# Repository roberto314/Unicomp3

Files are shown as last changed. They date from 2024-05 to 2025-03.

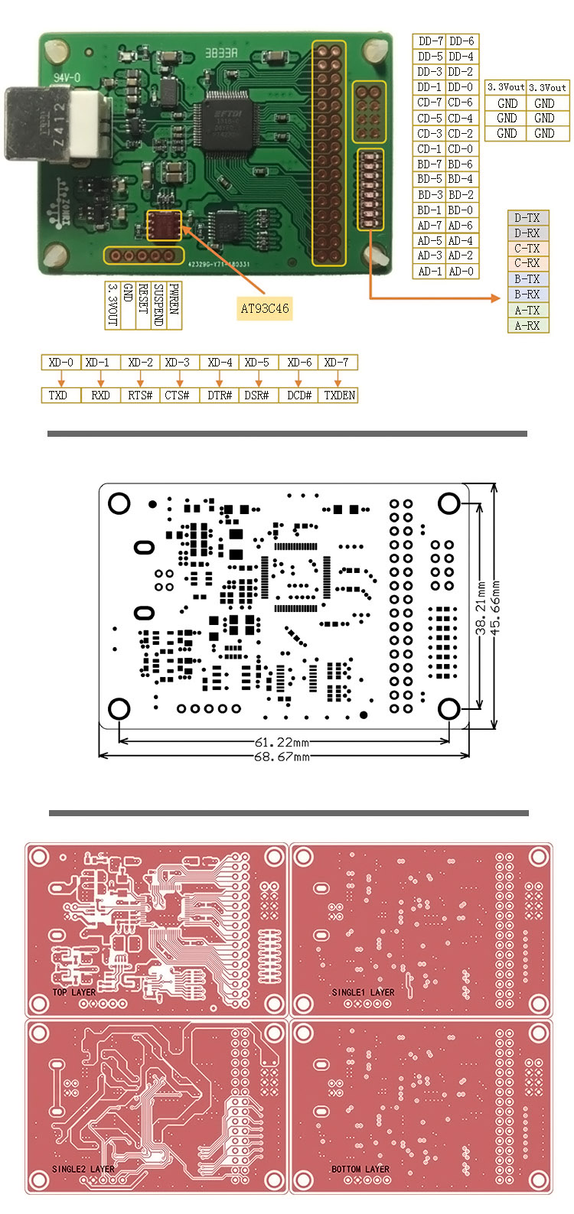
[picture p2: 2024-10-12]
various/Datasheets/FT4232 USB Serial/62949-01.jpg

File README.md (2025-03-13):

# UNICOMP #

Version 3.00

A modular 8-bit Computer able to recreate (nearly) every microcomputer of the mid 70s to early 80s 
in Hardware without FPGAs (although an FPGA can be added). Can also be used as a teaching tool for:

* VHDL or Verilog
* C
* RTOS (STM32F401 runs ChibiOS. Link: https://www.chibios.org)
* Python
* bash and linux in general (Olimex board runs linux with fbterm and tmux)
* Harwaredesign
* Timing of CPUs
* maybe Assembler
* SPI and I2C Interfaces
* CPLDs and FPGAs

It is different from other designs because of these points:

* it uses a 3.3V only Bus,
* it uses fast RAM for 16 chipselect outputs with single address resolution over the whole 1MB range,
* it uses one SRAM for RAM and ROM replacement (can be write writeprotected) with 1MB,
* it uses a clock generator chip (DS1085) - no more crystals to change,
* it is configureable via STM32 (RAM and ROM content, Clock frequency, chip select lines),
* it can program the CPLDs (only XC9572 and XC9536 tested) from the STM32, no external programmer needed.
* Board size is 100mm x 100mm - no backplane (like the PC/104 standard. Link: https://en.wikipedia.org/wiki/PC/104).
* and maybe most convenient: it can change RAM and ROM content on the fly without crashing the CPU. 
  For example starting the Apple I, going into Basic and uploading the program in about half a second is really nice.

Unicomp plus Logic Analyzer:
Unicomp plus Logic analyzer

### Unicomp modules ###

* USB-Serial board:
	- a simple board with an universal 4x USB to UART module from ebay (FT4232).

* CPU board:
	- can be any 8-bit CPU (6502, 6802, 6809, 68008, 6803, 8051,...)
	- a CPLD (XC9572) for clock generation and glue logic

* Multi Serial boaŕd:
	- suggested chip select #0
	- can be used with the following serial interface chips: MC6850, MOS6551, MOS6552 or pin compatible

* Multi Parallel boaŕd:
	- suggested chip select #1
	- can be used with the following parallel interface chips: MC6820, MC6821, MOS6520, MOS6521, MOS6522, MOS6526, MOS8520, MOS6532 in the first slot
    - the first slot can additionally mimic a MOS6530
	- the second slot can accommodate a MOS6522 or pin compatible

* RAMROM board:
	- chip select fixed at #15 (for chipselect RAM or ROM) and #14 for Write Disable (High for ROM),
	- 1M of SRAM plus an extra 16-bit RAM for address decoding,
	- a STM32F401 'blackpill' board to fill the SRAMs with data over USB,
	- USB shell on the STM32 to change ROM content on the fly,
	- also configures the Address Range of all peripheral modules,
	- acts as a XSVF Player to program the CPLDs

* Prototype board:
	- empty board for prototyping
	- no CPLD

* MAX-II (EPM240) board:
	- CPLD plus Buffers

* self made module:
	- chip select can be any non-used line in the Range from 0 to 13.
	- size is 100mm x 100mm
	- there is the prototype board in the repository for the position of the connectors and also the labels (pinout)

### Configuration RAM ###

The configuration is done with 1Mx16 fast ram on the RAMROM board. It is configured from the STM32F401.
The cs = 15 is for writing the main RAM, cs = 14 is the Write Disable.
The rest is free.

### Working Recreations of old computers (tested again with Unicomp3) ###

| Name | prim. IO | chips used | os | weblink |
|---|---|---|---|---|
| Motorola MEK D2 | serial | MC6802, MĆ6850 | newbug, xswtbug, mondeb |Link: https://www.retrotechnology.com/restore/smithbug.html |
| Motorola MEK D1 | serial | MC6802, MĆ6821 (plus Arduino) | Mikbug |Link: https://www.retrotechnology.com/restore/smithbug.html |
| SWTPC 6800 | serial | MC6802, MĆ6821 (plus Arduino) | Mikbug |Link: https://deramp.com/swtpc.com/ |
| SWTPC 6800 | serial | MC6802, MĆ6850 | SWTBUG, SWTBUGA, Mondeb, xSWTBUG |Link: https://deramp.com/swtpc.com/ |
| Heathkit ET3400 | serial | MC6802, MĆ6850 | MITS BASIC, TSC MicroBASIC,... |Link: https://github.com/jefftranter |
| HD6303 Board (Eric Klaus)| serial | HD6303 or MC6803 | Monitor +BASIC |Link: https://sites.google.com/site/ericmklaus/projects-1/hd6303cpuboard |
| MC3 Computer | serial | HD6303 or MC6803 | Monitor |Link: https://www.waveguide.se/?article=mc3-a-diy-8-bit-computer |
| Grant Searle 6809 board  | serial | MC6809E, MC6850 | MS Basic |Link: http://searle.x10host.com/6809/Simple6809.html |
| Grant Searle 6502 board  | serial | MOS6502, MC6850 | OSI Basic |Link: http://searle.x10host.com/6502/Simple6502.html |
| Daryl Rictor 6502 board  | serial | MOS6502, R6551 | SBC-2 (monitor only) |Link: https://sbc.rictor.org/info2.html |
| Daryl Rictor 6502 board  | serial | MOS6502, MC6850 | SBC-2 (monitor only) |Link: https://sbc.rictor.org/info2.html |
| SYM1 | serial | MOS6502, UM6532 | SYM1 ( +BASIC +RAE) |Link: http://retro.hansotten.nl/6502-sbc/synertek-sym-ktm/sym-1/ |
| KIM1 | serial | MOS6502, UM6532 | KIM1 |Link: http://retro.hansotten.nl/6502-sbc/kim-1-manuals-and-software/ |
| Apple I | serial | MOS6502, MĆ6821 (plus Arduino)| Wozmon + BASIC |Link: http://retro.hansotten.nl/6502-sbc/apple-1/ |
| DREAM 6800 | BAS (Video) | MC6802, MAX-II | DREAM operating System (Chip8) |Link: http://www.mjbauer.biz/DREAM6800.htm |
| Psion Organizer I | LCD | HD6303 | Psion OS |Link: https://www.jaapsch.net/psion/index.htm |

### python helper scripts ###

* UC3_upload.py: multi-function script. up- or download RAM Content, write or read the clock chip, set the reset pin, upload configuration data from file, upload RAM data from file, gets version number, 

* UC3_make_uploadfile.py: creates an .ucb file for upload. It can have multiple RAM locations and lengths.

### CPLD programming ###

* compiling the vhdl (or verilog) code must be done on a computer with the Xilinx ISE 14.7 toolchain installed.
 Link: https://www.xilinx.com/support/download/index.html/content/xilinx/en/downloadNav/vivado-design-tools/archive-ise.html

* compiling itself can be done inside ISE or with the supplied makefile (look inside the bord directory in cpld firmware)

* a simple **make** will compile the firmware and a **make prog** will transfer the file to the stm32 for programming.

### Used Software and OS ###

* Linux Mint (21.3 cinnamon) (Link: https://linuxmint.com/)
* Sublime Text 3 (Link: https://www.sublimetext.com/)
* 010 Editor (Hex Editor) (Link: https://www.sweetscape.com/010editor/)
* Chibi Studio 20 (IDE for ChibiOS) (Link: https://www.chibios.org/dokuwiki/doku.php?id=chibios:products:chibistudio:start)
* Wavedrom (2.9.1) (Link: https://wavedrom.com/)
* Pulseview (0.5.0-nightly Appimaage) (Part of sigrok) (Link: https://sigrok.org/wiki/PulseView)
* Logisim-Evolution (3.8.0) (Link: https://github.com/logisim-evolution/logisim-evolution)
* Quartus (13.0.1 Build232 Web Edition - 64 Bit) for MAX-II
* Xilinx ISE (14.7 - 64 Bit) for XC9572

### Used Hardware ###

* Oscilloscope: Rigol DS1054Z (4 channel)
* Logic Analyzer: Hantek 4032L (32 channel)

### History Lesson ###

The unicomp Project started a couple of years ago and is developed in my spare time. It is intended to be a module system to test out different hardware configurations or CPLD- or FPGA- extensions and to recreate old systems and test software and operating systems.

Differences Unicomp2 from Unicomp1:

* chipselect not with CPLD but with RAM on every peripheral board - more flexible,
* chipselect resolution improved to two,

Differences Unicomp3 from Unicomp2:

* chipselect RAM is on RAMROM Board (16-bit wide) - that leads to:
* simpler (and cheaper) peripheral modules,
* no linux SBC needed,
* CPLD programming from STM32 or with external programmer (JTAG Header on every CPU Module)
* 3.3V Supply on RAMROM board,
* RAM has now a backup battery (CR2032) battery,
* improved documentation.

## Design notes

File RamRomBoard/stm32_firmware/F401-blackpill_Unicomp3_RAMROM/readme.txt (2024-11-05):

*****************************************************************************
** ChibiOS/RT port for ARM-Cortex-M4 STM32F407.                            **
*****************************************************************************

** TARGET **

The demo runs on an STM32F411 or STM32F401 blackpill board.
(25MHz Crystal)
Serial Port over USB (also Debug Interface).
Serial 115200 Bd

Build:
Build with eclipse or simply type "make" in the code folder.

Functions:

Pinout:
PA0  - JTAG - TDO
PA1  - /PLD (Parallel Load into Shift Register)
PA2  - TX2 (Console + Debug)
PA3  - RX2 (Console + Debug)
PA4  - /BW (Battery Warning out or Chip Enable in)
PA5  - SCK1
PA6  - MISO1
PA7  - MOSI1
PA8  - DET_SD (SD Card Detect)
PA9  - /STM32BUS
PA10 - /EXTRESET (Reset Target)
PA11 - USD DM (Ostrich)
PA12 - USB DP (Ostrich)
PA13 - SWDIO
PA14 - SWCLK
PA15 - CNT

PB0  - /CEDAT_EN (Enable Data for CE RAM)
PB1  - /MRAM_WR (Write Pulse for Main RAM)
PB2  - /DATOE (Data Output Enable from Main RAM)
PB3  - /MRC (Clear Address Counter)
PB4  - CLK1 - PWM Output (TIM3/1) (Clock 1Hz)
PB5  - /CNTOE (Output Enable for Address Counter)
PB6  - SCL (used for Clock Chip DS1085)
PB7  - SDA (used for Clock Chip DS1085)
PB8  - CTRL1 (CTRL1 for clock chip)
PB9  - /BUSFREE (signal if bus is free)
PB10 - TRST (Target Reset)

PB12 - /CS_SD (SD Card Chipselect)
PB13 - SCK_SD
PB14 - MISO_SD
PB15 - MOSI_SD

PC13 - JTAG - TDI
PC14 - JTAG - TMS
PC15 - JTAG - TCK

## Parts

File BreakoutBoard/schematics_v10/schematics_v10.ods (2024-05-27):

Id | Designator | Footprint | Quantity | Designation | Supplier and ref
21 | U1 | TQFP-44_10x10mm_P0.8mm | 1 | XC9572VQ44
23 | U2 | DIP-14_W7.62mm_Socket | 1 | 74HC14
 |  | Sockets and Headers
1 | J14,J13,J16,J28,J30,J29,J15 | PinHeader_1x01_P2.00mm_Vertical | 7 | .
2 | U4 | DIP-40_W15.24mm_Socket_LongPads | 1 | W65C22NxP
3 | J8,J5 | PinHeader_1x09_P2.54mm_Vertical | 2 | Conn_01x09
4 | J18,J19 | PinHeader_1x32_P2.54mm_Vertical | 2 | Conn_01x32
5 | J1,J4,J2,J3 | PinSocket_2x20_P2.54mm_Vertical | 4 | BUS
6 | J27 | PinHeader_2x05_P2.54mm_Vertical | 1 | .
8 | J12,J9 | PinHeader_1x01_P2.00mm_Vertical | 2 | Conn_01x01
9 | J26 | PinHeader_1x01_P2.00mm_Vertical | 1 | .Conn_01x01
10 | JP3,JP4,JP5,JP6,JP2,JP1 | PinHeader_1x03_P2.54mm_Vertical | 6 | .
13 | J17 | PinHeader_2x11_P2.54mm_Vertical | 1 | Conn_02x11_Odd_Even
14 | J10,J11 | PinHeader_1x06_P2.54mm_Vertical | 2 | .
15 | J20,J21 | PinHeader_1x12_P2.54mm_Vertical | 2 | Conn_01x12
16 | J6,J7 | PinHeader_1x08_P2.54mm_Vertical | 2 | Conn_01x08
20 | U3 | DIP-40_W15.24mm_Socket_LongPads | 1 | 6532
22 | A1 | Arduino_Nano | 1 | Arduino_Nano_v3.x
 |  | R and C
17 | C3,C1,C2,C7,C8,C6 | C_1206_3216Metric | 6 | 100n
19 | C4 | C_1206_3216Metric | 1 | 10n
7 | R1 | R_1206_3216Metric_Pad1.30x1.75mm_HandSolder | 1 | 1k

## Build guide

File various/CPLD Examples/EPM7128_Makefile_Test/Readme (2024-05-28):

Just type make to build and make clean to clean up.
For your own implementation modify the following files:
Makefile Line 8,9 and maybe Line 14 or 15
$(PROJECT)_pins.qsf for the Pin assignments
$(PROJECT).vhd obviously

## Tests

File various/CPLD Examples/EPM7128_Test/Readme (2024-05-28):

Just type make to build and make clean to clean up.
For your own implementation modify the following files:
Makefile Line 8,9,65 and maybe Line 14,15,56
$(PROJECT)_pins.qsf for the Pin assignments
$(PROJECT).vhd obviously

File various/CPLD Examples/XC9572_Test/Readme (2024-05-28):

Just type make to build and make clean to clean up.
For your own implementation modify the following files:
Makefile Line 10 and maybe Line 11,12,31,46,58
$(PROJECT).ucf for the Pin assignments
$(PROJECT).vhd obviously

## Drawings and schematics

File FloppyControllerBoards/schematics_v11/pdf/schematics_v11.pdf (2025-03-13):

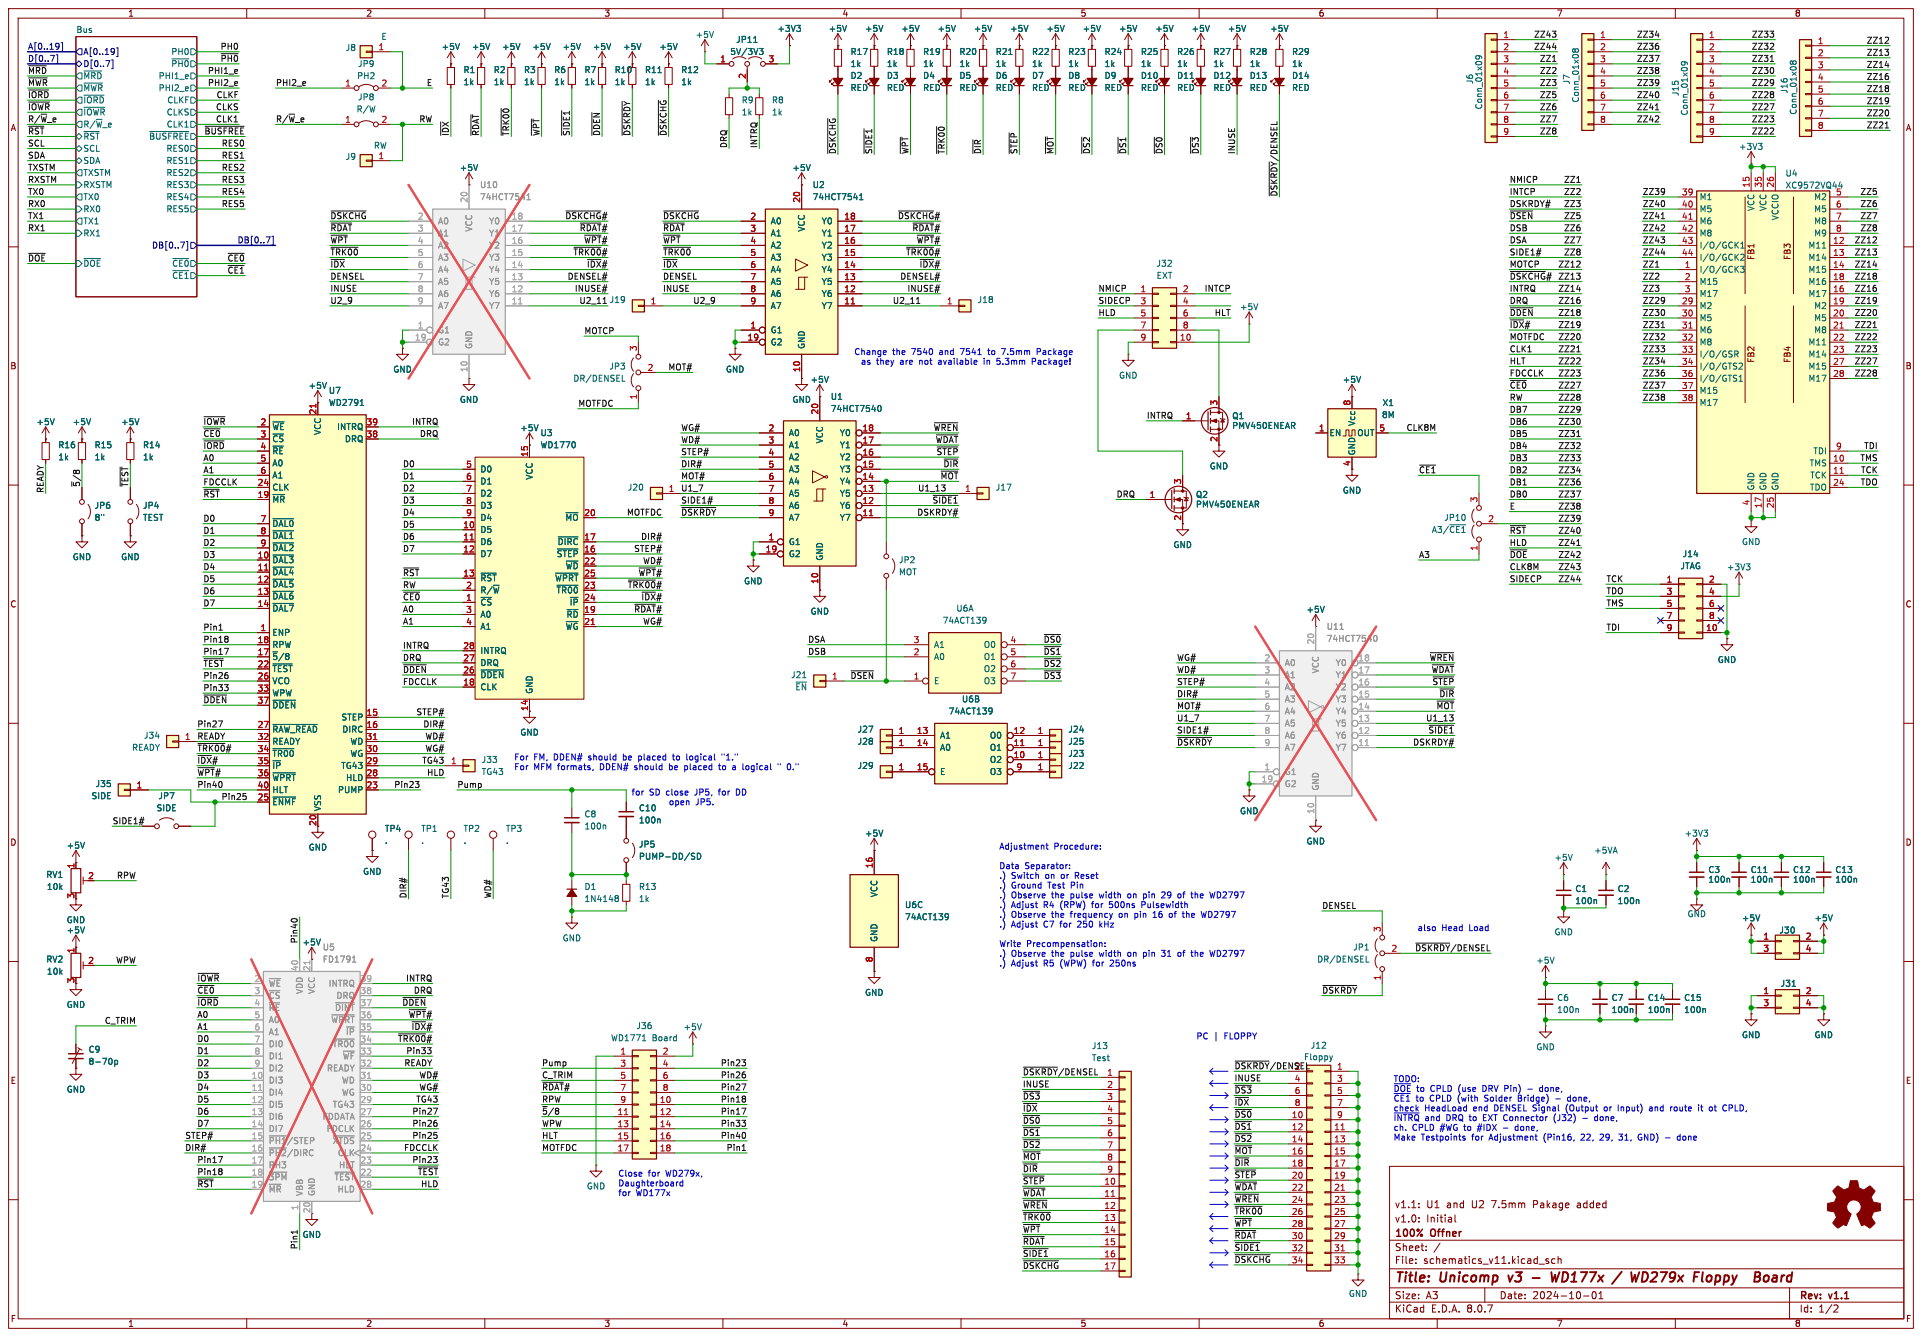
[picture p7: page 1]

4 OUT 5 Vcc 8 GND GND

3 +5V U3 WD1770 ~{CS} 1 D5 10 D6 11 D7 12 ~{RST} 13 GND 14 VCC 15

.) Switch on or Reset
.) Ground Test Pin
.) Observe the pulse width on pin 29 of the WD2797
.) Adjust R4 (RPW) for 500ns Pulsewidth
.) Adjust C7 for 250 kHz Write Precompensation:

1 DI3 10 DI4 11 DI5 12 DI6 13 DI7 14 ~{PH1}/STEP 15 ~{PH2}/DIRC 16 PH3 17 ~{3PM} 18 ~{MR} 19 ~{WE} 2 GND 20 VCC 21 ~{TEST}22 HLT 23 CLK 24 ~{XTDS}25 FDCLK 26 FDDATA 27 HLD 28 TG43 29 ~{CS} 3 WG 30 WD 31 READY 32 ~{WF}33 ~{TR00}34 ~{IP}35 ~{WPRT}36 ~{DINT}37 DRQ 38

.) Observe the pulse width on pin 31 of the WD2797

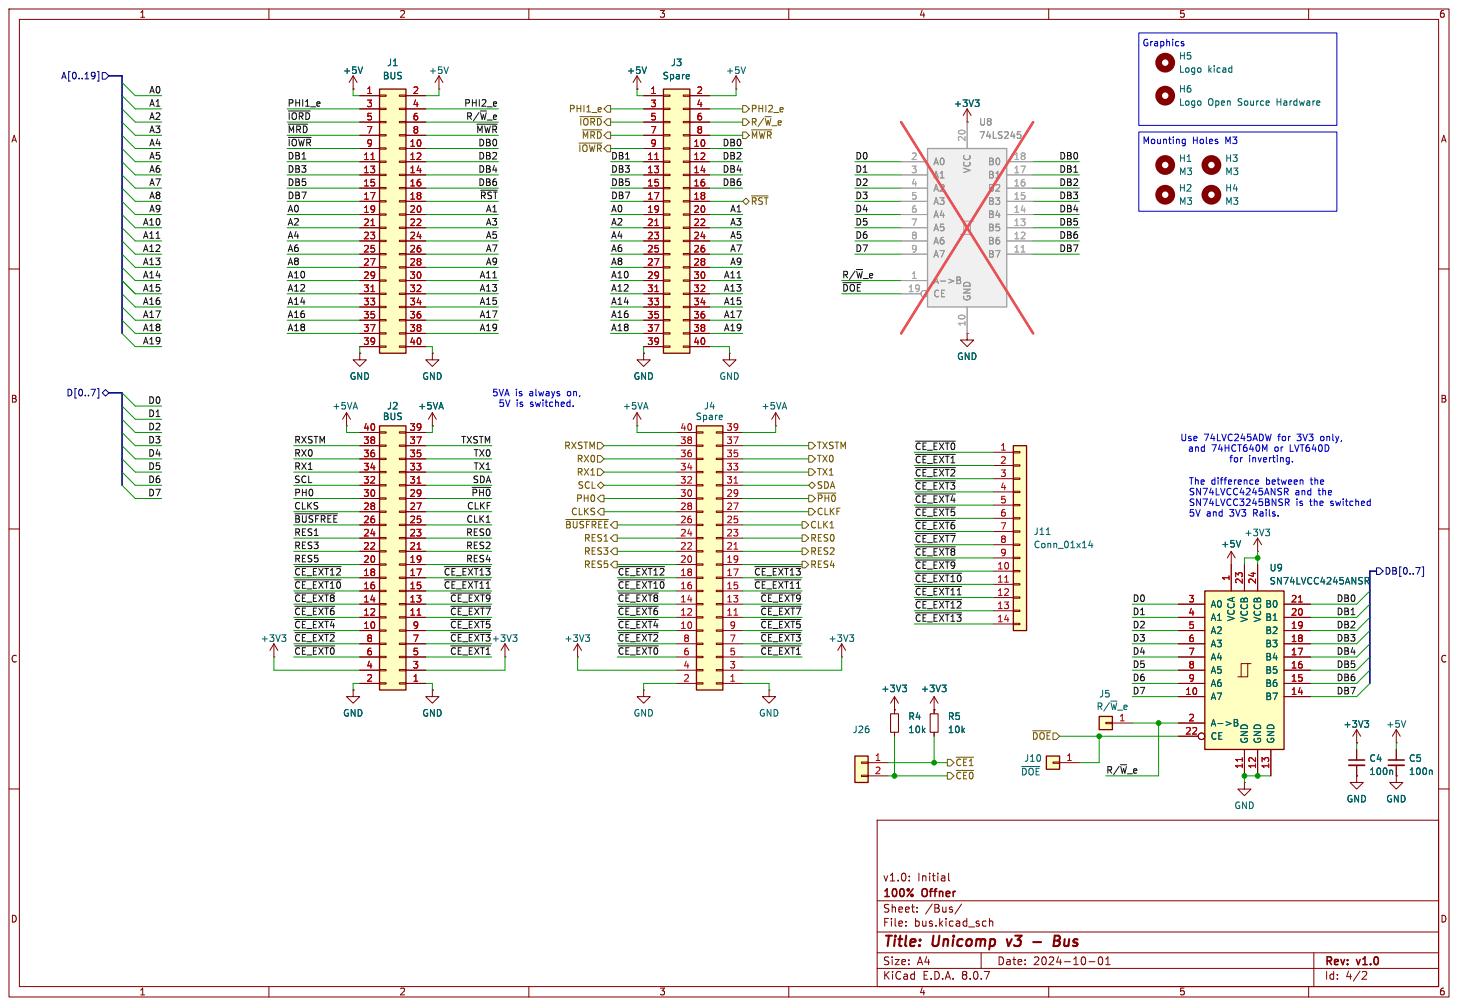
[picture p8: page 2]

Logo Open Source Hardware H5

1 A7 10 GND 11 GND 12 GND 13 B7 14 B6 15 B5 16 B4 17 B3 18 B2 19 A->B 2 B1 20 B0 21 CE 22 VCCB 23 VCCB 24 A0 3 A1 4 A2 5 A3 6 A4 7 A5 8 A6 9 U9SN74LVCC4245ANSR

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

Id: 4/2 Title: Unicomp v3 - Bus

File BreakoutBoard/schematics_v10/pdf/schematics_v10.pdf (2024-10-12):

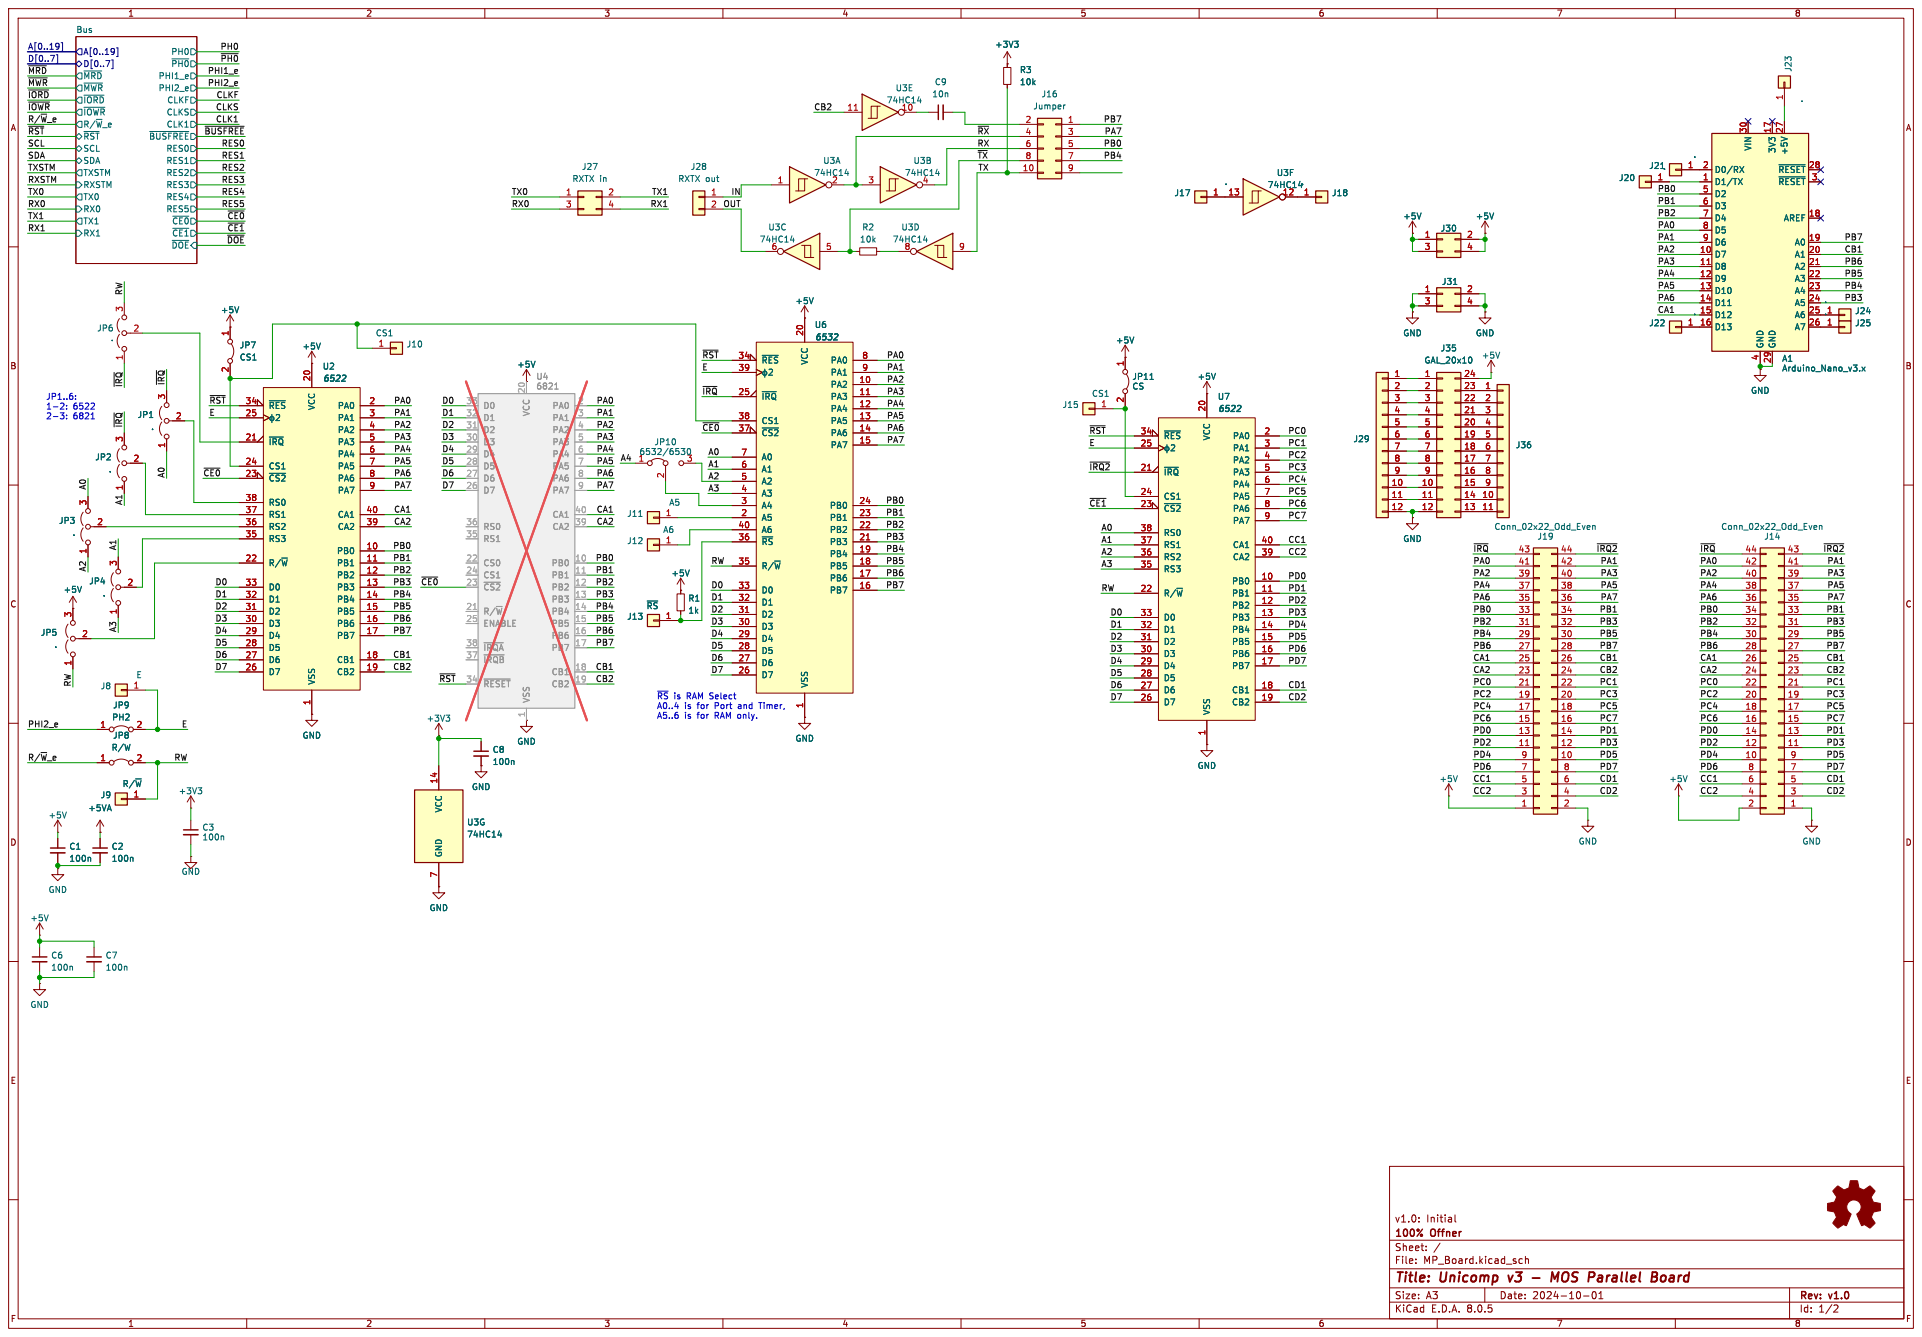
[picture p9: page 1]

1 PA2 10 PA3 11 PA4 12 PA5 13 PA6 14 PA7 15 PB7 16 PB6 17 PB5 18 PB4 19 A5 2 VCC 20 PB3 21 PB2 22 PB1 23 PB0 24 ~{IRQ} 25 D7 26 D6 27 D5 28 D4 29 A4 3 D3 30 D2 31 D1 32 D0 33 ~{RES} 34 R/~{W} 35 ~{RS} 36 ~{CS2} 37 CS1 38

Id: 1/2 Title: Unicomp v3 - MOS Parallel Board

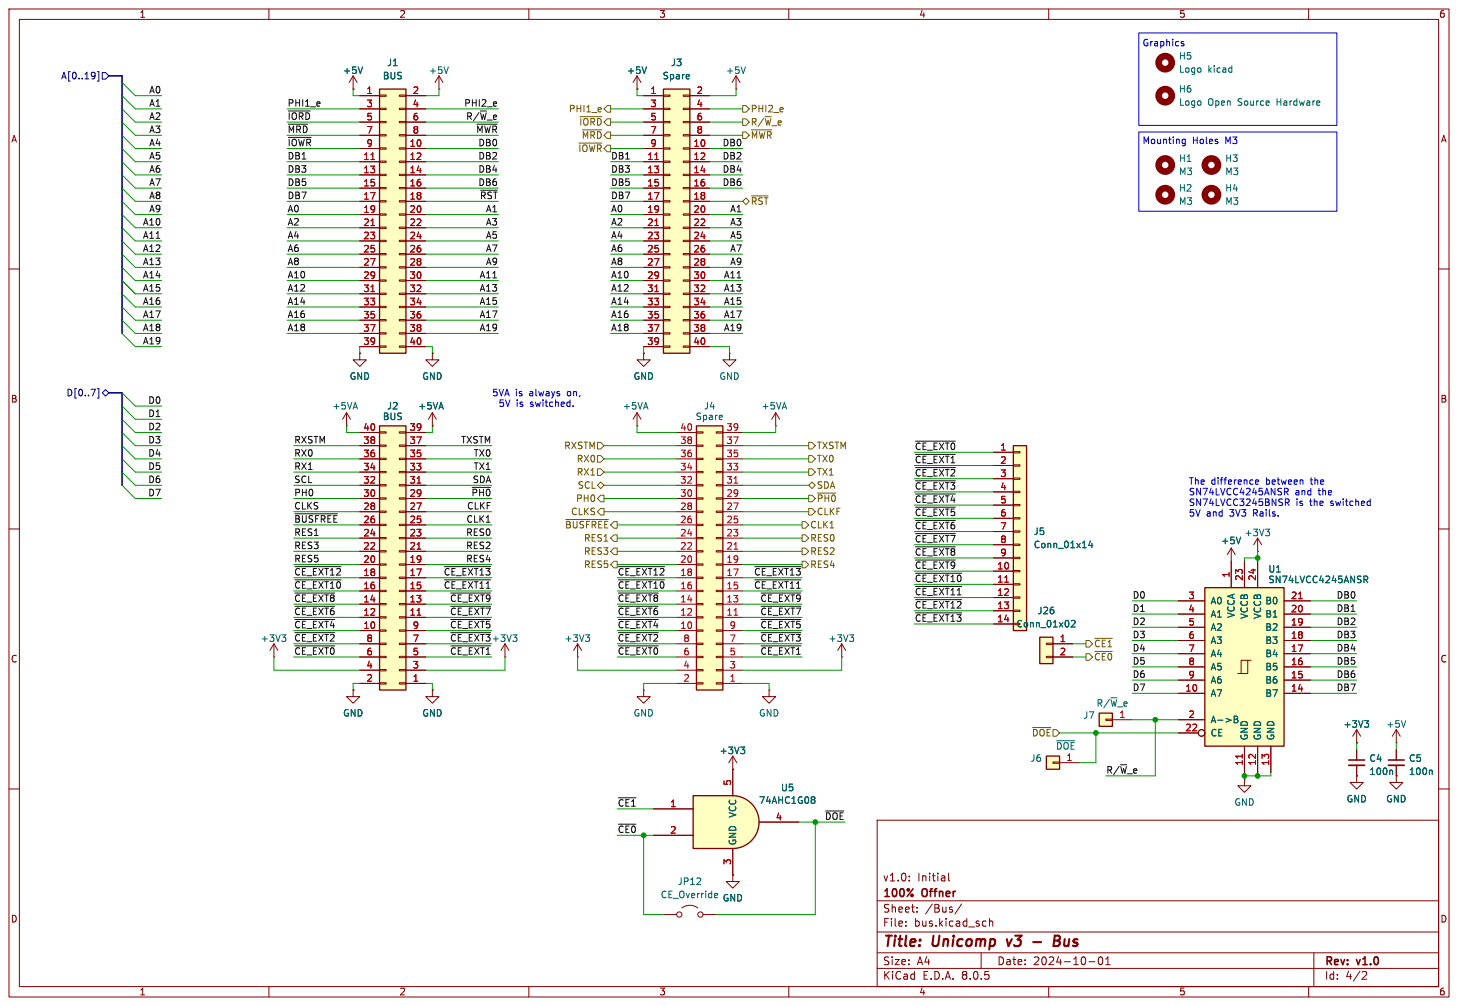
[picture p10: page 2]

Logo Open Source Hardware H5
Logo kicad

1 A7 10 GND 11 GND 12 GND 13 B7 14 B6 15 B5 16 B4 17 B3 18 B2 19 A->B 2 B1 20 B0 21 CE 22 VCCB 23 VCCB 24 A0 3 A1 4 A2 5 A3 6 A4 7 A5 8 A6 9 U1SN74LVCC4245ANSR GND

1 A7 10 GND 11 GND 12 GND 13 B7 14 B6 15 B5 16 B4 17 B3 18 B2 19 A->B 2 B1 20 B0 21 CE 22 VCCB 23 VCCB 24 A0 3 A1 4 A2 5 A3 6 A4 7 A5 8 A6 9 U5

Id: 4/2 Title: Unicomp v3 - Bus

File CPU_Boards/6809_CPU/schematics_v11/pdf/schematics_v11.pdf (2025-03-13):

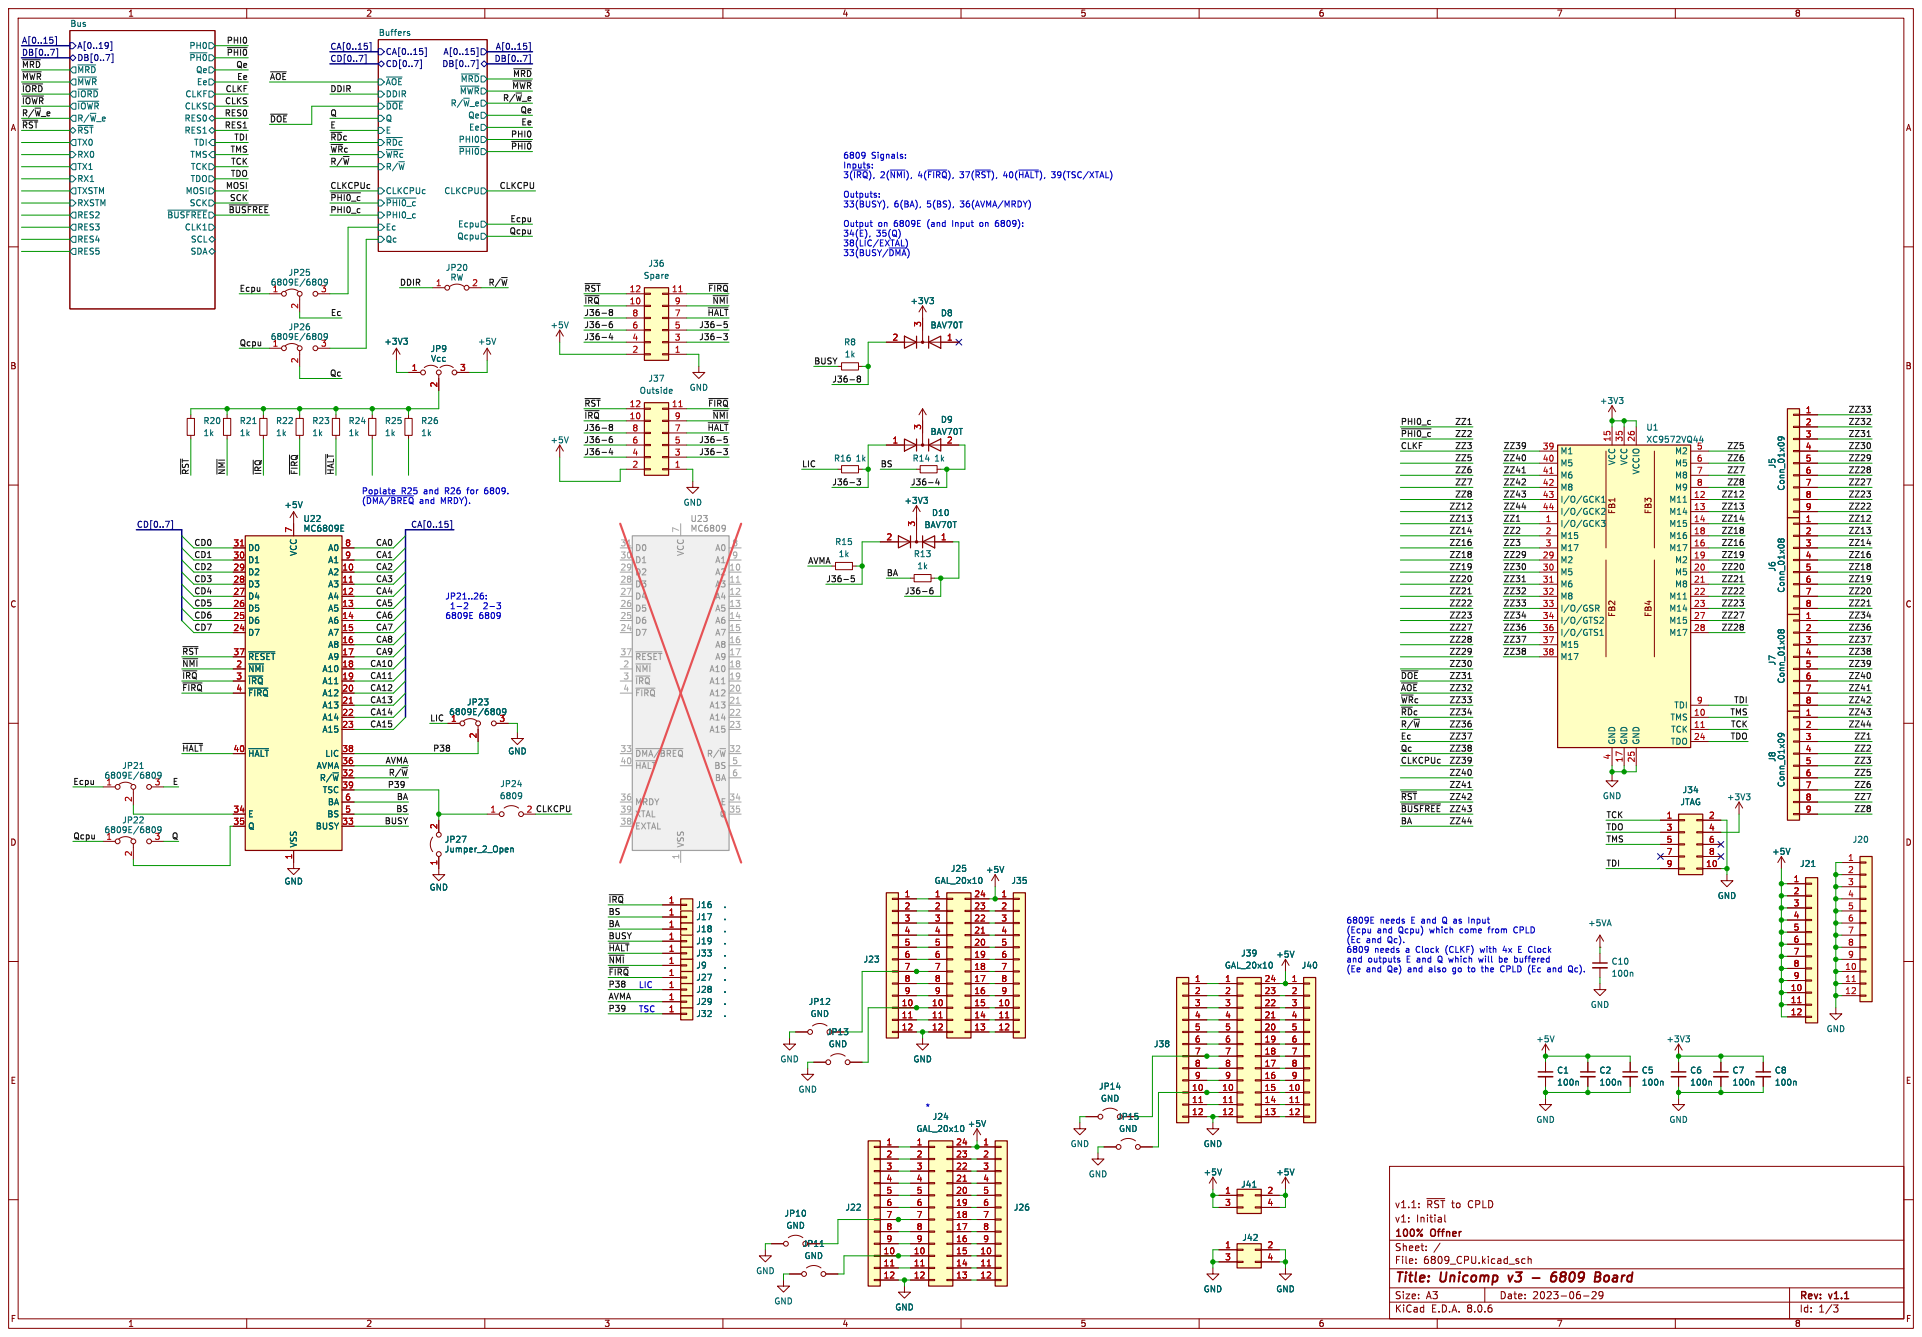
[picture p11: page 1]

6809 Signals:
Inputs:
3(~{IRQ}),2(~{NMI}),4(~{FIRQ}),37(~{RST}),40(~{HALT}),39(TSC/XTAL)

Outputs:
33(BUSY), 6(BA), 5(BS), 36(AVMA/MRDY)

Output on 6809E (and Input on 6809):
38(LIC/EXTAL)
33(BUSY/~{DMA})

1 A2 10 A3 11 A4 12 A5 13 A6 14 A7 15 A8 16 A9 17 A10 18 A11 19 ~{NMI} 2 A12 20 A13 21 A14 22 A15 23 D7 24 D6 25 D5 26 D4 27 D3 28 D2 29 ~{IRQ} 3 D1 30 D0 31 R/~{W}32 ~{DMA/BREQ} 33 E

6809E needs E and Q as Input
(Ecpu and Qcpu) which come from CPLD
(Ec and Qc). 6809 needs a Clock (CLKF) with 4x E Clock and outputs E and Q which will be buffered

(Ee and Qe) and also go to the CPLD (Ec and Qc).

Id: 1/3 Title: Unicomp v3 - 6809 Board

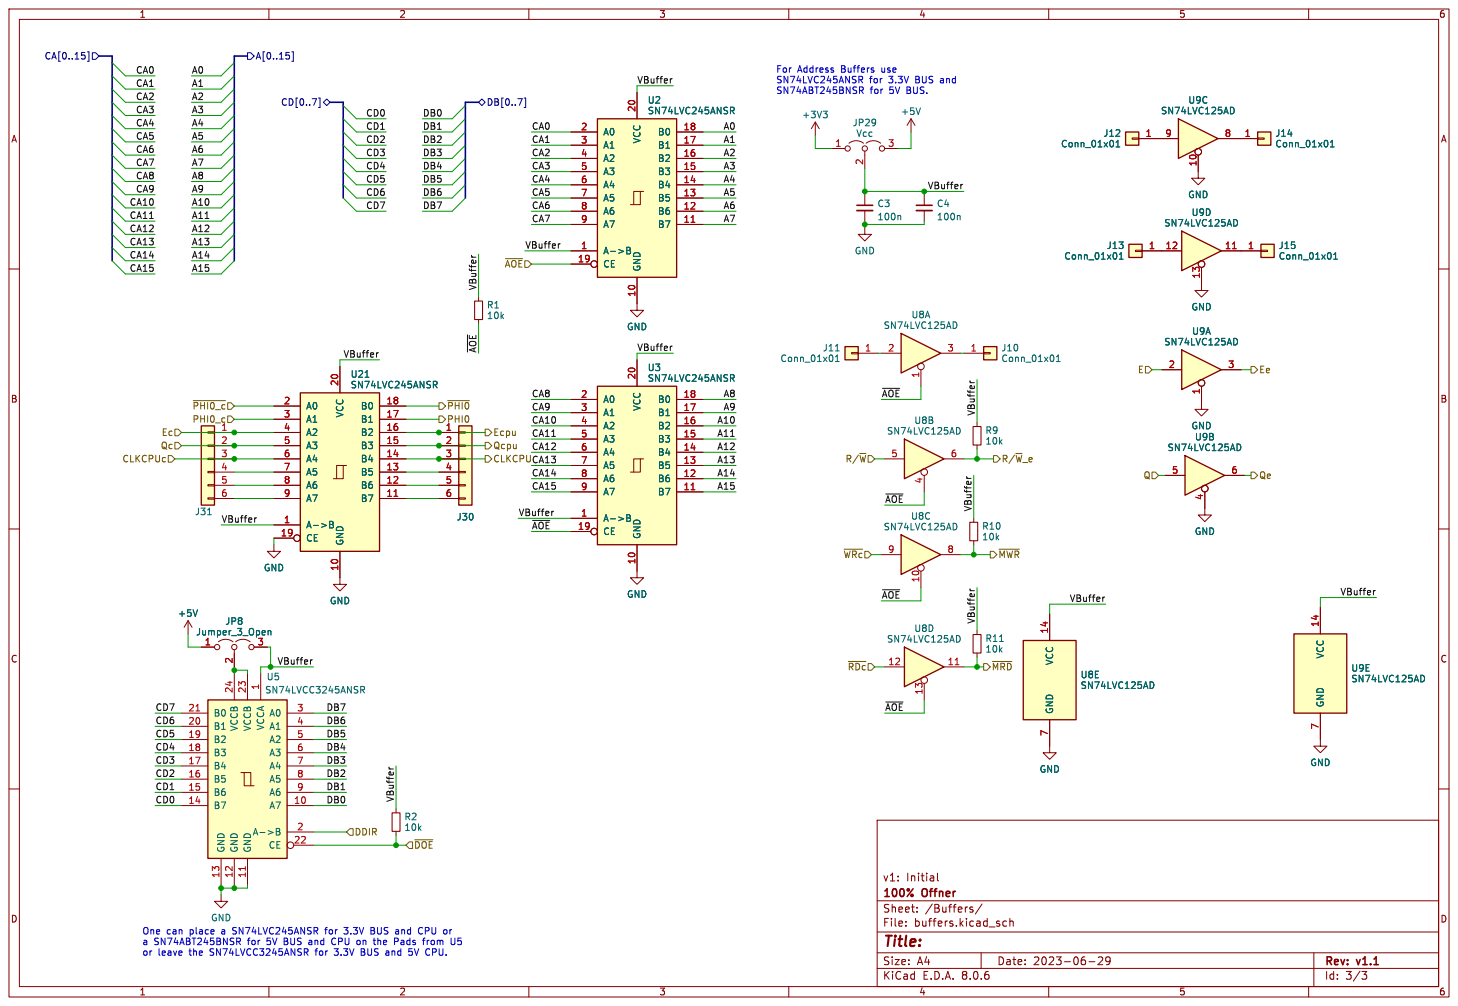
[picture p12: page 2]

1 A7 10 GND 11 GND 12 GND 13 B7 14 B6 15 B5 16 B4 17 B3 18 B2 19 A->B 2 B1 20 B0 21 CE 22 VCCB 23 VCCB 24 A0 3 A1 4 A2 5 A3 6 A4 7 A5 8 A6 9 U5 SN74LVCC3245ANSR

One can place a SN74LVC245ANSR for 3.3V BUS and CPU or a SN74ABT245BNSR for 5V BUS and CPU on the Pads from U5

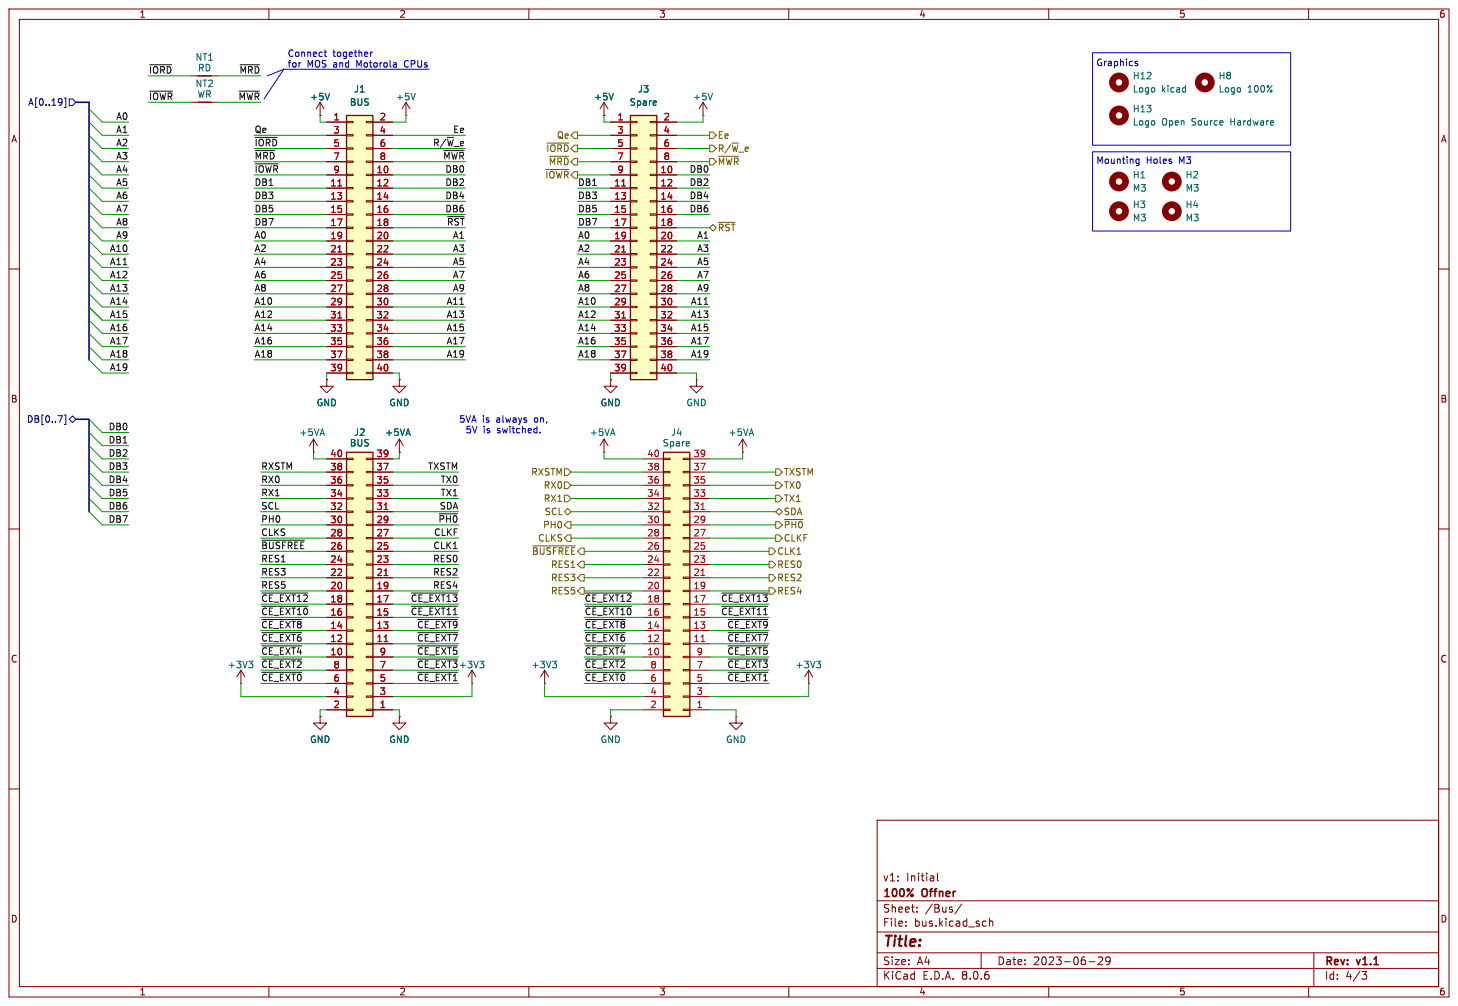
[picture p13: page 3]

Logo Open Source Hardware NT2 WR

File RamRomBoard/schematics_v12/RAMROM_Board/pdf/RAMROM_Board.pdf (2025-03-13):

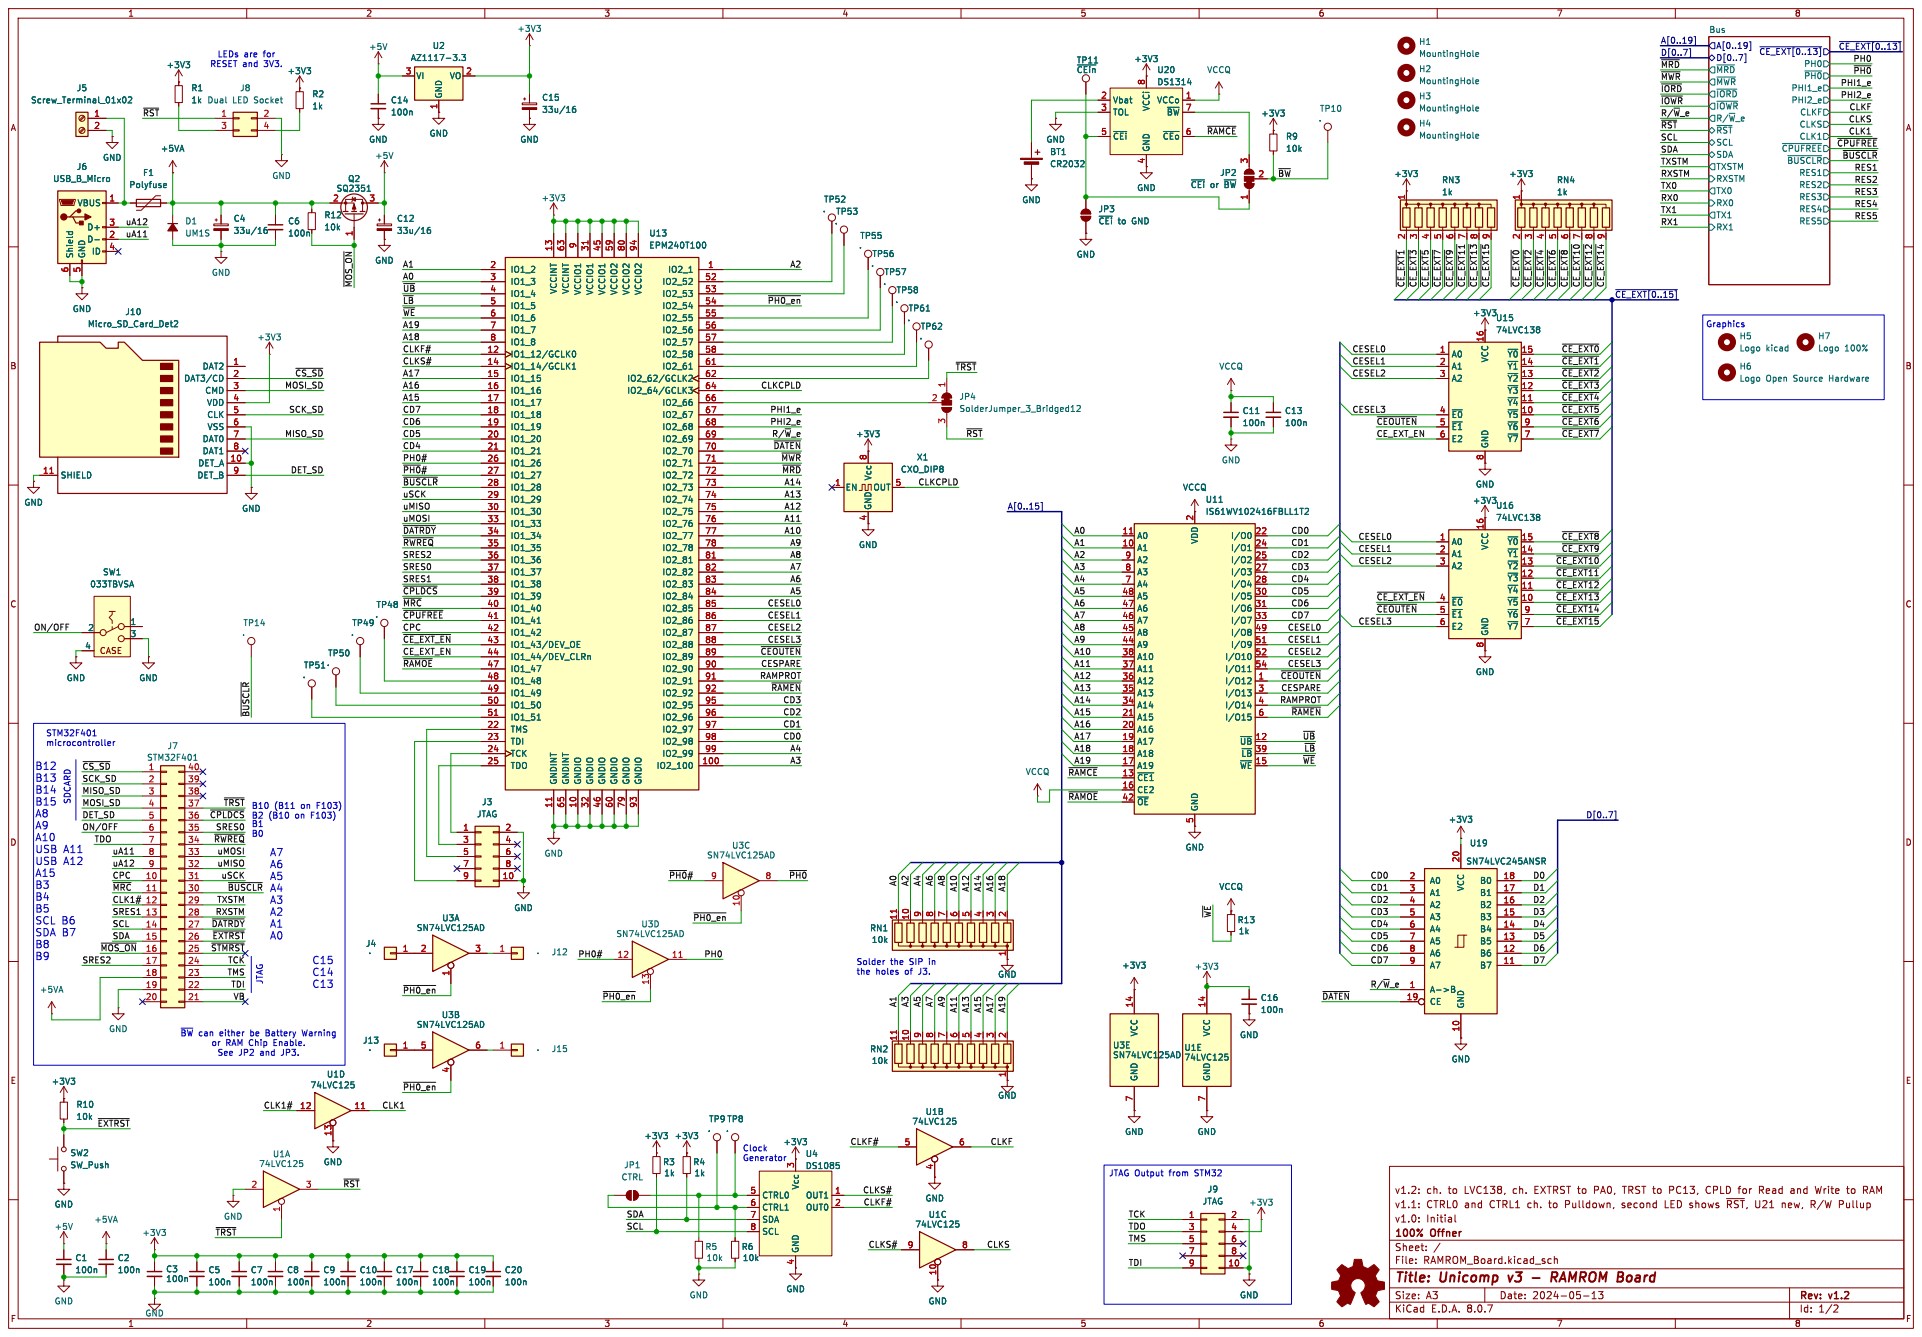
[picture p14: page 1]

J8 Dual LED Socket +3V3 F1 Polyfuse
+3V3 GND

LEDs are for RESET and 3V3.

4 ~{CEi} 5 ~{CEo}6 ~{BW} VCCi 7

JP2 ~{CEi}or ~{BW} JP3 ~{CEi}to GND

2 GND GND GND GND

Solder the SIP in

~{BW}can either be Battery Warning

Id: 1/2 Title: Unicomp v3 - RAMROM Board

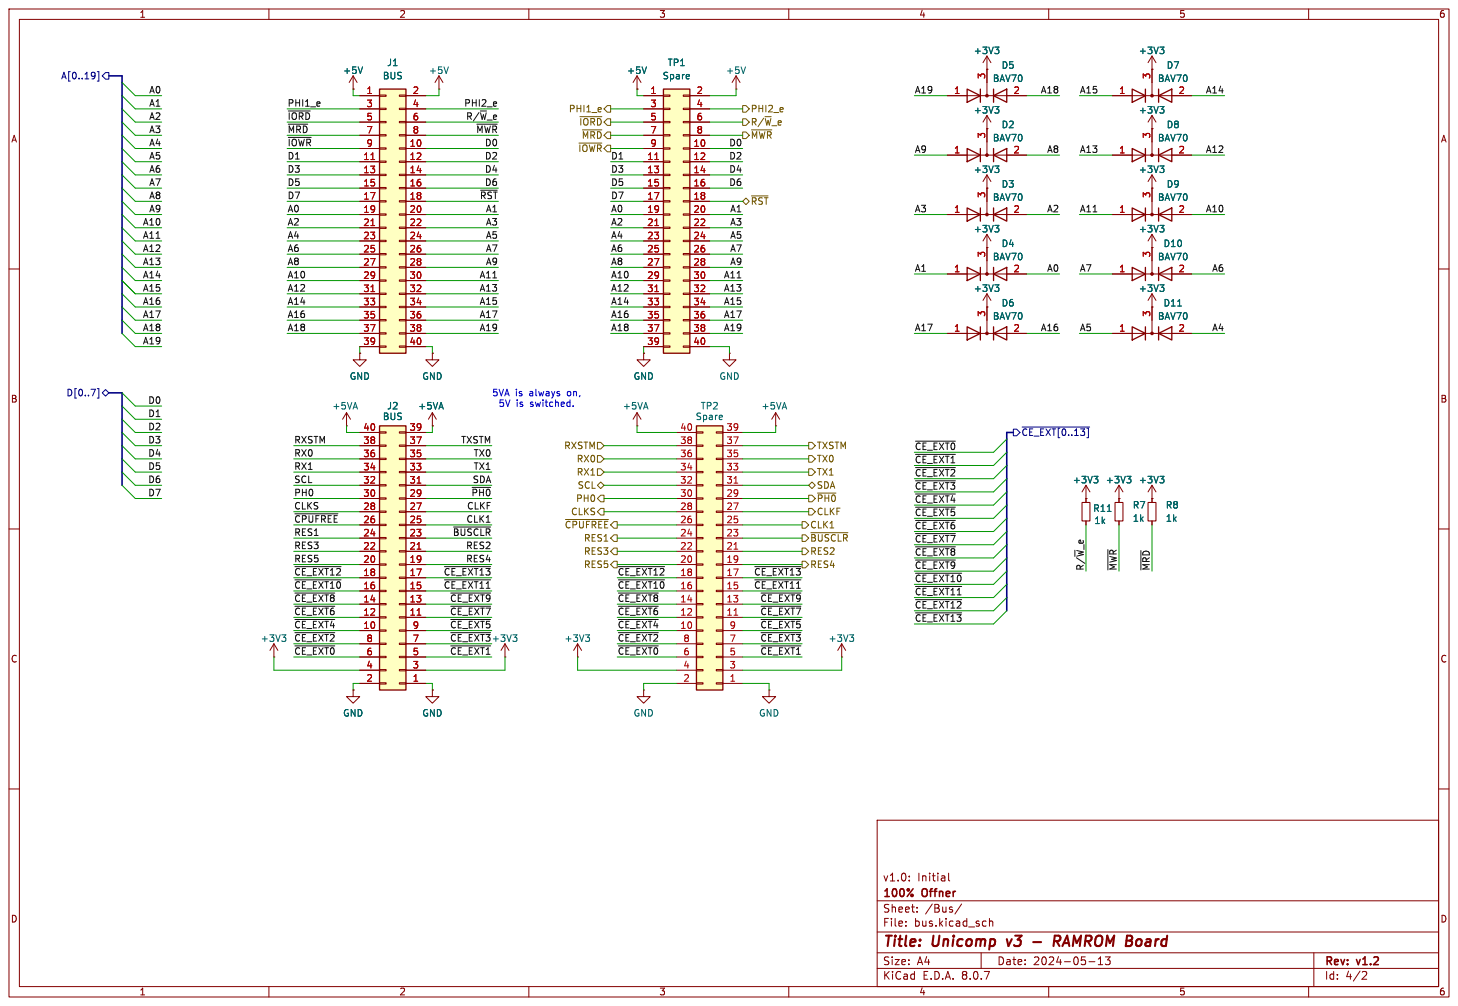
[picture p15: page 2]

Id: 4/2 Title: Unicomp v3 - RAMROM Board

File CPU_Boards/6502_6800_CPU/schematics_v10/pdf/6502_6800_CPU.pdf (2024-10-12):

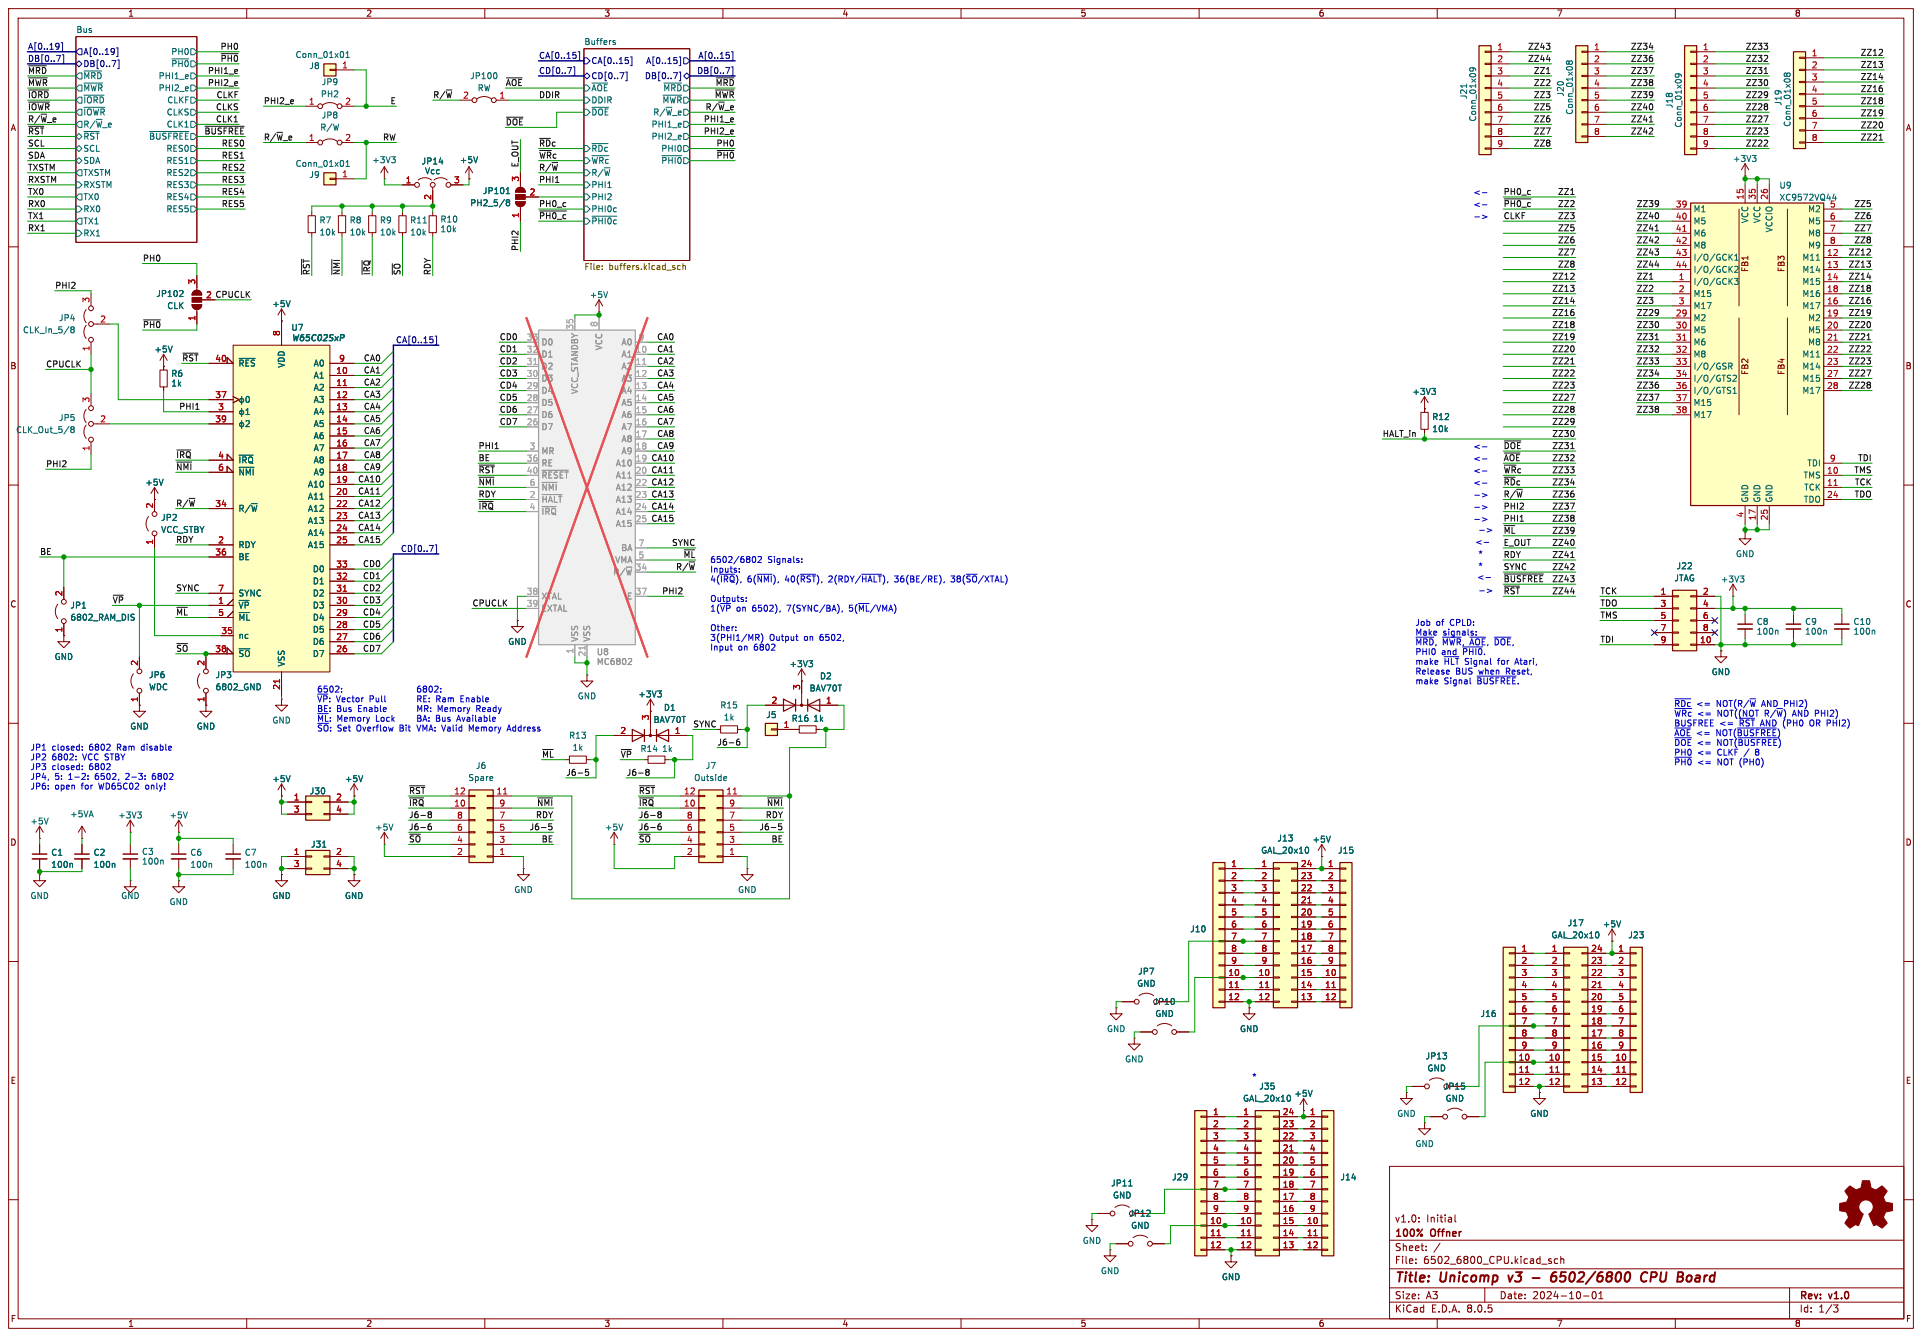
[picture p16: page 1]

1 A1 10 A2 11 A3 12 A4 13 A5 14 A6 15 A7 16 A8 17 A9 18 A10 19 ~{HALT} 2 A11 20 VSS 21 A12 22 A13 23 A14 24 A15 25 D7 26 D6 27 D5 28 D4 29 MR 3 D3 30 D2 31 D1 32 D0 33 R/~{W}34 VCC_STANDBY 35 RE 36 E

Job of CPLD: Make signals:

~{MRD},~{MWR},~{AOE},~{DOE}, PHI0 and ~{PHI0}. make ~{HLT}Signal for Atari, Release BUS when Reset, make Signal ~{BUSFREE}. JP1 closed: 6802 Ram disable

6802: RE: Ram Enable MR: Memory Ready BA: Bus Available VMA: Valid Memory Address

~{WRc}<= NOT((NOT R/~{W})AND PHI2) BUSFREE <= ~{RST}AND (PH0 OR PHI2)

~{AOE}<= NOT(~{BUSFREE})
~{DOE}<= NOT(~{BUSFREE}) PH0 <= CLKF / 8 ~{PH0}<= NOT (PH0)

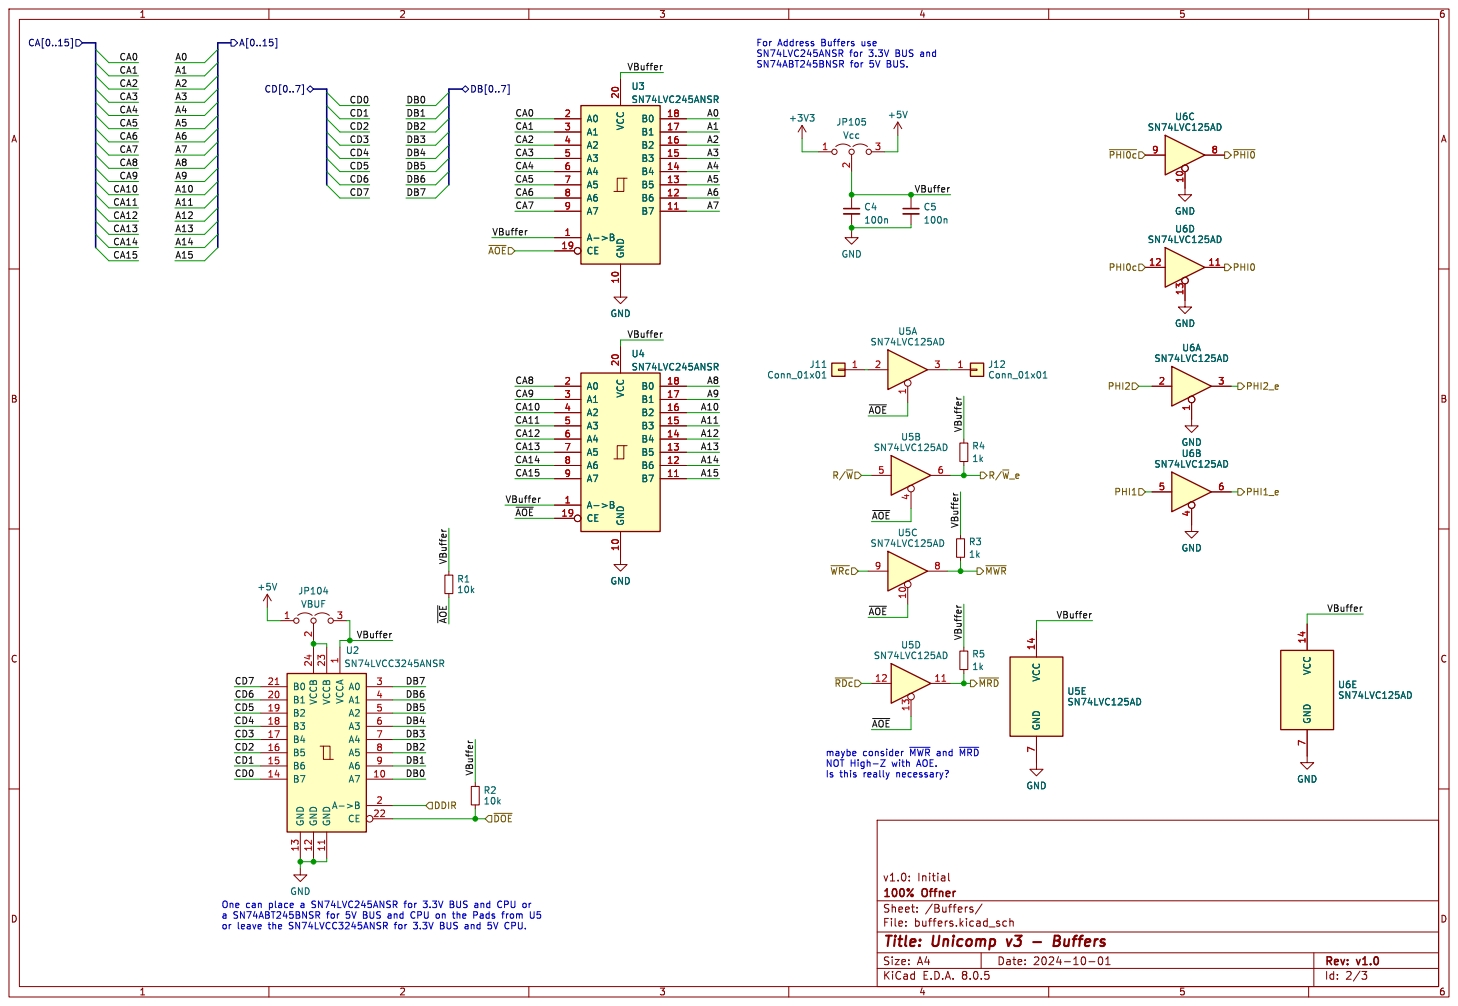
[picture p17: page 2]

For Address Buffers use SN74LVC245ANSR for 3.3V BUS and SN74ABT245BNSR for 5V BUS. U3SN74LVC245ANSR

1 A7 10 GND 11 GND 12 GND 13 B7 14 B6 15 B5 16 B4 17 B3 18 B2 19 A->B 2 B1 20 B0 21 CE 22 VCCB 23 VCCB 24 A0 3 A1 4 A2 5 A3 6 A4 7 A5 8 A6 9 U2 SN74LVCC3245ANSR

Is this really necessary? One can place a SN74LVC245ANSR for 3.3V BUS and CPU or a SN74ABT245BNSR for 5V BUS and CPU on the Pads from U5

Id: 2/3 Title: Unicomp v3 - Buffers

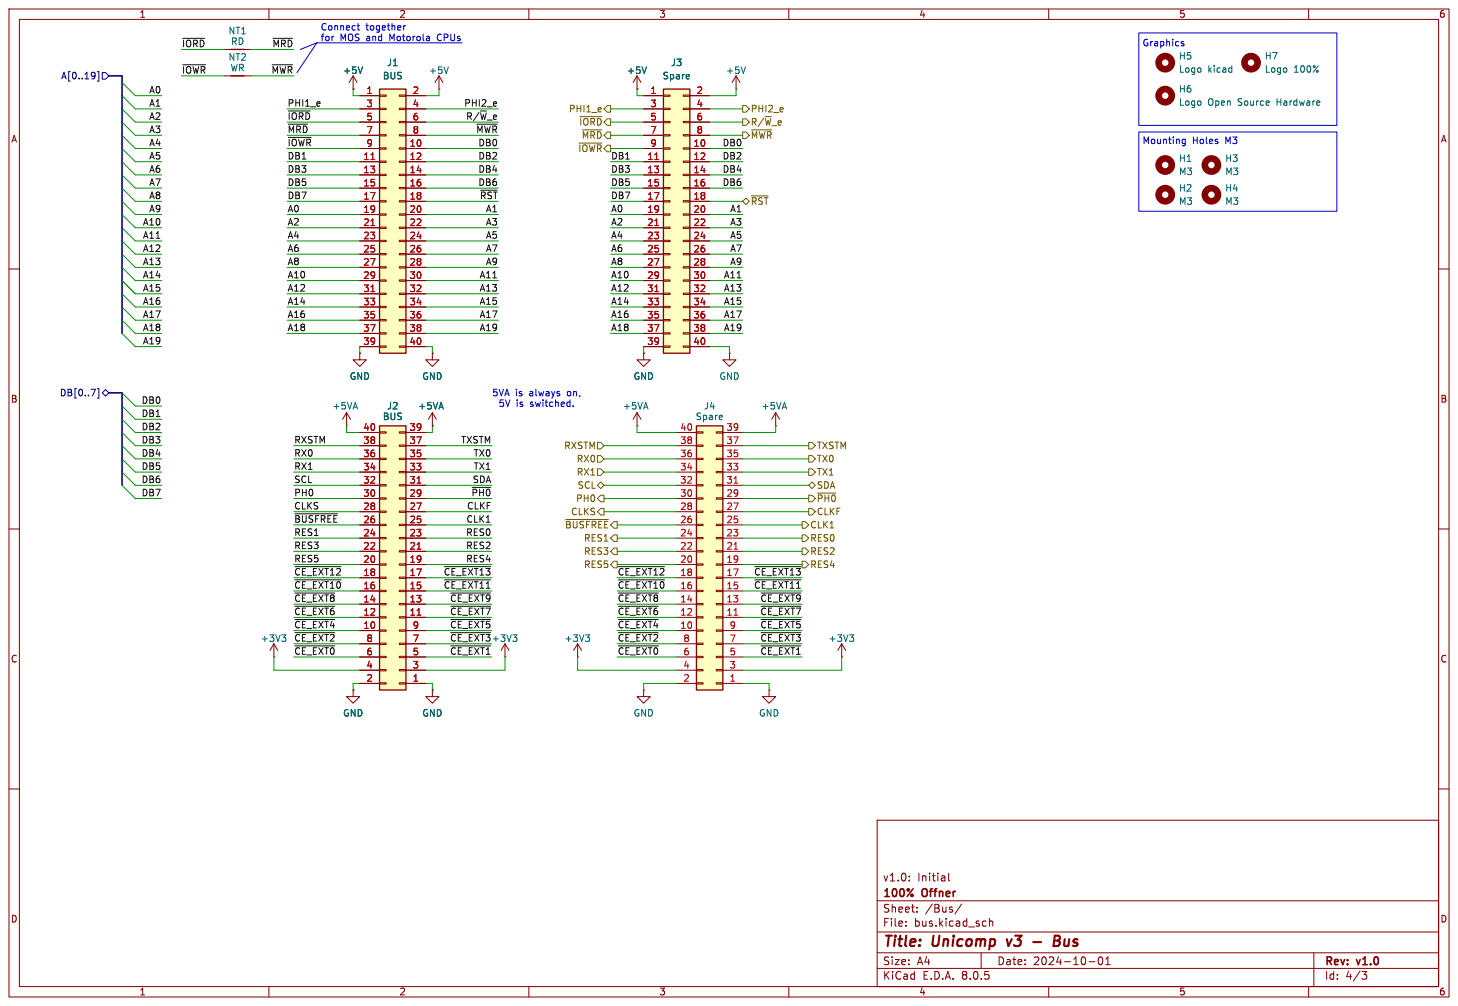
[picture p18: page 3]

Id: 4/3 Title: Unicomp v3 - Bus

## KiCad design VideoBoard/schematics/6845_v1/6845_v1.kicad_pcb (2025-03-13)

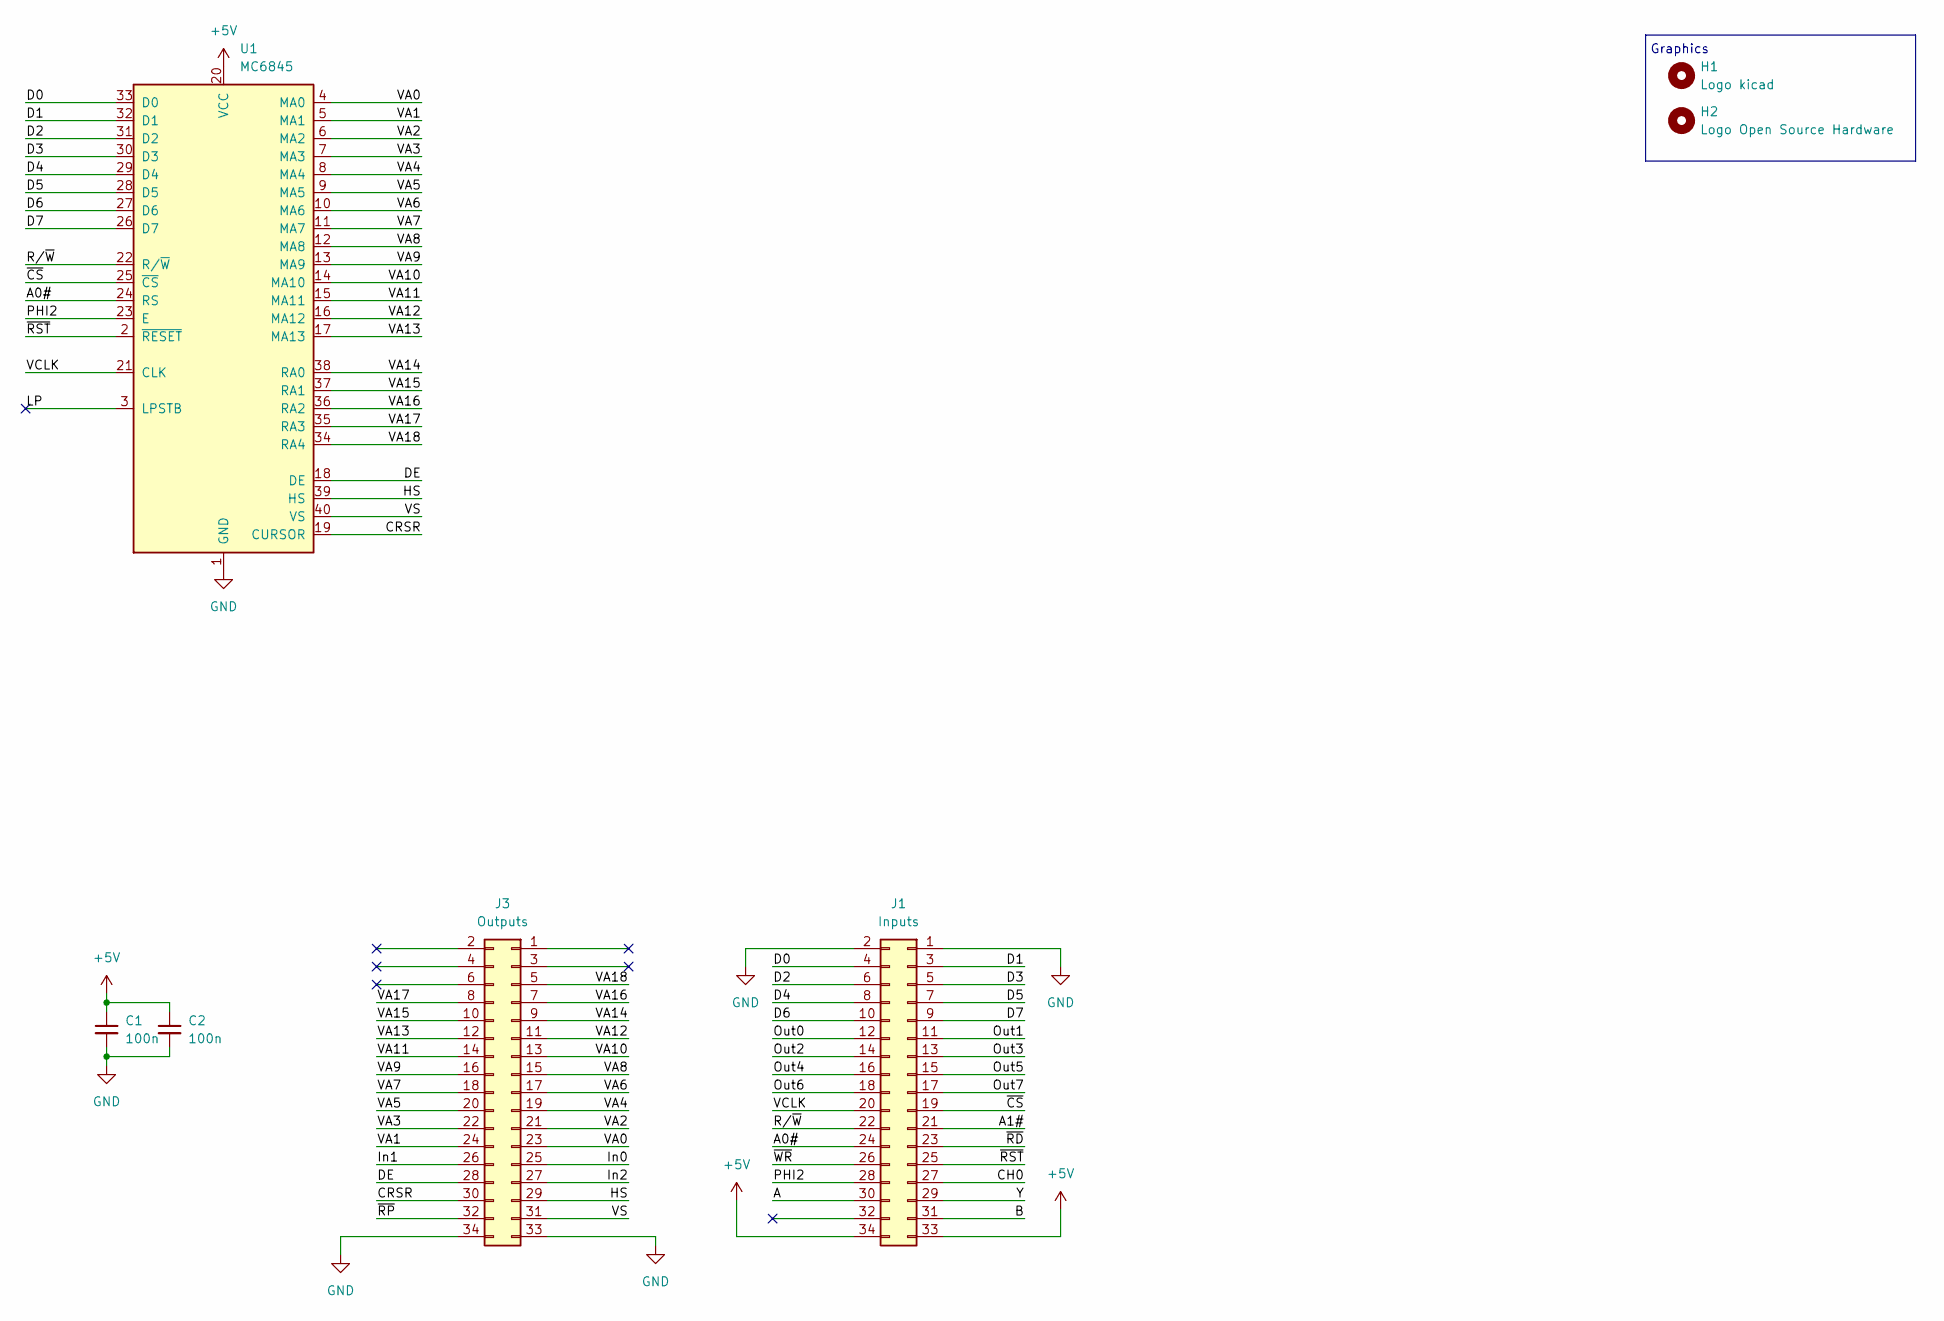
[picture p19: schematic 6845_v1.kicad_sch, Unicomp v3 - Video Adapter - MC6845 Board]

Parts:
C1, C2: 100n; C_1206_3216Metric_Pad1.33x1.80mm_HandSolder
H1: Logo kicad; KiCad-Logo2_6mm_SilkScreen
H2: Logo Open Source Hardware; OSHW-Logo2_7.3x6mm_SilkScreen
J1: Inputs; PinHeader_2x17_P2.54mm_Vertical
J3: Outputs; PinHeader_2x17_P2.54mm_Vertical
U1: MC6845; DIP-40_W15.24mm

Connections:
+5V: C1.1, C2.1, J1.33, J1.34, U1.20 (VCC)
/A: J1.30
/A0#: J1.24, U1.24 (RS)
/A1#: J1.21
/B: J1.31
/CH0: J1.27
/CRSR: J3.30, U1.19 (CURSOR)
/D0: J1.4, U1.33 (D0)
/D1: J1.3, U1.32 (D1)
/D2: J1.6, U1.31 (D2)
/D3: J1.5, U1.30 (D3)
/D4: J1.8, U1.29 (D4)
/D5: J1.7, U1.28 (D5)
/D6: J1.10, U1.27 (D6)
/D7: J1.9, U1.26 (D7)
/DE: J3.28, U1.18 (DE)
/HS: J3.29, U1.39 (HS)
/In0: J3.25
/In1: J3.26
/In2: J3.27
/LP: U1.3 (LPSTB)
/Out0: J1.12
/Out1: J1.11
/Out2: J1.14
/Out3: J1.13
/Out4: J1.16
/Out5: J1.15
/Out6: J1.18
/Out7: J1.17
/PHI2: J1.28, U1.23 (E)
/R/~W: J1.22, U1.22 (R/~W)
/VA0: J3.23, U1.4 (MA0)
/VA1: J3.24, U1.5 (MA1)
/VA2: J3.21, U1.6 (MA2)
/VA3: J3.22, U1.7 (MA3)
/VA4: J3.19, U1.8 (MA4)
/VA5: J3.20, U1.9 (MA5)
/VA6: J3.17, U1.10 (MA6)
/VA7: J3.18, U1.11 (MA7)
/VA8: J3.15, U1.12 (MA8)
/VA9: J3.16, U1.13 (MA9)
/VA10: J3.13, U1.14 (MA10)
/VA11: J3.14, U1.15 (MA11)
/VA12: J3.11, U1.16 (MA12)
/VA13: J3.12, U1.17 (MA13)
/VA14: J3.9, U1.38 (RA0)
/VA15: J3.10, U1.37 (RA1)
/VA16: J3.7, U1.36 (RA2)
/VA17: J3.8, U1.35 (RA3)
/VA18: J3.5, U1.34 (RA4)
/VCLK: J1.20, U1.21 (CLK)
/VS: J3.31, U1.40 (VS)
/Y: J1.29
/~CS: J1.19, U1.25 (~CS)
/~RD: J1.23
/~RP: J3.32
/~RST: J1.25, U1.2 (~RESET)
/~WR: J1.26
GND: C1.2, C2.2, J1.1, J1.2, J3.33, J3.34, U1.1 (GND)

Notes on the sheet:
Graphics

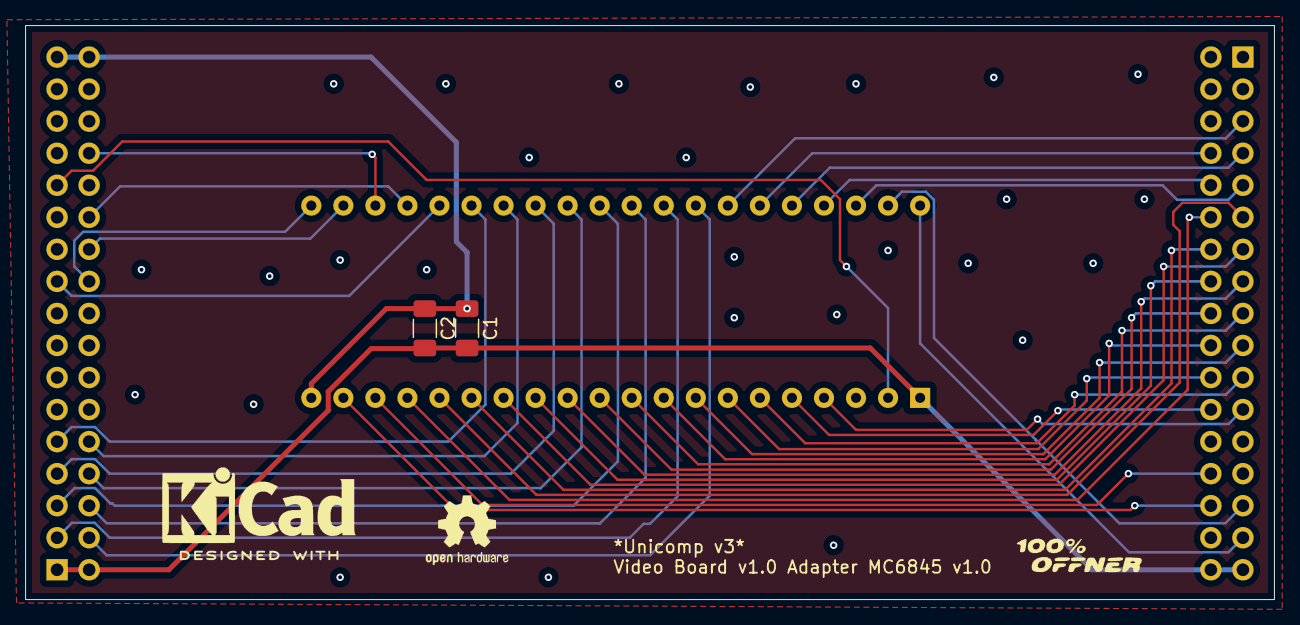
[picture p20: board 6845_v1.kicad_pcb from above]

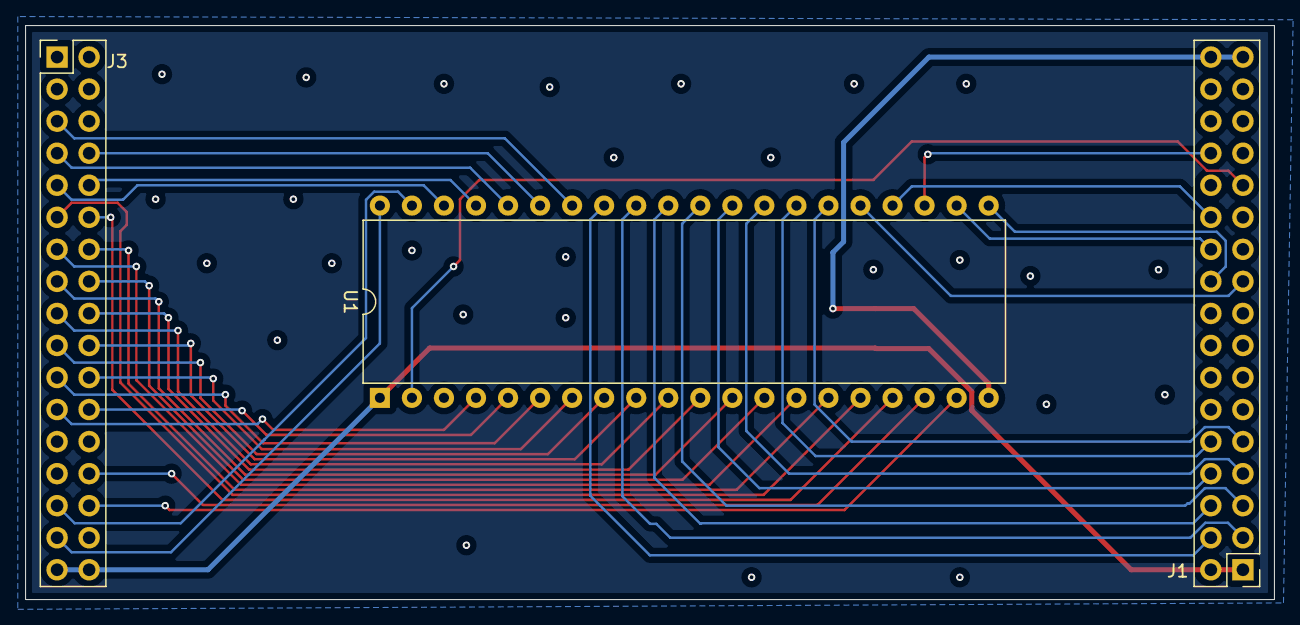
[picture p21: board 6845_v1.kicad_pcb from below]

Board: 2 copper layers, 99.0 x 45.5 mm, 7 parts (3 on the bottom side), 39 nets.

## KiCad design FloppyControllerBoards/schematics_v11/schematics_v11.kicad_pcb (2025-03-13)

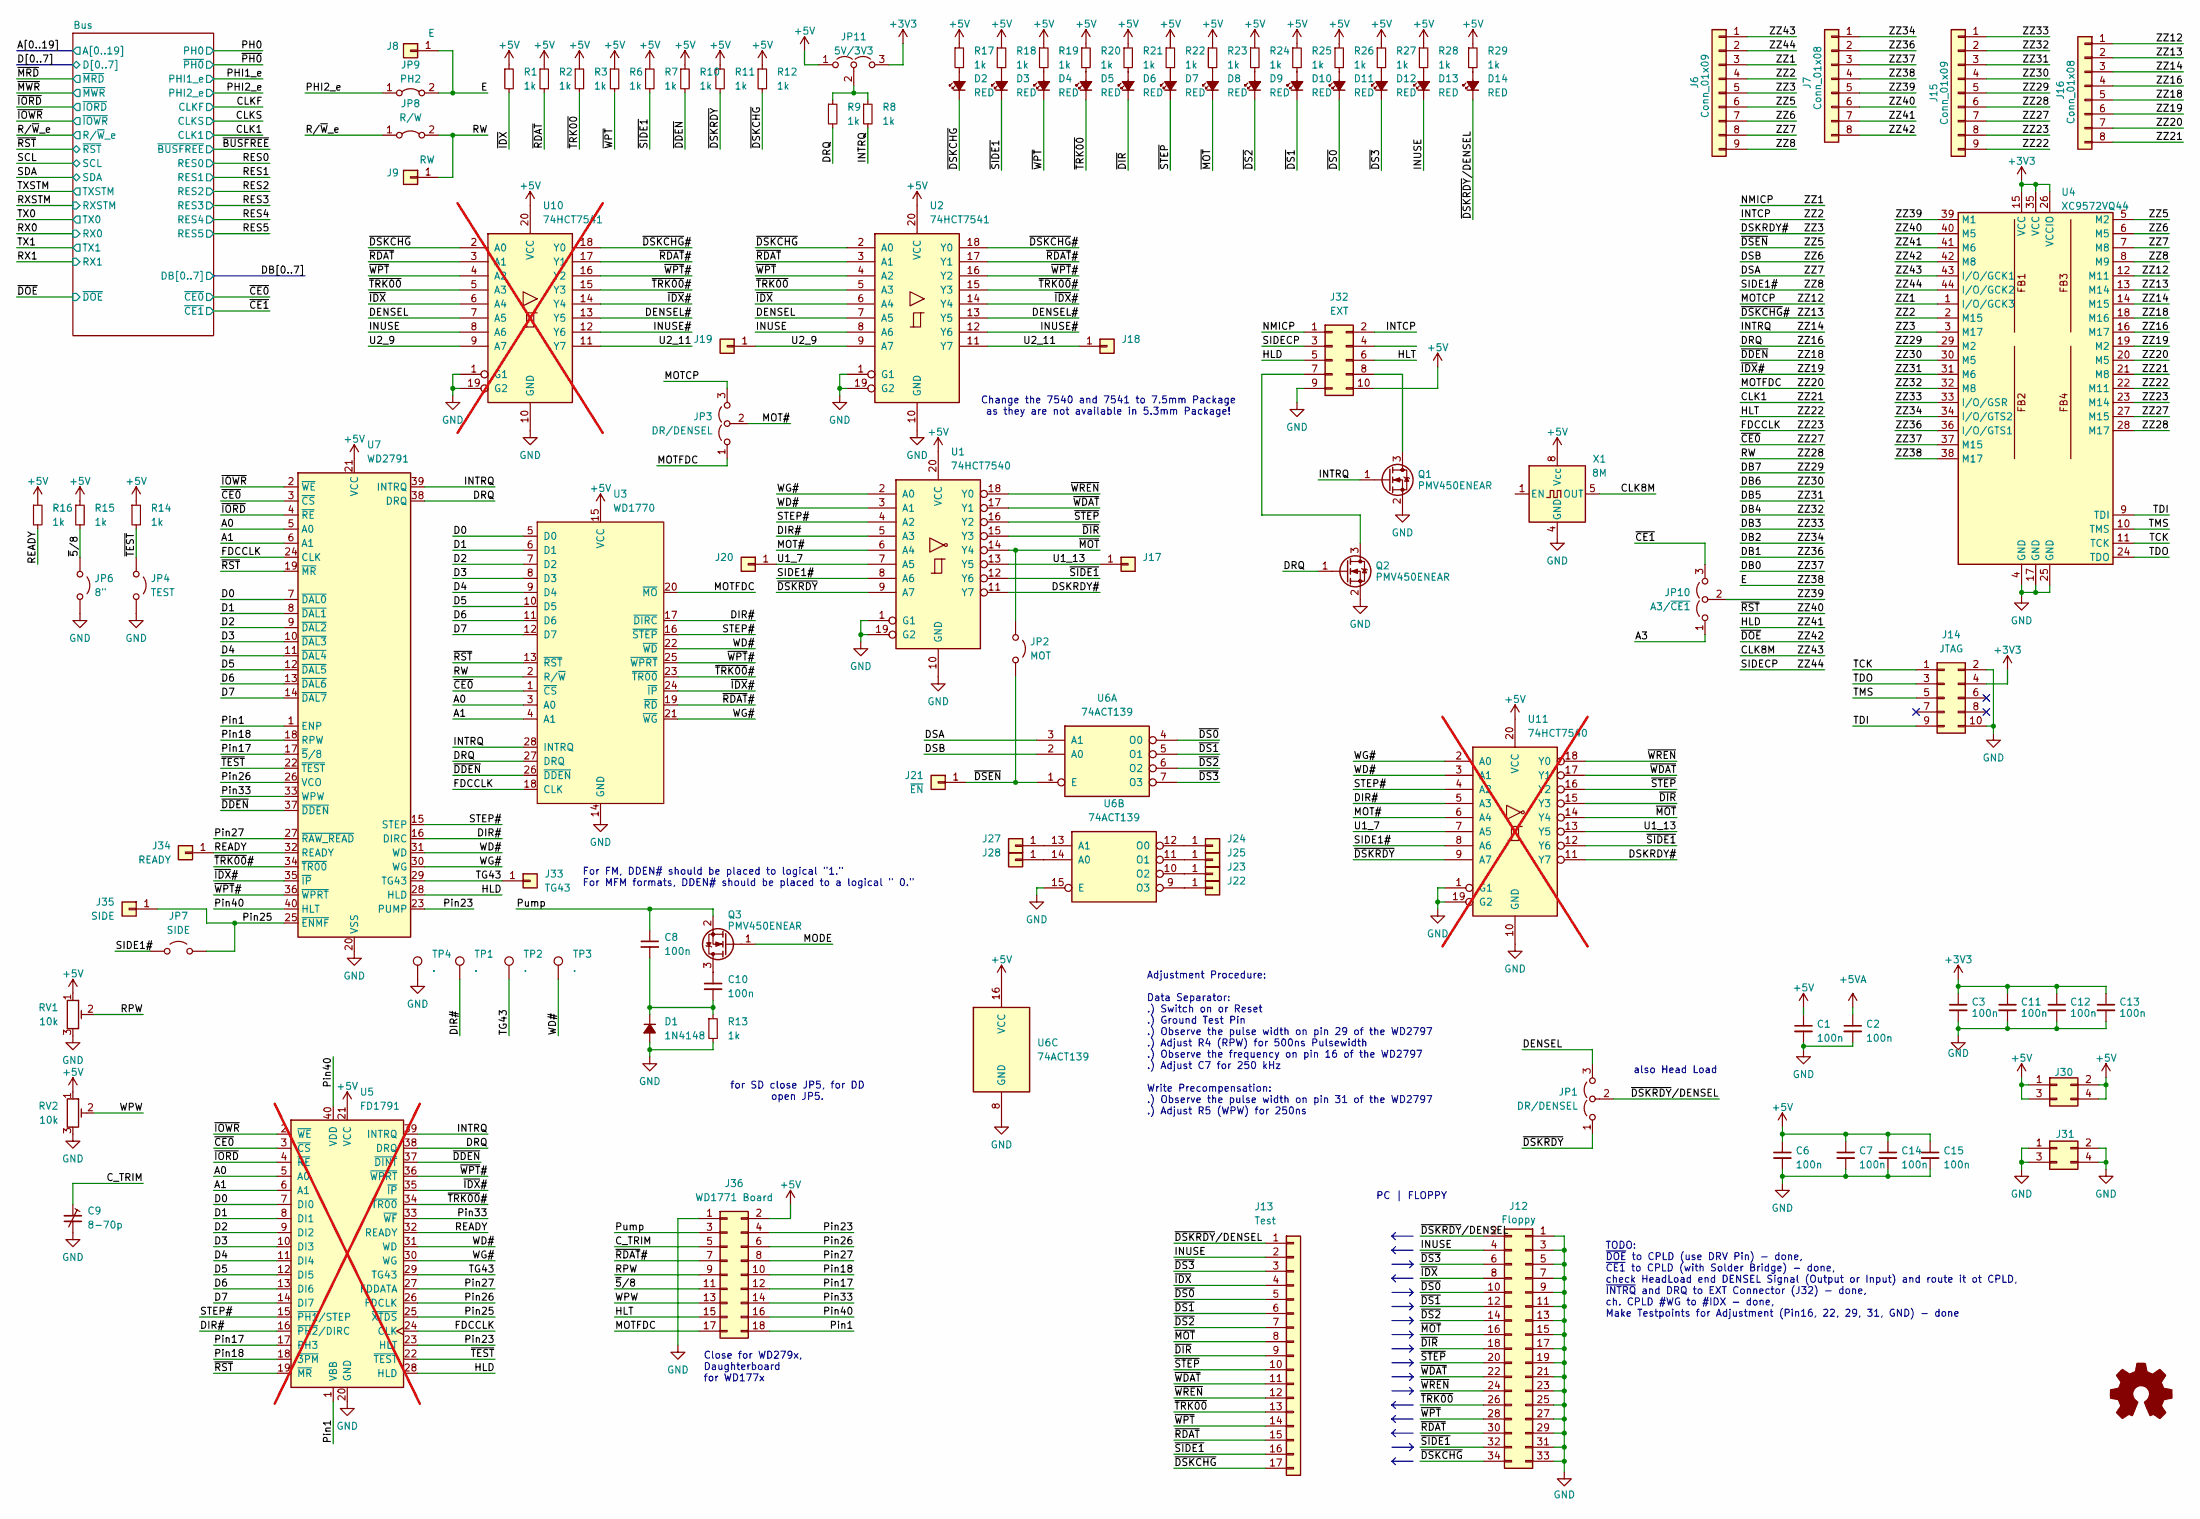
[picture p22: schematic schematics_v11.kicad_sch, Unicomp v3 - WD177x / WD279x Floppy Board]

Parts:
C1, C2, C3, C6, C7, C8, C10, C11, C12, C13, C14, C15: 100n; C_1206_3216Metric
C9: 8-70p; Capacitor_Trim
D1: 1N4148; D_1206_3216Metric_Pad1.42x1.75mm_HandSolder
D2, D3, D4, D5, D6, D7, D8, D9, D10, D11, D12, D13, D14: RED; LED_1206_3216Metric_Pad1.42x1.75mm_HandSolder
J6, J15: Conn_01x09; PinHeader_1x09_P2.54mm_Vertical
J7, J16: Conn_01x08; PinHeader_1x08_P2.54mm_Vertical
J8: E; PinHeader_1x01_P2.00mm_Vertical
J9: RW; PinHeader_1x01_P2.00mm_Vertical
J12: Floppy; PinHeader_2x17_P2.54mm_Horizontal
J13: Test; PinSocket_1x17_P2.54mm_Vertical
J14: JTAG; PinHeader_2x05_P2.54mm_Horizontal
J17, J18, J19, J20, J22, J23, J24, J25, J27, J28: Conn_01x01; PinHeader_1x01_P1.27mm_Vertical
J21: ~{EN}; PinHeader_1x01_P1.27mm_Vertical
J30, J31: Conn_02x02_Odd_Even; PinSocket_2x02_P2.54mm_Vertical
J32: EXT; PinHeader_2x05_P2.54mm_Horizontal
J33: TG43; PinHeader_1x01_P1.27mm_Vertical
J34: READY; PinHeader_1x01_P1.27mm_Vertical
J35: SIDE; PinHeader_1x01_P1.27mm_Vertical
J36: WD1771 Board; PinHeader_2x09_P2.54mm_Vertical
JP1, JP3: DR/DENSEL; PinHeader_1x03_P2.54mm_Vertical
JP2: MOT; SolderJumper-2_P1.3mm_Open_RoundedPad1.0x1.5mm
JP4: TEST; PinHeader_1x02_P2.54mm_Vertical
JP6: 8"; PinHeader_1x02_P2.54mm_Vertical
JP7: SIDE; SolderJumper-2_P1.3mm_Open_RoundedPad1.0x1.5mm
JP8: R/W; SolderJumper-2_P1.3mm_Bridged_RoundedPad1.0x1.5mm
JP9: PH2; SolderJumper-2_P1.3mm_Bridged_RoundedPad1.0x1.5mm
JP10: A3/~{CE1}; SolderJumper-3_P1.3mm_Open_RoundedPad1.0x1.5mm
JP11: 5V/3V3; SolderJumper-3_P1.3mm_Open_RoundedPad1.0x1.5mm
Q1, Q2, Q3: PMV450ENEAR; SOT-23
R1, R2, R3, R6, R7, R8, R9, R10, R11, R12, R13, R14, R15, R16, R17, R18, R19, R20, R21, R22, R23, R24, R25, R26, R27, R28, R29: 1k; R_1206_3216Metric_Pad1.30x1.75mm_HandSolder
RV1, RV2: 10k; Potentiometer_Vishay_T73XW_Horizontal
TP1, TP2, TP3, TP4: .; PinHeader_1x01_P2.54mm_Vertical
U1: 74HCT7540; SO-20_5.3x12.6mm_P1.27mm
U2: 74HCT7541; SO-20_5.3x12.6mm_P1.27mm
U3: WD1770; DIP-28_W15.24mm_Socket
U4: XC9572VQ44; TQFP-44_10x10mm_P0.8mm
U5: FD1791; DIP-40_W15.24mm; not fitted
U6: 74ACT139; SOIC-16_3.9x9.9mm_P1.27mm
U7: WD2791; DIP-40_W15.24mm
U10: 74HCT7541; SO-20_12.8x7.5mm_P1.27mm; not fitted
U11: 74HCT7540; SO-20_12.8x7.5mm_P1.27mm; not fitted
X1: 8M; Oscillator_DIP-8

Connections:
+3V3: C3.1, C11.1, C12.1, C13.1, J14.4, JP11.3 (B), U4.15 (VCC), U4.26 (VCCIO), U4.35 (VCC); also elsewhere on the board
+5V: C1.1, C6.1, C7.1, C14.1, C15.1, J30.1, J30.2, J30.3, J30.4, J32.10, J36.2, JP11.1 (A), R1.1, R2.1, R3.1, R6.1, R7.1, R10.1, R11.1, R12.1, R14.1, R15.1, R16.1, R17.1, R18.1, R19.1, R20.1, R21.1, R22.1, R23.1, R24.1, R25.1, R26.1, R27.1, R28.1, R29.1, RV1.1, RV2.1, U1.20 (VCC), U2.20 (VCC), U3.15 (VCC), U5.21 (VCC), U6.16 (VCC), U7.21 (VCC), U10.20 (VCC), U11.20 (VCC), X1.8 (Vcc); also elsewhere on the board
+5VA: C2.1; also elsewhere on the board
/A0: U3.3 (A0), U5.5 (A0), U7.5 (A0); also elsewhere on the board
/A1: U3.4 (A1), U5.6 (A1), U7.6 (A1); also elsewhere on the board
/A3: JP10.1 (A); also elsewhere on the board
/CLK1: J16.8, U4.21 (M8); also elsewhere on the board
/CLK8M: J6.1, U4.43 (I/O/GCK1), X1.5 (OUT)
/C_TRIM: C9.1, J36.5
/D0: U3.5 (D0), U5.7 (DI0), U7.7 (~DAL0); also elsewhere on the board
/D1: U3.6 (D1), U5.8 (DI1), U7.8 (~DAL1); also elsewhere on the board
/D2: U3.7 (D2), U5.9 (DI2), U7.9 (~DAL2); also elsewhere on the board
/D3: U3.8 (D3), U5.10 (DI3), U7.10 (~DAL3); also elsewhere on the board
/D4: U3.9 (D4), U5.11 (DI4), U7.11 (~DAL4); also elsewhere on the board
/D5: U3.10 (D5), U5.12 (DI5), U7.12 (~DAL5); also elsewhere on the board
/D6: U3.11 (D6), U5.13 (DI6), U7.13 (~DAL6); also elsewhere on the board
/D7: U3.12 (D7), U5.14 (DI7), U7.14 (~DAL7); also elsewhere on the board
/DB0: J7.3, U4.37 (M15); also elsewhere on the board
/DB1: J7.2, U4.36 (I/O/GTS1); also elsewhere on the board
/DB2: J7.1, U4.34 (I/O/GTS2); also elsewhere on the board
/DB3: J15.1, U4.33 (I/O/GSR); also elsewhere on the board
/DB4: J15.2, U4.32 (M8); also elsewhere on the board
/DB5: J15.3, U4.31 (M6); also elsewhere on the board
/DB6: J15.4, U4.30 (M5); also elsewhere on the board
/DB7: J15.5, U4.29 (M2); also elsewhere on the board
/DENSEL: JP1.3 (B), U2.7 (A5), U10.7 (A5)
/DENSEL#: U2.13 (Y5), U10.13 (Y5)
/DIR#: TP1.1, U1.5 (A3), U3.17 (~DIRC), U5.16 (~PH2/DIRC), U7.16 (DIRC), U11.5 (A3)
/DRQ: J16.4, Q2.1 (G), R9.2, U3.27 (DRQ), U4.16 (M17), U5.38 (DRQ), U7.38 (DRQ)
/DSA: J6.8, U4.7 (M8), U6.3 (A1)
/DSB: J6.7, U4.6 (M5), U6.2 (A0)
/DSKRDY#: J6.5, U1.11 (Y7), U4.3 (M17), U11.11 (Y7)
/E: J7.4, J8.1, JP9.2 (B), U4.38 (M17)
/FDCCLK: J15.8, U3.18 (CLK), U4.23 (M14), U5.24 (CLK), U7.24 (CLK)
/HLD: J7.7, J32.5, U4.41 (M6), U5.28 (HLD), U7.28 (HLD)
/HLT: J15.9, J32.6, J36.15, U4.22 (M11)
/INTCP: J6.4, J32.2, U4.2 (M15)
/INTRQ: J16.3, Q1.1 (G), R8.2, U3.28 (INTRQ), U4.14 (M15), U5.39 (INTRQ), U7.39 (INTRQ)
/INUSE: D13.1 (K), J12.4, J13.2, U2.8 (A6), U10.8 (A6)
/INUSE#: U2.12 (Y6), U10.12 (Y6)
/MODE: Q3.1 (G)
/MOT#: JP3.2 (C), U1.6 (A4), U11.6 (A4)
/MOTCP: J16.1, JP3.3 (B), U4.12 (M11)
/MOTFDC: J16.7, J36.17, JP3.1 (A), U3.20 (~MO), U4.20 (M5)
/NMICP: J6.3, J32.1, U4.1 (I/O/GCK3)
/PHI2_e: JP9.1 (A); also elsewhere on the board
/Pin1: J36.18, U5.1 (VBB), U7.1 (ENP)
/Pin17: J36.12, U5.17 (PH3), U7.17 (~5/8)
/Pin18: J36.10, U5.18 (~3PM), U7.18 (RPW)
/Pin23: J36.4, U5.23 (HLT), U7.23 (PUMP)
/Pin25: J35.1, JP7.2 (B), U5.25 (~XTDS), U7.25 (~ENMF)
/Pin26: J36.6, U5.26 (FDCLK), U7.26 (VCO)
/Pin27: J36.8, U5.27 (FDDATA), U7.27 (~RAW_READ)
/Pin33: J36.14, U5.33 (~WF), U7.33 (WPW)
/Pin40: J36.16, U5.40 (VDD), U7.40 (HLT)
/Pump: C8.1, J36.3, Q3.2 (S)
/READY: J34.1, R16.2, U5.32 (READY), U7.32 (READY)
/RPW: J36.9, RV1.2
/RW: J9.1, J15.6, JP8.2 (B), U3.2 (R/~W), U4.28 (M17)
/R/~W_e: JP8.1 (A); also elsewhere on the board
/SIDE1#: J6.9, JP7.1 (A), U1.8 (A6), U4.8 (M9), U11.8 (A6)
/SIDECP: J6.2, J32.3, U4.44 (I/O/GCK2)
/STEP#: U1.4 (A2), U3.16 (~STEP), U5.15 (~PH1/STEP), U7.15 (STEP), U11.4 (A2)
/TCK: J14.1, U4.11 (TCK)
/TDI: J14.9, U4.9 (TDI)
/TDO: J14.3, U4.24 (TDO)
/TG43: J33.1, TP2.1, U5.29 (TG43), U7.29 (TG43)
/TMS: J14.5, U4.10 (TMS)
/U1_7: J20.1, U1.7 (A5), U11.7 (A5)
/U1_13: J17.1, U1.13 (Y5), U11.13 (Y5)
/U2_9: J19.1, U2.9 (A7), U10.9 (A7)
/U2_11: J18.1, U2.11 (Y7), U10.11 (Y7)
/WD#: TP3.1, U1.3 (A1), U3.22 (~WD), U5.31 (WD), U7.31 (WD), U11.3 (A1)
/WG#: U1.2 (A0), U3.21 (~WG), U5.30 (WG), U7.30 (WG), U11.2 (A0)
/WPW: J36.13, RV2.2
/ZZ5: J6.6, J21.1, JP2.2 (B), U4.5 (M2), U6.1 (E)
/ZZ13: J16.2, U2.18 (Y0), U4.13 (M14), U10.18 (Y0)
/ZZ18: J16.5, R10.2, U3.26 (~DDEN), U4.18 (M16), U5.37 (~DINT), U7.37 (~DDEN)
/ZZ19: J16.6, U2.14 (Y4), U3.24 (~IP), U4.19 (M2), U5.35 (~IP), U7.35 (~IP), U10.14 (Y4)
/ZZ27: J15.7, U3.1 (~CS), U4.27 (M15), U5.3 (~CS), U7.3 (~CS); also elsewhere on the board
/ZZ39: J7.5, JP10.2 (C), U4.39 (M1)
/ZZ40: J7.6, U3.13 (~RST), U4.40 (M5), U5.19 (~MR), U7.19 (~MR); also elsewhere on the board
/ZZ42: J7.8, U4.42 (M8); also elsewhere on the board
/~5/8: J36.11, JP6.1 (A), R15.2
/~CE1: JP10.3 (B); also elsewhere on the board
/~DIR: D6.1 (K), J12.18, J13.9, U1.15 (Y3), U11.15 (Y3)
/~DS0: D11.1 (K), J12.10, J13.5, U6.4 (O0)
/~DS1: D10.1 (K), J12.12, J13.6, U6.5 (O1)
/~DS2: D9.1 (K), J12.14, J13.7, U6.6 (O2)
/~DS3: D12.1 (K), J12.6, J13.3, U6.7 (O3)
/~DSKCHG: D2.1 (K), J12.34, J13.17, R12.2, U2.2 (A0), U10.2 (A0)
/~DSKRDY: JP1.1 (A), R11.2, U1.9 (A7), U11.9 (A7)
/~DSKRDY/DENSEL: D14.1 (K), J12.2, J13.1, JP1.2 (C)
/~IDX: J12.8, J13.4, R1.2, U2.6 (A4), U10.6 (A4)
/~IORD: U5.4 (~RE), U7.4 (~RE); also elsewhere on the board
/~IOWR: U5.2 (~WE), U7.2 (~WE); also elsewhere on the board
/~MOT: D8.1 (K), J12.16, J13.8, JP2.1 (A), U1.14 (Y4), U11.14 (Y4)
/~RDAT: J12.30, J13.15, R2.2, U2.3 (A1), U10.3 (A1)
/~RDAT#: J36.7, U2.17 (Y1), U3.19 (~RD), U10.17 (Y1)
/~SIDE1: D3.1 (K), J12.32, J13.16, R7.2, U1.12 (Y6), U11.12 (Y6)
/~STEP: D7.1 (K), J12.20, J13.10, U1.16 (Y2), U11.16 (Y2)
/~TEST: JP4.1 (A), R14.2, U5.22 (~TEST), U7.22 (~TEST)
/~TRK00: D5.1 (K), J12.26, J13.13, R3.2, U2.5 (A3), U10.5 (A3)
/~TRK00#: U2.15 (Y3), U3.23 (~TR00), U5.34 (~TR00), U7.34 (~TR00), U10.15 (Y3)
/~WDAT: J12.22, J13.11, U1.17 (Y1), U11.17 (Y1)
/~WPT: D4.1 (K), J12.28, J13.14, R6.2, U2.4 (A2), U10.4 (A2)
/~WPT#: U2.16 (Y2), U3.25 (~WPRT), U5.36 (~WPRT), U7.36 (~WPRT), U10.16 (Y2)
/~WREN: J12.24, J13.12, U1.18 (Y0), U11.18 (Y0)
unnamed: C8.2, C10.2, D1.1 (K), R13.1
unnamed: D2.2 (A), R17.2
unnamed: D3.2 (A), R18.2
unnamed: D4.2 (A), R19.2
unnamed: D5.2 (A), R20.2
unnamed: D6.2 (A), R21.2
unnamed: D7.2 (A), R22.2
unnamed: D8.2 (A), R23.2
unnamed: D9.2 (A), R24.2
unnamed: D10.2 (A), R25.2
unnamed: D11.2 (A), R26.2
unnamed: D12.2 (A), R27.2
unnamed: D13.2 (A), R28.2
unnamed: D14.2 (A), R29.2
unnamed: J22.1, U6.9 (O3)
unnamed: J23.1, U6.10 (O2)
unnamed: J24.1, U6.12 (O0)
unnamed: J25.1, U6.11 (O1)
unnamed: J27.1, U6.13 (A1)
unnamed: J28.1, U6.14 (A0)
unnamed: J32.7, Q2.3 (D)
unnamed: J32.8, Q1.3 (D)
unnamed: JP11.2 (C), R8.1, R9.1
unnamed: C10.1, Q3.3 (D)

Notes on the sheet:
Adjustment Procedure: Data Separator: .) Switch on or Reset .) Ground Test Pin .) Observe the pulse width on pin 29 of the WD2797 .) Adjust R4 (RPW) for 500ns Pulsewidth .) Observe the frequency on pin 16 of the WD2797 .) Adjust C7 for 250 kHz Write Precompensation: .) Observe the pulse width on pi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
Close for WD279x, Daughterboard for WD177x
also Head Load
TODO: ~{DOE} to CPLD (use DRV Pin) - done, ~{CE1} to CPLD (with Solder Bridge) - done, check HeadLoad end DENSEL Signal (Output or Input) and route it ot CPLD, ~{INTRQ} and DRQ to EXT Connector (J32) - done, ch. CPLD #WG to #IDX - done, Make Testpoints for Adjustment (Pin16, 22, 29, 31, GND) - done
Change the 7540 and 7541 to 7.5mm Package as they are not available in 5.3mm Package!
for SD close JP5, for DD open JP5.
For FM, DDEN# should be placed to logical "1." For MFM formats, DDEN# should be placed to a logical " 0."
PC | FLOPPY

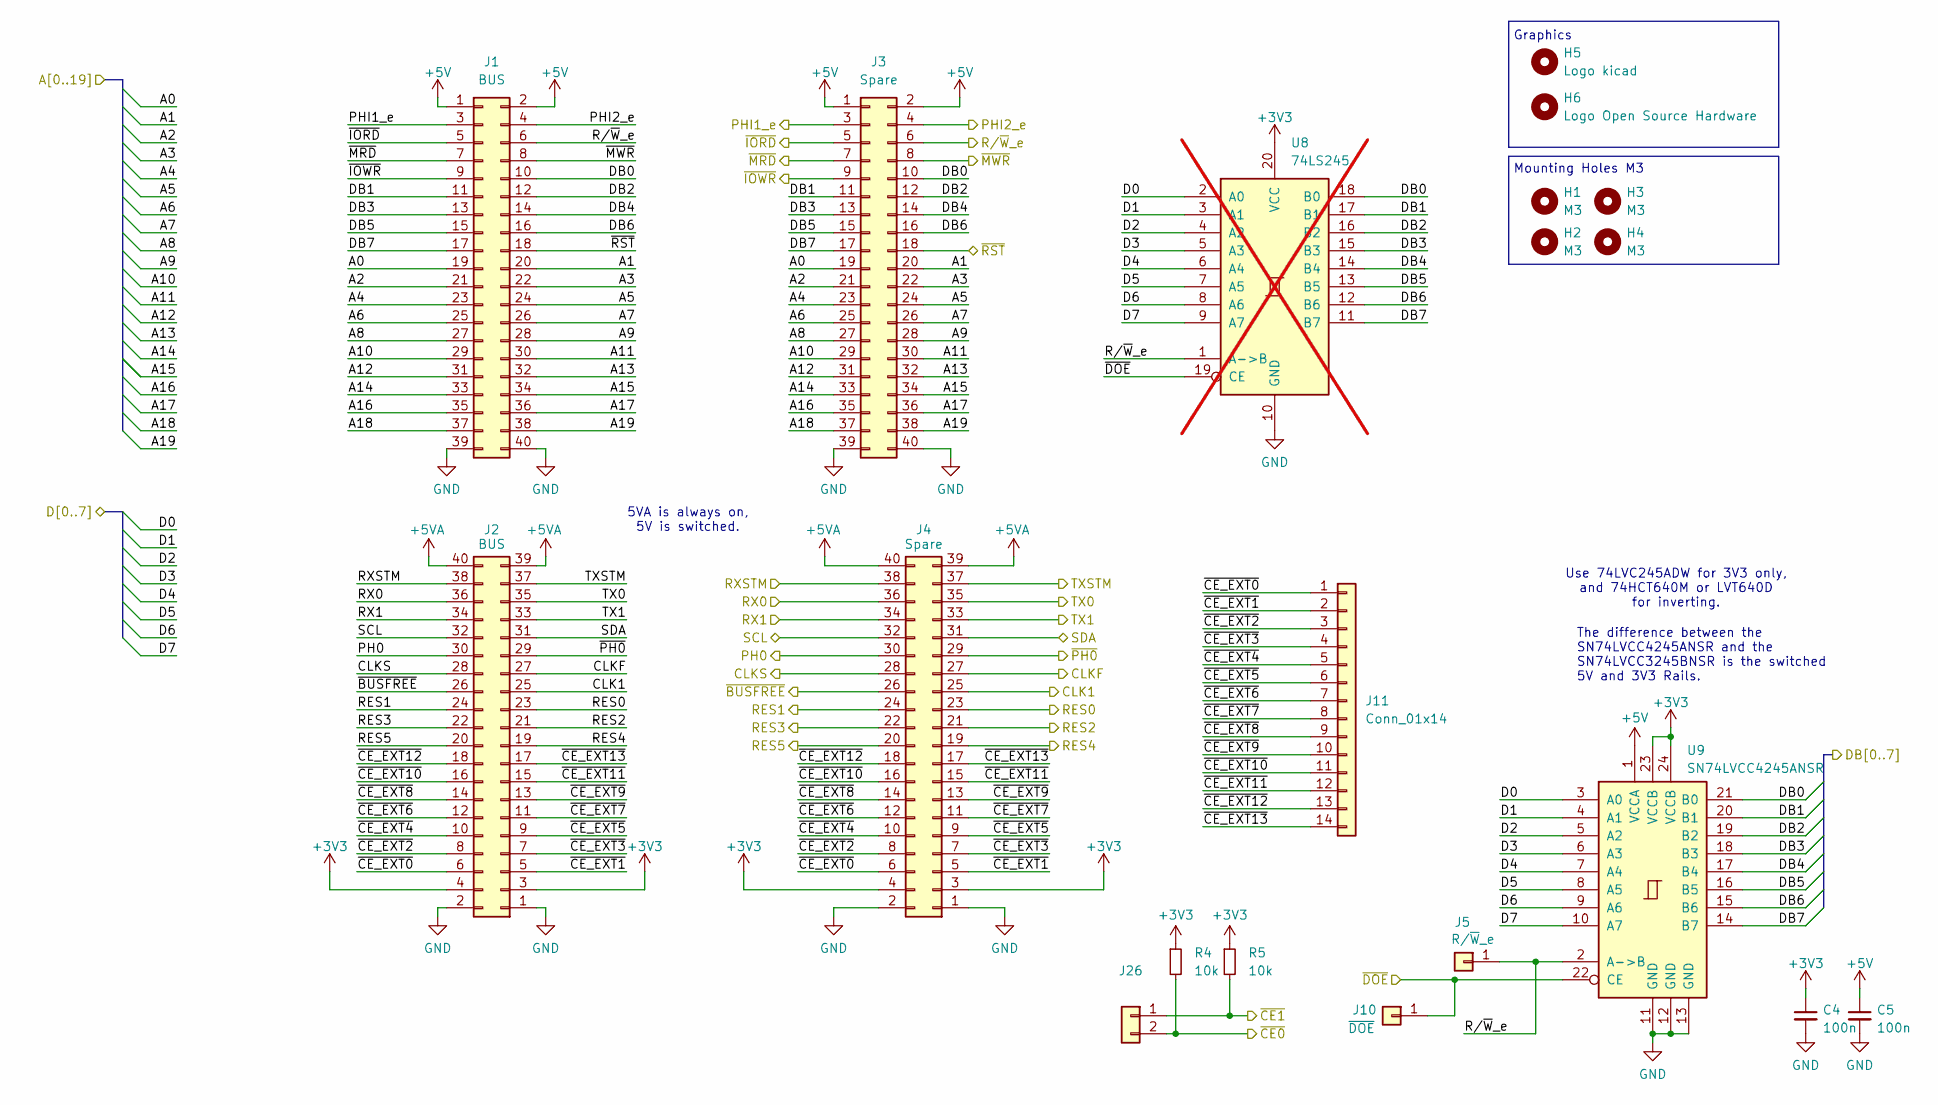
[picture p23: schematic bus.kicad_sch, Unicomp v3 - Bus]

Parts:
C4, C5: 100n; C_1206_3216Metric
H1, H2, H3, H4: M3; MountingHole_3.2mm_M3
H5: Logo kicad; KiCad-Logo2_6mm_SilkScreen
H6: Logo Open Source Hardware; OSHW-Logo2_7.3x6mm_SilkScreen
J1, J2: BUS; PinSocket_2x20_P2.54mm_Vertical
J3, J4: Spare; PinSocket_2x20_P2.54mm_Vertical
J5: R/~{W}_e; PinHeader_1x01_P2.00mm_Vertical
J10: ~{DOE}; PinHeader_1x01_P2.00mm_Vertical
J11: Conn_01x14; PinSocket_1x14_P2.54mm_Vertical
J26: Conn_01x02; PinSocket_1x02_P2.54mm_Vertical
R4, R5: 10k; R_1206_3216Metric_Pad1.30x1.75mm_HandSolder
U8: 74LS245; SOIC-20W_7.5x12.8mm_P1.27mm; not fitted
U9: SN74LVCC4245ANSR; SO-24_5.3x15mm_P1.27mm

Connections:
+3V3: C4.1, J2.3, J2.4, J4.3, J4.4, R4.1, R5.1, U8.20 (VCC), U9.23 (VCCB), U9.24 (VCCB); also elsewhere on the board
+5V: C5.1, J1.1, J1.2, J3.1, J3.2, U9.1 (VCCA); also elsewhere on the board
+5VA: J2.39, J2.40, J4.39, J4.40; also elsewhere on the board
/A0: J1.19, J3.19; also elsewhere on the board
/A1: J1.20, J3.20; also elsewhere on the board
/A2: J1.21, J3.21
/A3: J1.22, J3.22; also elsewhere on the board
/A4: J1.23, J3.23
/A5: J1.24, J3.24
/A6: J1.25, J3.25
/A7: J1.26, J3.26
/A8: J1.27, J3.27
/A9: J1.28, J3.28
/A10: J1.29, J3.29
/A11: J1.30, J3.30
/A12: J1.31, J3.31
/A13: J1.32, J3.32
/A14: J1.33, J3.33
/A15: J1.34, J3.34
/A16: J1.35, J3.35
/A17: J1.36, J3.36
/A18: J1.37, J3.37
/A19: J1.38, J3.38
/Bus/~CE_EXT0: J2.6, J4.6, J11.1
/Bus/~CE_EXT1: J2.5, J4.5, J11.2
/Bus/~CE_EXT2: J2.8, J4.8, J11.3
/Bus/~CE_EXT3: J2.7, J4.7, J11.4
/Bus/~CE_EXT4: J2.10, J4.10, J11.5
/Bus/~CE_EXT5: J2.9, J4.9, J11.6
/Bus/~CE_EXT6: J2.12, J4.12, J11.7
/Bus/~CE_EXT7: J2.11, J4.11, J11.8
/Bus/~CE_EXT8: J2.14, J4.14, J11.9
/Bus/~CE_EXT9: J2.13, J4.13, J11.10
/Bus/~CE_EXT10: J2.16, J4.16, J11.11
/Bus/~CE_EXT11: J2.15, J4.15, J11.12
/Bus/~CE_EXT12: J2.18, J4.18, J11.13
/Bus/~CE_EXT13: J2.17, J4.17, J11.14
/CLK1: J2.25, J4.25; also elsewhere on the board
/CLKF: J2.27, J4.27
/CLKS: J2.28, J4.28
/D0: U8.2 (A0), U9.3 (A0); also elsewhere on the board
/D1: U8.3 (A1), U9.4 (A1); also elsewhere on the board
/D2: U8.4 (A2), U9.5 (A2); also elsewhere on the board
/D3: U8.5 (A3), U9.6 (A3); also elsewhere on the board
/D4: U8.6 (A4), U9.7 (A4); also elsewhere on the board
/D5: U8.7 (A5), U9.8 (A5); also elsewhere on the board
/D6: U8.8 (A6), U9.9 (A6); also elsewhere on the board
/D7: U8.9 (A7), U9.10 (A7); also elsewhere on the board
/DB0: J1.10, J3.10, U8.18 (B0), U9.21 (B0); also elsewhere on the board
/DB1: J1.11, J3.11, U8.17 (B1), U9.20 (B1); also elsewhere on the board
/DB2: J1.12, J3.12, U8.16 (B2), U9.19 (B2); also elsewhere on the board
/DB3: J1.13, J3.13, U8.15 (B3), U9.18 (B3); also elsewhere on the board
/DB4: J1.14, J3.14, U8.14 (B4), U9.17 (B4); also elsewhere on the board
/DB5: J1.15, J3.15, U8.13 (B5), U9.16 (B5); also elsewhere on the board
/DB6: J1.16, J3.16, U8.12 (B6), U9.15 (B6); also elsewhere on the board
/DB7: J1.17, J3.17, U8.11 (B7), U9.14 (B7); also elsewhere on the board
/PH0: J2.30, J4.30
/PHI1_e: J1.3, J3.3
/PHI2_e: J1.4, J3.4; also elsewhere on the board
/RES0: J2.23, J4.23
/RES1: J2.24, J4.24
/RES2: J2.21, J4.21
/RES3: J2.22, J4.22
/RES4: J2.19, J4.19
/RES5: J2.20, J4.20
/RX0: J2.36, J4.36
/RX1: J2.34, J4.34
/RXSTM: J2.38, J4.38
/R/~W_e: J1.6, J3.6, J5.1, U8.1 (A->B), U9.2 (A->B); also elsewhere on the board
/SCL: J2.32, J4.32
/SDA: J2.31, J4.31
/TX0: J2.35, J4.35
/TX1: J2.33, J4.33
/TXSTM: J2.37, J4.37
/ZZ27: J26.2, R4.2; also elsewhere on the board
/ZZ40: J1.18, J3.18; also elsewhere on the board
/ZZ42: J10.1, U8.19 (CE), U9.22 (CE); also elsewhere on the board
/~BUSFREE: J2.26, J4.26
/~CE1: J26.1, R5.2; also elsewhere on the board
/~IORD: J1.5, J3.5; also elsewhere on the board
/~IOWR: J1.9, J3.9; also elsewhere on the board
/~MRD: J1.7, J3.7
/~MWR: J1.8, J3.8
/~PH0: J2.29, J4.29

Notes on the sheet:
Graphics
5VA is always on, 5V is switched.
Use 74LVC245ADW for 3V3 only, and 74HCT640M or LVT640D for inverting.
Mounting Holes M3
The difference between the SN74LVCC4245ANSR and the SN74LVCC3245BNSR is the switched 5V and 3V3 Rails.

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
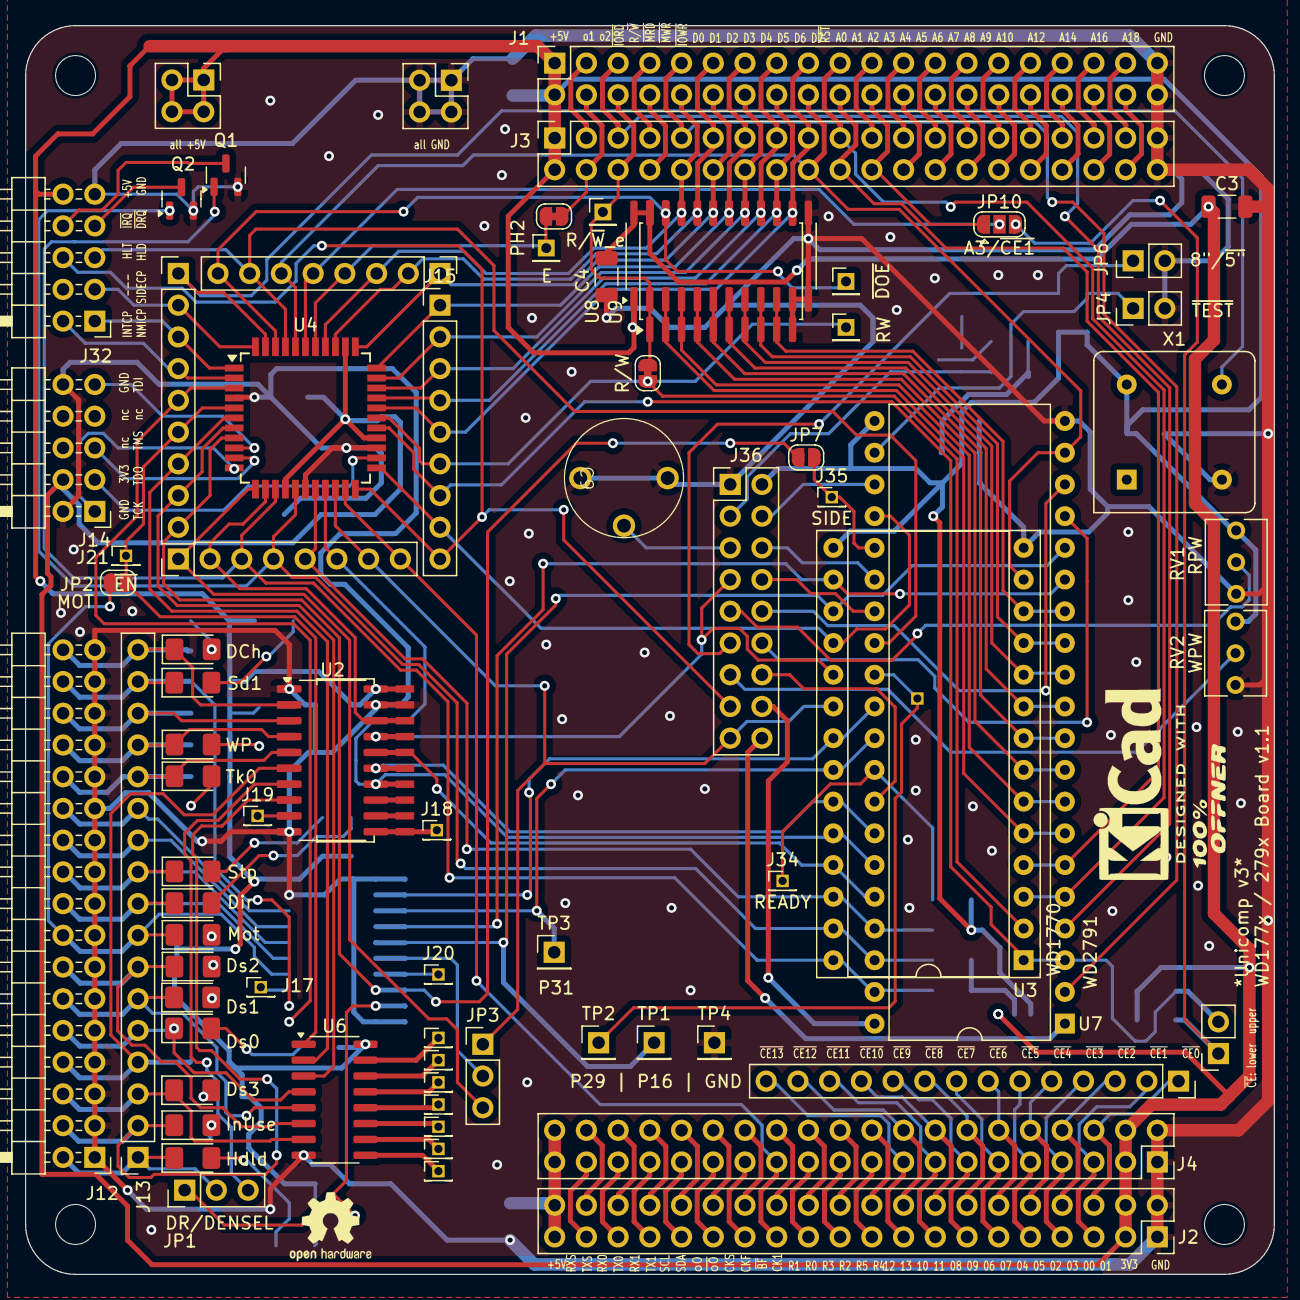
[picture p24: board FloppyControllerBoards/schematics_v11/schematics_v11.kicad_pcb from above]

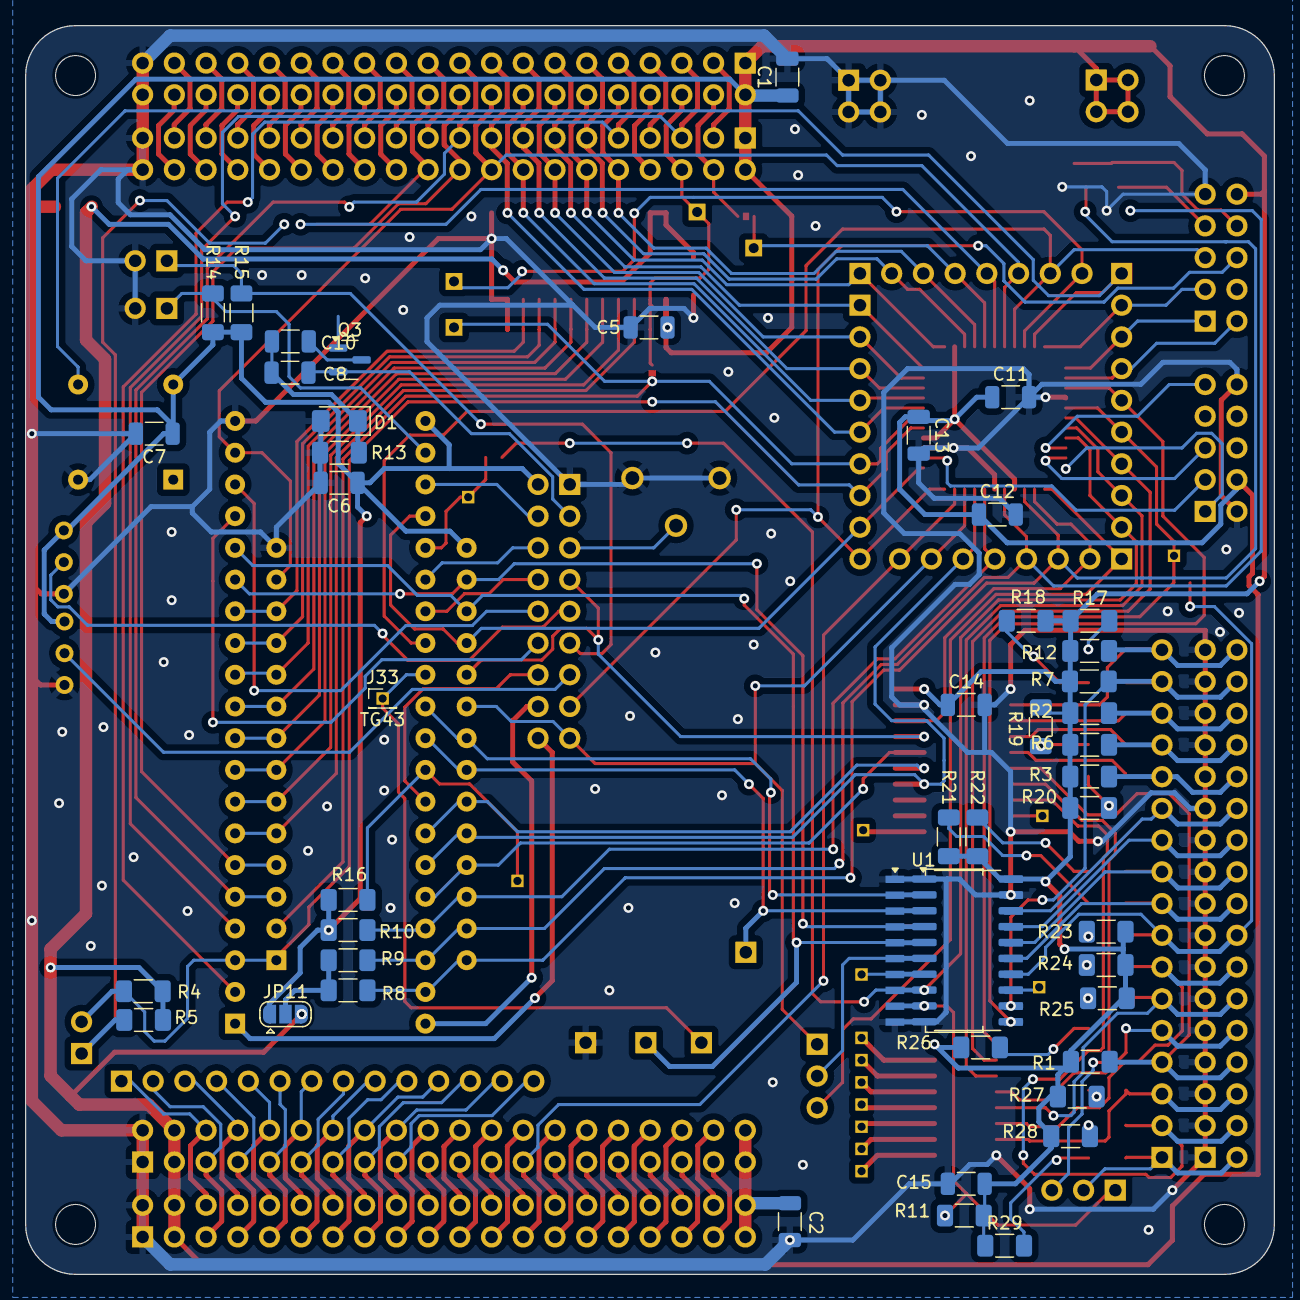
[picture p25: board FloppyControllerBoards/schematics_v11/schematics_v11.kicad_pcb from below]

Board: 2 copper layers, 100.0 x 100.0 mm, 130 parts (47 on the bottom side), 186 nets.

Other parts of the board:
J29: Conn_01x01; PinHeader_1x01_P1.27mm_Vertical

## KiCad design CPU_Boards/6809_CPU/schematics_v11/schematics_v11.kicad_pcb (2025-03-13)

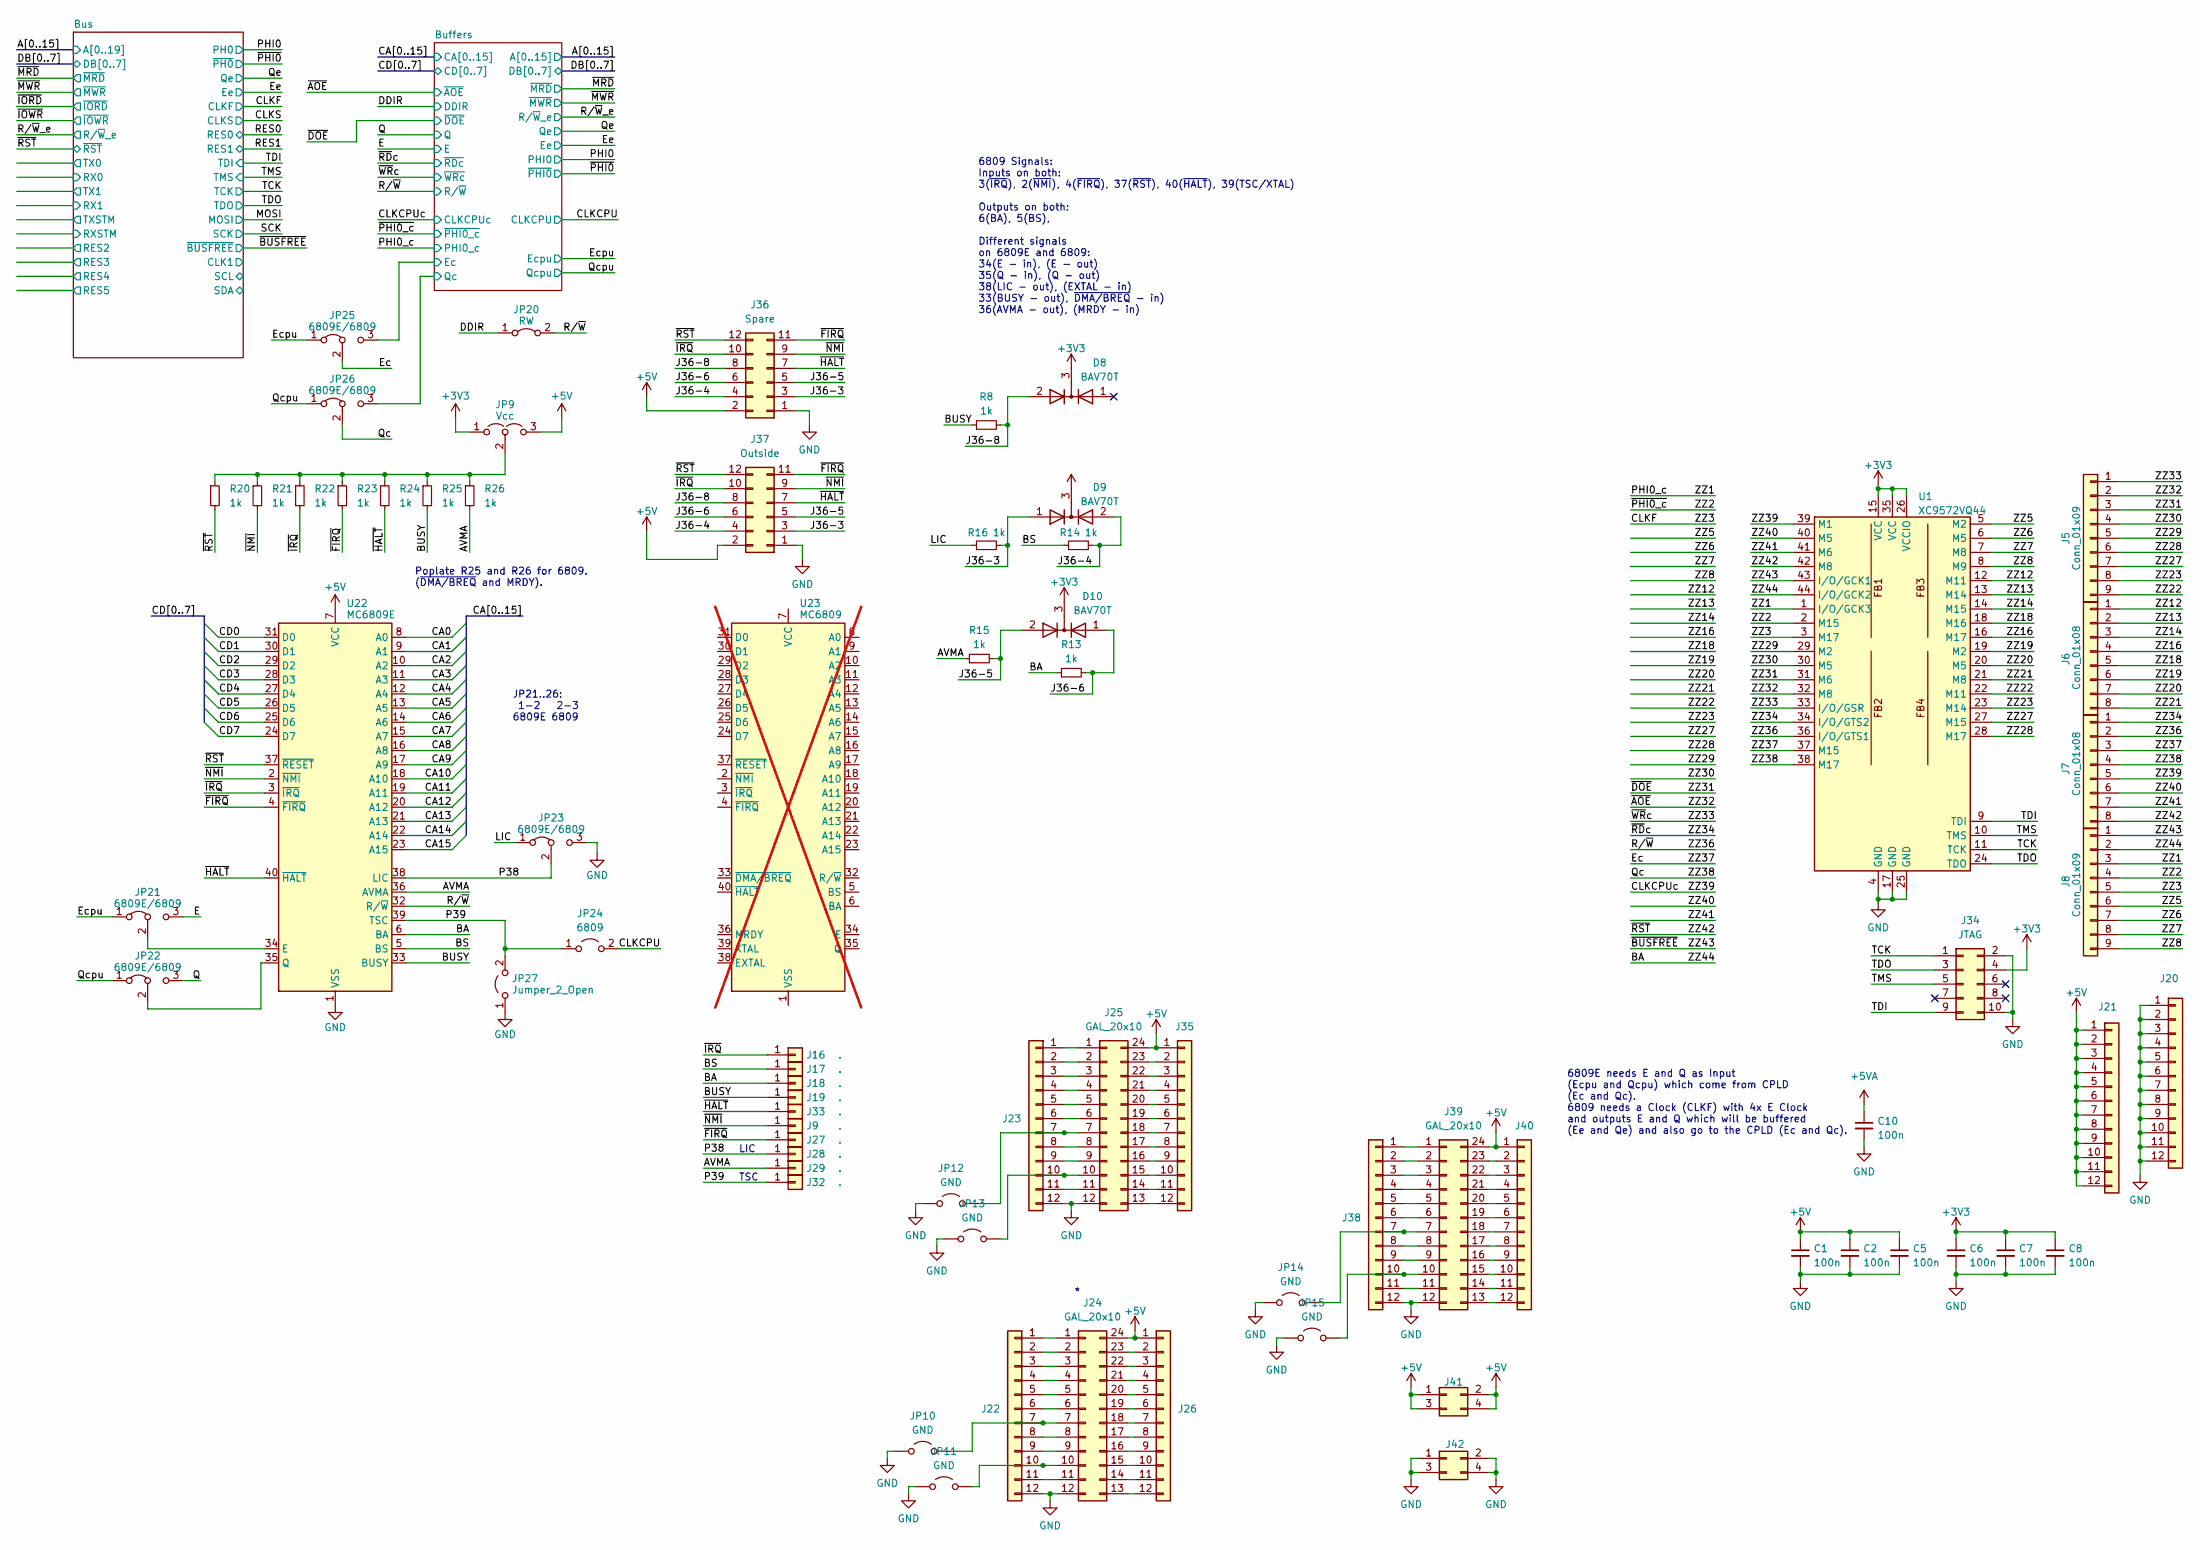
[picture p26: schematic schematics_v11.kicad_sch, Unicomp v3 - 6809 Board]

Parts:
C1, C2, C5, C6, C7, C8, C10: 100n; C_1206_3216Metric
D8, D9, D10: BAV70T; SOT-23_Handsoldering
J5, J8: Conn_01x09; PinHeader_1x09_P2.54mm_Vertical
J6, J7: Conn_01x08; PinHeader_1x08_P2.54mm_Vertical
J9, J16, J17, J18, J19, J27, J28, J29, J32, J33: .; PinHeader_1x01_P2.00mm_Vertical
J20, J21: Conn_01x12; PinHeader_1x12_P2.54mm_Vertical
J22, J23, J26, J35, J38, J40: Conn_01x12; PinSocket_1x12_P2.54mm_Vertical
J24, J25, J39: GAL_20x10; DIP-24_W7.62mm
J34: JTAG; PinHeader_2x05_P2.54mm_Horizontal
J36: Spare; PinHeader_2x06_P2.54mm_Vertical
J37: Outside; PinHeader_2x06_P2.54mm_Horizontal
J41, J42: Conn_02x02_Odd_Even; PinSocket_2x02_P2.54mm_Vertical
JP9: Vcc; SolderJumper-3_P1.3mm_Open_RoundedPad1.0x1.5mm_NumberLabels
JP10, JP11, JP12, JP13, JP14, JP15: GND; SolderJumper-2_P1.3mm_Open_RoundedPad1.0x1.5mm
JP20: RW; SolderJumper-2_P1.3mm_Bridged_RoundedPad1.0x1.5mm
JP21, JP22, JP23, JP25, JP26: 6809E/6809; SolderJumper-3_P1.3mm_Bridged12_RoundedPad1.0x1.5mm_NumberL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
JP24: 6809; SolderJumper-2_P1.3mm_Open_RoundedPad1.0x1.5mm
JP27: Jumper_2_Open; SolderJumper-2_P1.3mm_Open_RoundedPad1.0x1.5mm
R8, R13, R14, R15, R16, R20, R21, R22, R23, R24, R25, R26: 1k; R_1206_3216Metric_Pad1.30x1.75mm_HandSolder
U1: XC9572VQ44; TQFP-44_10x10mm_P0.8mm
U22: MC6809E; DIP-40_W15.24mm_LongPads
U23: MC6809; DIP-40_W15.24mm; not fitted

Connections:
+3V3: C6.1, C7.1, C8.1, D8.3 (K), D9.3 (K), D10.3 (K), J34.4, JP9.1 (A), U1.15 (VCC), U1.26 (VCCIO), U1.35 (VCC); also elsewhere on the board
+5V: C1.1, C2.1, C5.1, J21.1, J21.2, J21.3, J21.4, J21.5, J21.6, J21.7, J21.8, J21.9, J21.10, J21.11, J21.12, J24.24, J25.24, J26.1, J35.1, J36.2, J37.2, J39.24, J40.1, J41.1, J41.2, J41.3, J41.4, JP9.3 (B), U22.7 (VCC); also elsewhere on the board
+5VA: C10.1; also elsewhere on the board
/AVMA: J29.1, R15.1, R26.2, U22.36 (AVMA)
/BA: J8.2, J18.1, R13.1, U1.44 (I/O/GCK2), U22.6 (BA)
/BS: J17.1, R14.1, U22.5 (BS)
/BUSY: J19.1, R8.1, R25.2, U22.33 (BUSY)
/Buffers/Ec: JP25.3 (B); also elsewhere on the board
/Buffers/Qc: JP26.3 (B); also elsewhere on the board
/CA0: U22.8 (A0); also elsewhere on the board
/CA1: U22.9 (A1); also elsewhere on the board
/CA2: U22.10 (A2); also elsewhere on the board
/CA3: U22.11 (A3); also elsewhere on the board
/CA4: U22.12 (A4); also elsewhere on the board
/CA5: U22.13 (A5); also elsewhere on the board
/CA6: U22.14 (A6); also elsewhere on the board
/CA7: U22.15 (A7); also elsewhere on the board
/CA8: U22.16 (A8); also elsewhere on the board
/CA9: U22.17 (A9); also elsewhere on the board
/CA10: U22.18 (A10); also elsewhere on the board
/CA11: U22.19 (A11); also elsewhere on the board
/CA12: U22.20 (A12); also elsewhere on the board
/CA13: U22.21 (A13); also elsewhere on the board
/CA14: U22.22 (A14); also elsewhere on the board
/CA15: U22.23 (A15); also elsewhere on the board
/CD0: U22.31 (D0); also elsewhere on the board
/CD1: U22.30 (D1); also elsewhere on the board
/CD2: U22.29 (D2); also elsewhere on the board
/CD3: U22.28 (D3); also elsewhere on the board
/CD4: U22.27 (D4); also elsewhere on the board
/CD5: U22.26 (D5); also elsewhere on the board
/CD6: U22.25 (D6); also elsewhere on the board
/CD7: U22.24 (D7); also elsewhere on the board
/CLKCPU: JP24.2 (B); also elsewhere on the board
/CLKCPUc: J7.5, U1.39 (M1); also elsewhere on the board
/CLKF: J8.5, U1.3 (M17); also elsewhere on the board
/DDIR: JP20.1 (A); also elsewhere on the board
/E: JP21.3 (B); also elsewhere on the board
/Ec: J7.3, JP25.2 (C), U1.37 (M15)
/Ecpu: JP21.1 (A), JP25.1 (A); also elsewhere on the board
/J36-3: D9.1 (A), J36.3, J37.3, R16.2
/J36-4: D9.2 (A), J36.4, J37.4, R14.2
/J36-5: D10.2 (A), J36.5, J37.5, R15.2
/J36-6: D10.1 (A), J36.6, J37.6, R13.2
/J36-8: D8.2 (A), J36.8, J37.8, R8.2
/LIC: JP23.1 (A), R16.1
/P38: J28.1, JP23.2 (C), U22.38 (LIC)
/P39: J32.1, JP24.1 (A), JP27.2 (B), U22.39 (TSC)
/PHI0_c: J8.3, U1.1 (I/O/GCK3); also elsewhere on the board
/Q: JP22.3 (B); also elsewhere on the board
/Qc: J7.4, JP26.2 (C), U1.38 (M17)
/Qcpu: JP22.1 (A), JP26.1 (A); also elsewhere on the board
/R/~W: J7.2, JP20.2 (B), U1.36 (I/O/GTS1), U22.32 (R/~W); also elsewhere on the board
/TCK: J34.1, U1.11 (TCK)
/TDI: J34.9, U1.9 (TDI)
/TDO: J34.3, U1.24 (TDO)
/TMS: J34.5, U1.10 (TMS)
/ZZ2: J8.4, U1.2 (M15); also elsewhere on the board
/ZZ5: J8.6, U1.5 (M2)
/ZZ6: J8.7, U1.6 (M5)
/ZZ7: J8.8, U1.7 (M8)
/ZZ8: J8.9, U1.8 (M9)
/ZZ12: J6.1, U1.12 (M11)
/ZZ13: J6.2, U1.13 (M14)
/ZZ14: J6.3, U1.14 (M15)
/ZZ16: J6.4, U1.16 (M17)
/ZZ18: J6.5, U1.18 (M16)
/ZZ19: J6.6, U1.19 (M2)
/ZZ20: J6.7, U1.20 (M5)
/ZZ21: J6.8, U1.21 (M8)
/ZZ22: J5.9, U1.22 (M11)
/ZZ23: J5.8, U1.23 (M14)
/ZZ27: J5.7, U1.27 (M15)
/ZZ28: J5.6, U1.28 (M17)
/ZZ29: J5.5, U1.29 (M2)
/ZZ30: J5.4, U1.30 (M5)
/ZZ31: J5.3, U1.31 (M6); also elsewhere on the board
/ZZ32: J5.2, U1.32 (M8); also elsewhere on the board
/ZZ33: J5.1, U1.33 (I/O/GSR); also elsewhere on the board
/ZZ34: J7.1, U1.34 (I/O/GTS2); also elsewhere on the board
/ZZ40: J7.6, U1.40 (M5)
/ZZ41: J7.7, U1.41 (M6)
/ZZ42: J7.8, J36.12, J37.12, R20.2, U1.42 (M8), U22.37 (~RESET); also elsewhere on the board
/ZZ43: J8.1, U1.43 (I/O/GCK1); also elsewhere on the board
/~FIRQ: J27.1, J36.11, J37.11, R23.2, U22.4 (~FIRQ)
/~HALT: J33.1, J36.7, J37.7, R24.2, U22.40 (~HALT)
/~IRQ: J16.1, J36.10, J37.10, R22.2, U22.3 (~IRQ)
/~NMI: J9.1, J36.9, J37.9, R21.2, U22.2 (~NMI)
GND: C1.2, C2.2, C5.2, C6.2, C7.2, C8.2, C10.2, J20.1, J20.2, J20.3, J20.4, J20.5, J20.6, J20.7, J20.8, J20.9, J20.10, J20.11, J20.12, J22.12, J23.12, J24.12, J25.12, J34.2, J34.10, J36.1, J37.1, J38.12, J39.12, J42.1, J42.2, J42.3, J42.4, JP10.1 (A), JP11.1 (A), JP12.1 (A), JP13.1 (A), JP14.1 (A), JP15.1 (A), JP23.3 (B), JP27.1 (A), U1.4 (GND), U1.17 (GND), U1.25 (GND), U22.1 (VSS); also elsewhere on the board
unnamed: J22.1, J24.1
unnamed: J22.2, J24.2
unnamed: J22.3, J24.3
unnamed: J22.4, J24.4
unnamed: J22.5, J24.5
unnamed: J22.6, J24.6
unnamed: J22.7, J24.7, JP10.2 (B)
unnamed: J22.8, J24.8
unnamed: J22.9, J24.9
unnamed: J22.10, J24.10, JP11.2 (B)
unnamed: J22.11, J24.11
unnamed: J23.1, J25.1
unnamed: J23.2, J25.2
unnamed: J23.3, J25.3
unnamed: J23.4, J25.4
unnamed: J23.5, J25.5
unnamed: J23.6, J25.6
unnamed: J23.7, J25.7, JP12.2 (B)
unnamed: J23.8, J25.8
unnamed: J23.9, J25.9
unnamed: J23.10, J25.10, JP13.2 (B)
unnamed: J23.11, J25.11
unnamed: J24.13, J26.12
unnamed: J24.14, J26.11
unnamed: J24.15, J26.10
unnamed: J24.16, J26.9
unnamed: J24.17, J26.8
unnamed: J24.18, J26.7
unnamed: J24.19, J26.6
unnamed: J24.20, J26.5
unnamed: J24.21, J26.4
unnamed: J24.22, J26.3
unnamed: J24.23, J26.2
unnamed: J25.13, J35.12
unnamed: J25.14, J35.11
unnamed: J25.15, J35.10
unnamed: J25.16, J35.9
unnamed: J25.17, J35.8
unnamed: J25.18, J35.7
unnamed: J25.19, J35.6
unnamed: J25.20, J35.5
unnamed: J25.21, J35.4
unnamed: J25.22, J35.3
unnamed: J25.23, J35.2
unnamed: J38.1, J39.1
unnamed: J38.2, J39.2
unnamed: J38.3, J39.3
unnamed: J38.4, J39.4
unnamed: J38.5, J39.5
unnamed: J38.6, J39.6
unnamed: J38.7, J39.7, JP14.2 (B)
unnamed: J38.8, J39.8
unnamed: J38.9, J39.9
unnamed: J38.10, J39.10, JP15.2 (B)
unnamed: J38.11, J39.11
unnamed: J39.13, J40.12
unnamed: J39.14, J40.11
unnamed: J39.15, J40.10
unnamed: J39.16, J40.9
unnamed: J39.17, J40.8
unnamed: J39.18, J40.7
unnamed: J39.19, J40.6
unnamed: J39.20, J40.5
unnamed: J39.21, J40.4
unnamed: J39.22, J40.3
unnamed: J39.23, J40.2
unnamed: JP9.2 (C), R20.1, R21.1, R22.1, R23.1, R24.1, R25.1, R26.1
unnamed: JP21.2 (C), U22.34 (E)
unnamed: JP22.2 (C), U22.35 (Q)

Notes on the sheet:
Poplate R25 and R26 for 6809. (~{DMA/BREQ} and MRDY).
6809 Signals: Inputs on both: 3(~{IRQ}), 2(~{NMI}), 4(~{FIRQ}), 37(~{RST}), 40(~{HALT}), 39(TSC/XTAL) Outputs on both: 6(BA), 5(BS), Different signals on 6809E and 6809: 34(E - in), (E - out) 35(Q - in), (Q - out) 38(LIC - out), (EXTAL - in) 33(BUSY - out), ~{DMA/BREQ} - in) 36(AVMA - out), (MRDY -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
LIC
6809E needs E and Q as Input (Ecpu and Qcpu) which come from CPLD (Ec and Qc). 6809 needs a Clock (CLKF) with 4x E Clock and outputs E and Q which will be buffered (Ee and Qe) and also go to the CPLD (Ec and Qc).
TSC
JP21..26: 1-2 2-3 6809E 6809

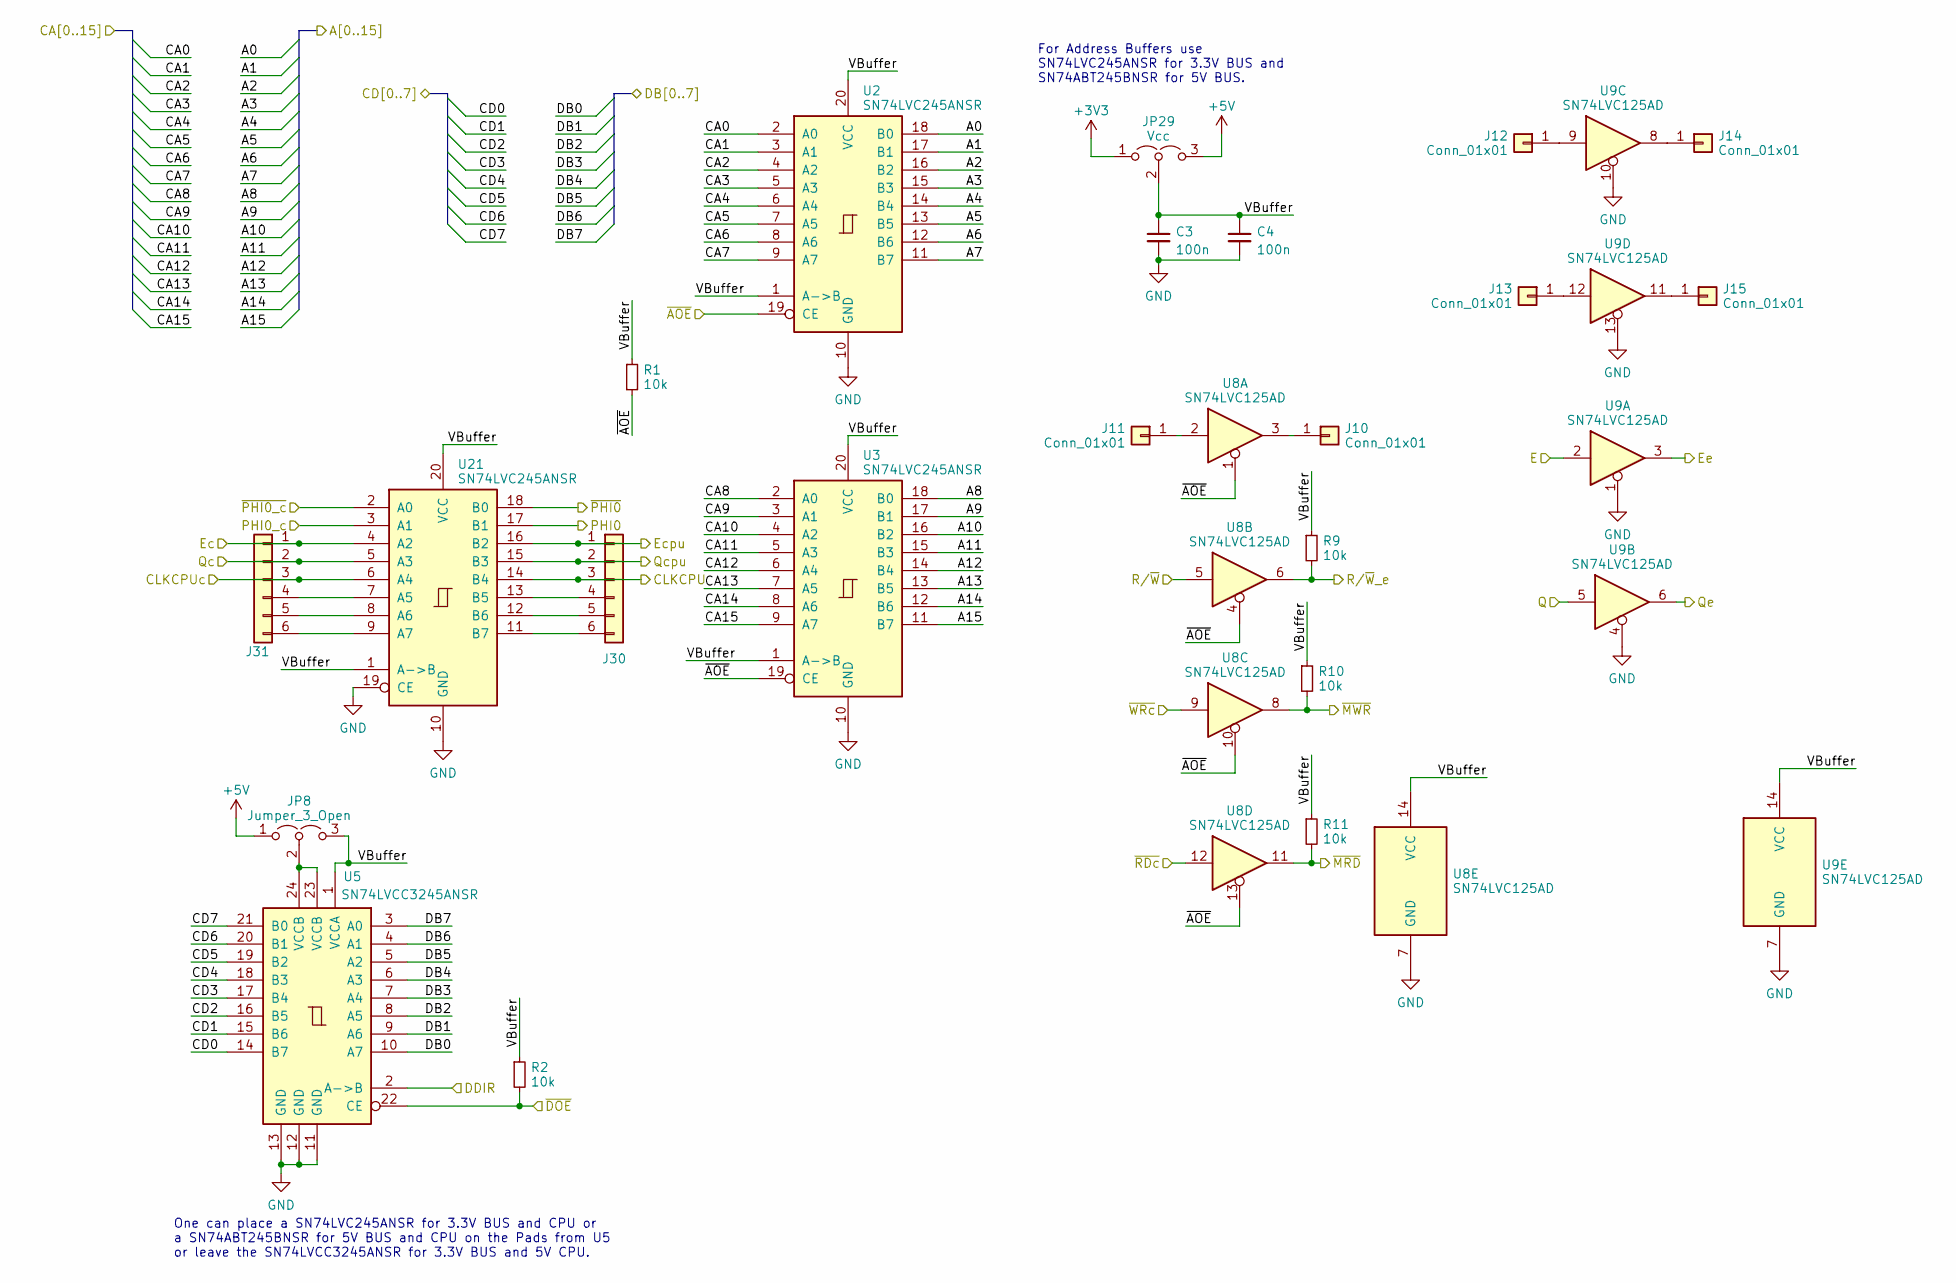
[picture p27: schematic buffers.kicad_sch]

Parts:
C3, C4: 100n; C_1206_3216Metric
J10, J11, J12, J13, J14, J15: Conn_01x01; PinHeader_1x01_P1.27mm_Vertical
J30, J31: Conn_01x06; PinHeader_1x06_P1.27mm_Vertical
JP8: Jumper_3_Open; SolderJumper-3_P1.3mm_Open_Pad1.0x1.5mm_NumberLabels
JP29: Vcc; SolderJumper-3_P1.3mm_Open_RoundedPad1.0x1.5mm_NumberLabels
R1, R2, R9, R10, R11: 10k; R_1206_3216Metric_Pad1.30x1.75mm_HandSolder
U2, U3, U21: SN74LVC245ANSR; SO-20_5.3x12.6mm_P1.27mm
U5: SN74LVCC3245ANSR; SO-24_5.3x15mm_P1.27mm
U8, U9: SN74LVC125AD; SOIC-14_3.9x8.7mm_P1.27mm

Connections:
+3V3: JP29.1 (A); also elsewhere on the board
+5V: JP8.1 (A), JP29.3 (B); also elsewhere on the board
/A0: U2.18 (B0); also elsewhere on the board
/A1: U2.17 (B1); also elsewhere on the board
/A2: U2.16 (B2); also elsewhere on the board
/A3: U2.15 (B3); also elsewhere on the board
/A4: U2.14 (B4); also elsewhere on the board
/A5: U2.13 (B5); also elsewhere on the board
/A6: U2.12 (B6); also elsewhere on the board
/A7: U2.11 (B7); also elsewhere on the board
/A8: U3.18 (B0); also elsewhere on the board
/A9: U3.17 (B1); also elsewhere on the board
/A10: U3.16 (B2); also elsewhere on the board
/A11: U3.15 (B3); also elsewhere on the board
/A12: U3.14 (B4); also elsewhere on the board
/A13: U3.13 (B5); also elsewhere on the board
/A14: U3.12 (B6); also elsewhere on the board
/A15: U3.11 (B7); also elsewhere on the board
/Buffers/Ec: J31.1, U21.4 (A2); also elsewhere on the board
/Buffers/Qc: J31.2, U21.5 (A3); also elsewhere on the board
/Buffers/VBuffer: C3.1, C4.1, JP8.3 (B), JP29.2 (C), R1.1, R2.1, R9.1, R10.1, R11.1, U2.1 (A->B), U2.20 (VCC), U3.1 (A->B), U3.20 (VCC), U5.1 (VCCA), U8.14 (VCC), U9.14 (VCC), U21.1 (A->B), U21.20 (VCC)
/CA0: U2.2 (A0); also elsewhere on the board
/CA1: U2.3 (A1); also elsewhere on the board
/CA2: U2.4 (A2); also elsewhere on the board
/CA3: U2.5 (A3); also elsewhere on the board
/CA4: U2.6 (A4); also elsewhere on the board
/CA5: U2.7 (A5); also elsewhere on the board
/CA6: U2.8 (A6); also elsewhere on the board
/CA7: U2.9 (A7); also elsewhere on the board
/CA8: U3.2 (A0); also elsewhere on the board
/CA9: U3.3 (A1); also elsewhere on the board
/CA10: U3.4 (A2); also elsewhere on the board
/CA11: U3.5 (A3); also elsewhere on the board
/CA12: U3.6 (A4); also elsewhere on the board
/CA13: U3.7 (A5); also elsewhere on the board
/CA14: U3.8 (A6); also elsewhere on the board
/CA15: U3.9 (A7); also elsewhere on the board
/CD0: U5.14 (B7); also elsewhere on the board
/CD1: U5.15 (B6); also elsewhere on the board
/CD2: U5.16 (B5); also elsewhere on the board
/CD3: U5.17 (B4); also elsewhere on the board
/CD4: U5.18 (B3); also elsewhere on the board
/CD5: U5.19 (B2); also elsewhere on the board
/CD6: U5.20 (B1); also elsewhere on the board
/CD7: U5.21 (B0); also elsewhere on the board
/CLKCPU: J30.3, U21.14 (B4); also elsewhere on the board
/CLKCPUc: J31.3, U21.6 (A4); also elsewhere on the board
/DB0: U5.10 (A7); also elsewhere on the board
/DB1: U5.9 (A6); also elsewhere on the board
/DB2: U5.8 (A5); also elsewhere on the board
/DB3: U5.7 (A4); also elsewhere on the board
/DB4: U5.6 (A3); also elsewhere on the board
/DB5: U5.5 (A2); also elsewhere on the board
/DB6: U5.4 (A1); also elsewhere on the board
/DB7: U5.3 (A0); also elsewhere on the board
/DDIR: U5.2 (A->B); also elsewhere on the board
/E: U9.2; also elsewhere on the board
/Ecpu: J30.1, U21.16 (B2); also elsewhere on the board
/Ee: U9.3; also elsewhere on the board
/PHI0: U21.17 (B1); also elsewhere on the board
/PHI0_c: U21.3 (A1); also elsewhere on the board
/Q: U9.5; also elsewhere on the board
/Qcpu: J30.2, U21.15 (B3); also elsewhere on the board
/Qe: U9.6; also elsewhere on the board
/R/~W: U8.5; also elsewhere on the board
/R/~W_e: R9.2, U8.6; also elsewhere on the board
/ZZ2: U21.2 (A0); also elsewhere on the board
/ZZ31: R2.2, U5.22 (CE); also elsewhere on the board
/ZZ32: R1.2, U2.19 (CE), U3.19 (CE), U8.1, U8.4, U8.10, U8.13; also elsewhere on the board
/ZZ33: U8.9; also elsewhere on the board
/ZZ34: U8.12; also elsewhere on the board
/~MRD: R11.2, U8.11; also elsewhere on the board
/~MWR: R10.2, U8.8; also elsewhere on the board
/~PHI0: U21.18 (B0); also elsewhere on the board
GND: C3.2, C4.2, U2.10 (GND), U3.10 (GND), U5.11 (GND), U5.12 (GND), U5.13 (GND), U8.7 (GND), U9.1, U9.4, U9.7 (GND), U9.10, U9.13, U21.10 (GND), U21.19 (CE); also elsewhere on the board
unnamed: J10.1, U8.3
unnamed: J11.1, U8.2
unnamed: J12.1, U9.9
unnamed: J13.1, U9.12
unnamed: J14.1, U9.8
unnamed: J15.1, U9.11
unnamed: J30.4, U21.13 (B5)
unnamed: J30.5, U21.12 (B6)
unnamed: J30.6, U21.11 (B7)
unnamed: J31.4, U21.7 (A5)
unnamed: J31.5, U21.8 (A6)
unnamed: J31.6, U21.9 (A7)
unnamed: JP8.2 (C), U5.23 (VCCB), U5.24 (VCCB)

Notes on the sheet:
One can place a SN74LVC245ANSR for 3.3V BUS and CPU or a SN74ABT245BNSR for 5V BUS and CPU on the Pads from U5 or leave the SN74LVCC3245ANSR for 3.3V BUS and 5V CPU.
For Address Buffers use SN74LVC245ANSR for 3.3V BUS and SN74ABT245BNSR for 5V BUS.

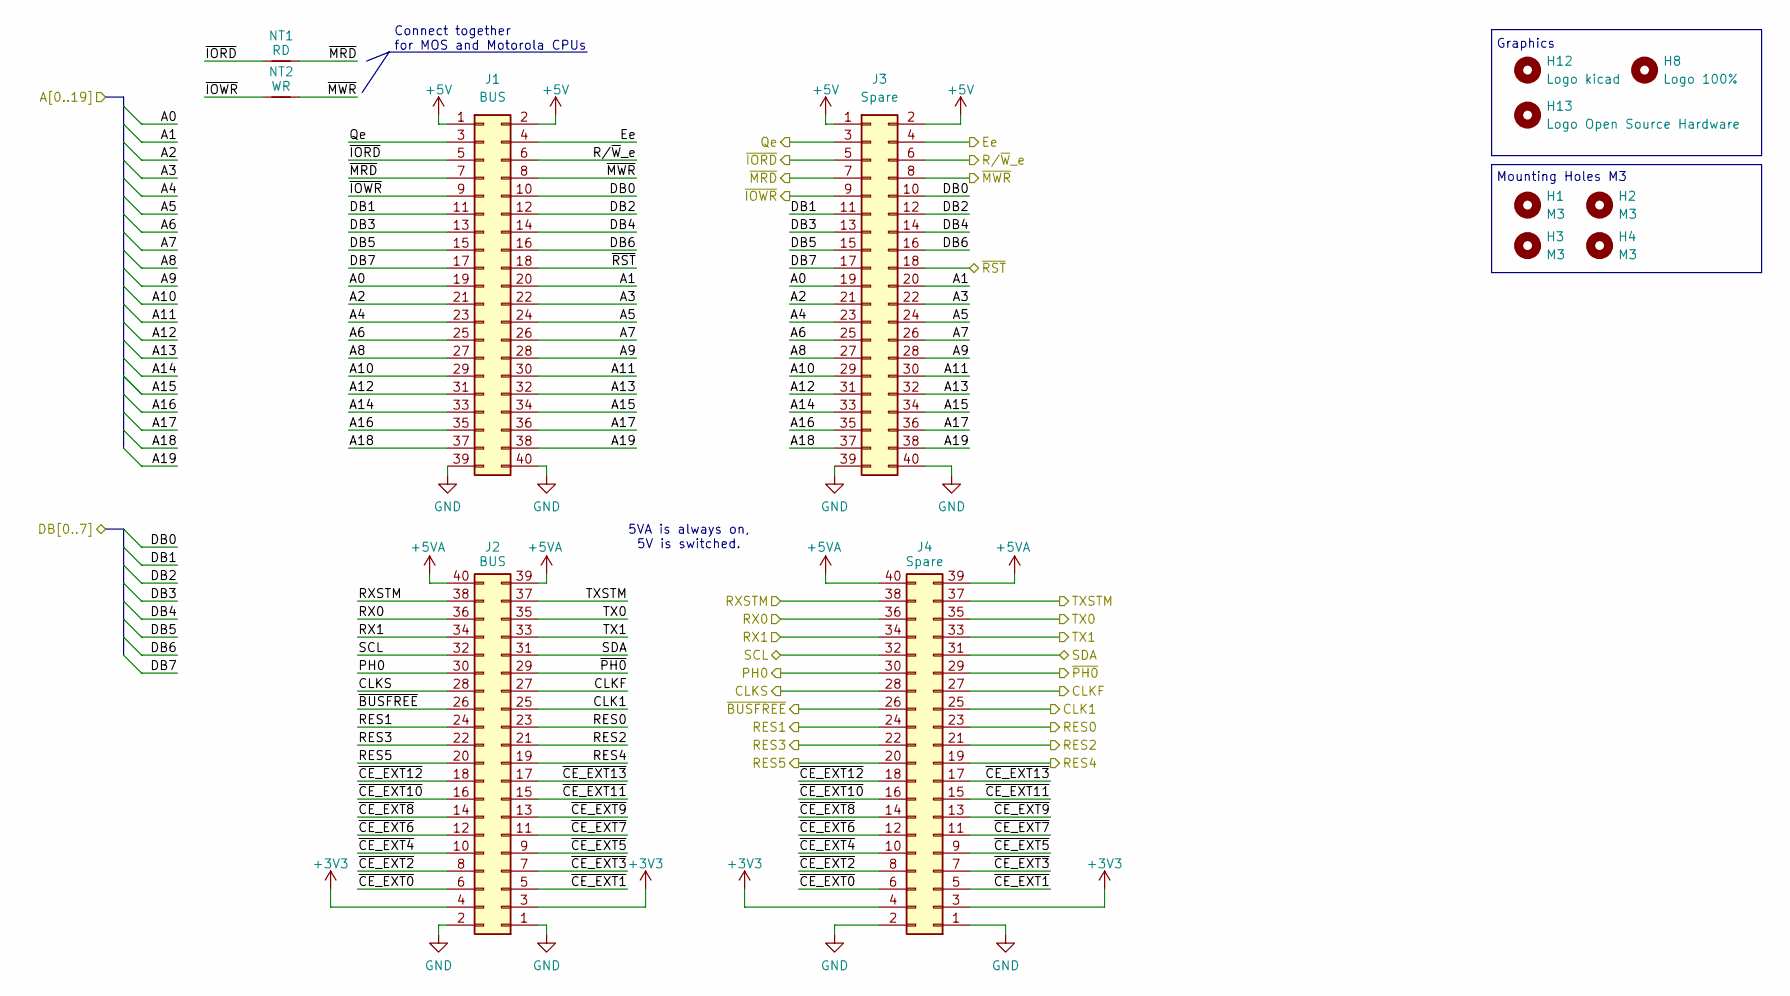
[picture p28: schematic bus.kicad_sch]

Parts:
H1, H2, H3, H4: M3; MountingHole_3.2mm_M3
H8: Logo 100%; Logo_100ProzentOffner_10x2.7mm
H12: Logo kicad; KiCad-Logo2_6mm_SilkScreen
H13: Logo Open Source Hardware; OSHW-Logo2_7.3x6mm_SilkScreen
J1, J2: BUS; PinSocket_2x20_P2.54mm_Vertical
J3, J4: Spare; PinSocket_2x20_P2.54mm_Vertical
NT1: RD; NetTie-2_SMD_Pad0.5mm
NT2: WR; NetTie-2_SMD_Pad0.5mm

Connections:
+3V3: J2.3, J2.4, J4.3, J4.4; also elsewhere on the board
+5V: J1.1, J1.2, J3.1, J3.2; also elsewhere on the board
+5VA: J2.39, J2.40, J4.39, J4.40; also elsewhere on the board
/A0: J1.19, J3.19; also elsewhere on the board
/A1: J1.20, J3.20; also elsewhere on the board
/A2: J1.21, J3.21; also elsewhere on the board
/A3: J1.22, J3.22; also elsewhere on the board
/A4: J1.23, J3.23; also elsewhere on the board
/A5: J1.24, J3.24; also elsewhere on the board
/A6: J1.25, J3.25; also elsewhere on the board
/A7: J1.26, J3.26; also elsewhere on the board
/A8: J1.27, J3.27; also elsewhere on the board
/A9: J1.28, J3.28; also elsewhere on the board
/A10: J1.29, J3.29; also elsewhere on the board
/A11: J1.30, J3.30; also elsewhere on the board
/A12: J1.31, J3.31; also elsewhere on the board
/A13: J1.32, J3.32; also elsewhere on the board
/A14: J1.33, J3.33; also elsewhere on the board
/A15: J1.34, J3.34; also elsewhere on the board
/Bus/A16: J1.35, J3.35
/Bus/A17: J1.36, J3.36
/Bus/A18: J1.37, J3.37
/Bus/A19: J1.38, J3.38
/Bus/CLK1: J2.25, J4.25
/Bus/RES2: J2.21, J4.21
/Bus/RES3: J2.22, J4.22
/Bus/RES4: J2.19, J4.19
/Bus/RES5: J2.20, J4.20
/Bus/RX0: J2.36, J4.36
/Bus/RX1: J2.34, J4.34
/Bus/RXSTM: J2.38, J4.38
/Bus/SCL: J2.32, J4.32
/Bus/SDA: J2.31, J4.31
/Bus/TX0: J2.35, J4.35
/Bus/TX1: J2.33, J4.33
/Bus/TXSTM: J2.37, J4.37
/Bus/~CE_EXT0: J2.6, J4.6
/Bus/~CE_EXT1: J2.5, J4.5
/Bus/~CE_EXT2: J2.8, J4.8
/Bus/~CE_EXT3: J2.7, J4.7
/Bus/~CE_EXT4: J2.10, J4.10
/Bus/~CE_EXT5: J2.9, J4.9
/Bus/~CE_EXT6: J2.12, J4.12
/Bus/~CE_EXT7: J2.11, J4.11
/Bus/~CE_EXT8: J2.14, J4.14
/Bus/~CE_EXT9: J2.13, J4.13
/Bus/~CE_EXT10: J2.16, J4.16
/Bus/~CE_EXT11: J2.15, J4.15
/Bus/~CE_EXT12: J2.18, J4.18
/Bus/~CE_EXT13: J2.17, J4.17
/CLKF: J2.27, J4.27; also elsewhere on the board
/CLKS: J2.28, J4.28
/DB0: J1.10, J3.10; also elsewhere on the board
/DB1: J1.11, J3.11; also elsewhere on the board
/DB2: J1.12, J3.12; also elsewhere on the board
/DB3: J1.13, J3.13; also elsewhere on the board
/DB4: J1.14, J3.14; also elsewhere on the board
/DB5: J1.15, J3.15; also elsewhere on the board
/DB6: J1.16, J3.16; also elsewhere on the board
/DB7: J1.17, J3.17; also elsewhere on the board
/Ee: J1.4, J3.4; also elsewhere on the board
/PHI0: J2.30, J4.30; also elsewhere on the board
/Qe: J1.3, J3.3; also elsewhere on the board
/RES0: J2.23, J4.23
/RES1: J2.24, J4.24
/R/~W_e: J1.6, J3.6; also elsewhere on the board
/ZZ42: J1.18, J3.18; also elsewhere on the board
/ZZ43: J2.26, J4.26; also elsewhere on the board
/~IORD: J1.5, J3.5, NT1.1
/~IOWR: J1.9, J3.9, NT2.1
/~MRD: J1.7, J3.7, NT1.2; also elsewhere on the board
/~MWR: J1.8, J3.8, NT2.2; also elsewhere on the board
/~PHI0: J2.29, J4.29; also elsewhere on the board
GND: J1.39, J1.40, J2.1, J2.2, J3.39, J3.40, J4.1, J4.2; also elsewhere on the board

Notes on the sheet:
5VA is always on, 5V is switched.
Graphics
Mounting Holes M3
Connect together for MOS and Motorola CPUs

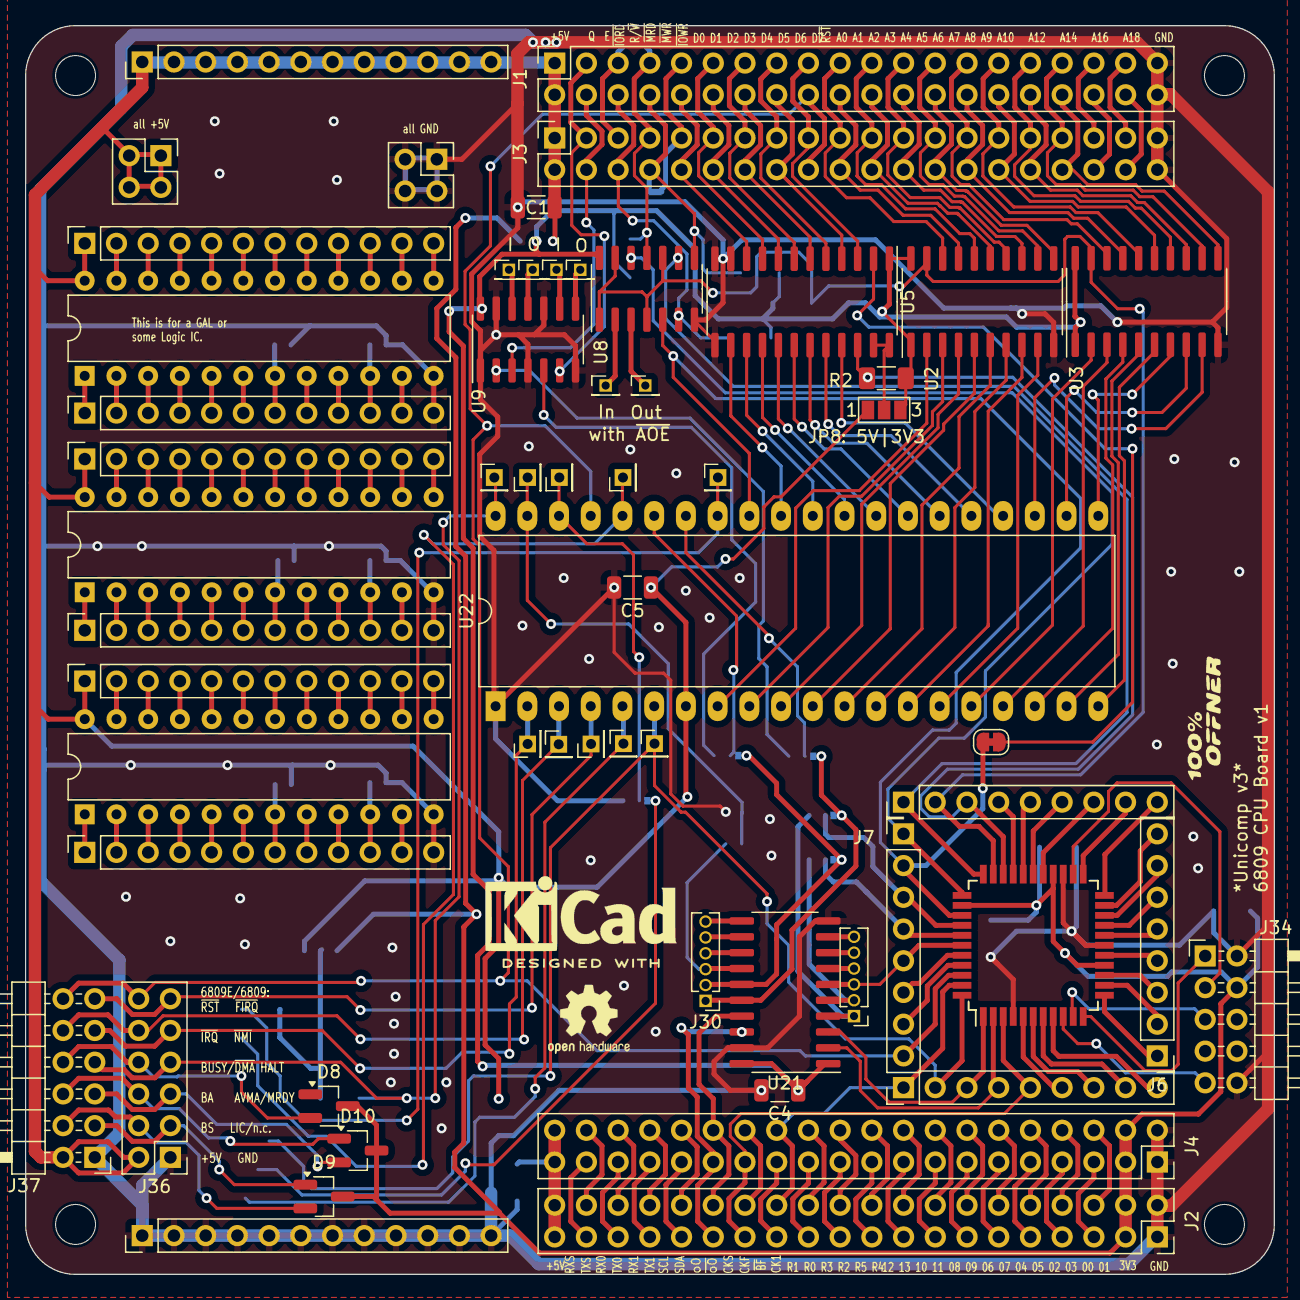
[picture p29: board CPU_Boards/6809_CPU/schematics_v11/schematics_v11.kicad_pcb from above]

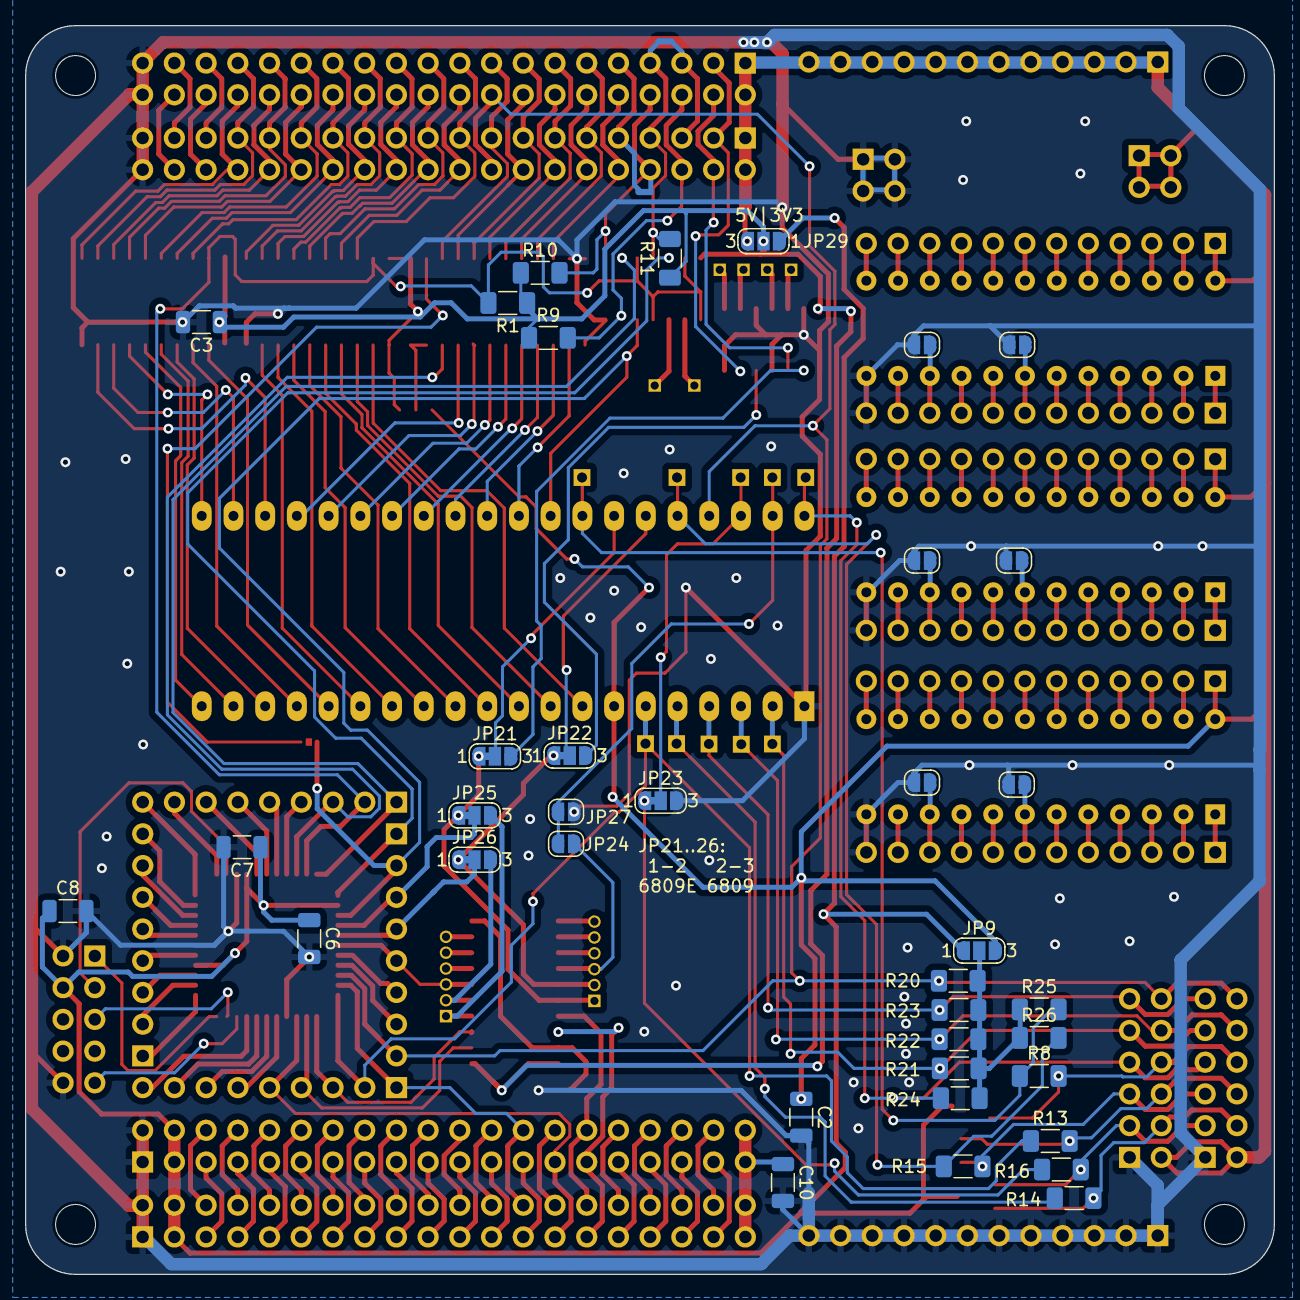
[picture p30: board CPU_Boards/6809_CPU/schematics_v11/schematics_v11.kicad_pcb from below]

Board: 2 copper layers, 100.0 x 100.0 mm, 105 parts (39 on the bottom side), 239 nets.

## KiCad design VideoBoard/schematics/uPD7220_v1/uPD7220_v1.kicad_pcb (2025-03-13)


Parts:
C1, C2: 100n; C_1206_3216Metric_Pad1.33x1.80mm_HandSolder
H1: Logo kicad; KiCad-Logo2_6mm_SilkScreen
H2: Logo Open Source Hardware; OSHW-Logo2_7.3x6mm_SilkScreen
J1: Inputs; PinHeader_2x17_P2.54mm_Vertical
J2: Conn_02x02_Counter_Clockwise; PinHeader_2x02_P2.54mm_Horizontal
J3: Outputs; PinHeader_2x17_P2.54mm_Vertical
R1: 1k5; R_1206_3216Metric_Pad1.30x1.75mm_HandSolder
U3: uPD7220; DIP-40_W15.24mm_Socket

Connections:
+5V: C1.1, C2.1, J1.33, J1.34, R1.1, U3.40 (+5V)
/A: J1.30
/A0#: J1.24, U3.11 (iA0)
/A1#: J1.21
/B: J1.31
/CGAB: J3.1
/CGAG: J3.4
/CGAI: J3.3
/CGAR: J3.2
/CH0: J1.27
/CRSR: J3.30, U3.2 (!DBIN)
/D0: J1.4, U3.12 (DB0)
/D1: J1.3, U3.13 (DB1)
/D2: J1.6, U3.14 (DB2)
/D3: J1.5, U3.15 (DB3)
/D4: J1.8, U3.16 (DB4)
/D5: J1.7, U3.17 (DB5)
/D6: J1.10, U3.18 (DB6)
/D7: J1.9, U3.19 (DB7)
/DE: J3.28, U3.5 (BLANK)
/DRQ: J2.1, J3.6, U3.7 (DRQ)
/HS: J3.29, U3.3 (HSYNC)
/In0: J3.25
/In1: J3.26
/In2: J3.27
/Out0: J1.12
/Out1: J1.11
/Out2: J1.14
/Out3: J1.13
/Out4: J1.16
/Out5: J1.15
/Out6: J1.18
/Out7: J1.17
/PHI2: J1.28
/R/~W: J1.22
/VA0: J3.23, U3.22 (AD0)
/VA1: J3.24, U3.23 (AD1)
/VA2: J3.21, U3.24 (AD2)
/VA3: J3.22, U3.25 (AD3)
/VA4: J3.19, U3.26 (AD4)
/VA5: J3.20, U3.27 (AD5)
/VA6: J3.17, U3.28 (AD6)
/VA7: J3.18, U3.29 (AD7)
/VA8: J3.15, U3.30 (AD8)
/VA9: J3.16, U3.31 (AD9)
/VA10: J3.13, U3.32 (AD10)
/VA11: J3.14, U3.33 (AD11)
/VA12: J3.11, U3.34 (AD12)
/VA13: J3.12, U3.35 (AD13)
/VA14: J3.9, U3.36 (AD14)
/VA15: J3.10, U3.37 (AD15)
/VA16: J3.7, U3.38 (A16)
/VA17: J3.8, U3.39 (A17)
/VA18: J3.5
/VCLK: J1.20, U3.1 (CKx2)
/VS: J3.31, U3.4 (VSYNC)
/Y: J1.29
/~CS: J1.19
/~INT: J1.32, J2.2, R1.2, U3.8 (DACK)
/~RD: J1.23, U3.9 (!RD)
/~RP: J3.32, U3.6 (ALE)
/~RST: J1.25
/~WR: J1.26, U3.10 (!WE)
GND: C1.2, C2.2, J1.1, J1.2, J2.3, J2.4, J3.33, J3.34, U3.20 (GND)

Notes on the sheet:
Graphics



Board: 2 copper layers, 99.0 x 45.5 mm, 9 parts (3 on the bottom side), 39 nets.

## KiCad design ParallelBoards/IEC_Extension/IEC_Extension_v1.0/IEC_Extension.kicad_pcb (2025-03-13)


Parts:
C1, C2, C5, C6, C7, C8, C9: 100n; C_1206_3216Metric_Pad1.33x1.80mm_HandSolder
J1, J2: DIN-6; C64_IEC
J3: JTAG; PinHeader_2x05_P2.54mm_Horizontal
J4: PIA; PinHeader_2x14_P2.54mm_Vertical
R1, R2, R3, R4, R5, R6, R7, R8, R9, R10, R12, R13, R14, R15, R16, R17: 1k; R_1206_3216Metric_Pad1.30x1.75mm_HandSolder
R11: 10k; R_1206_3216Metric_Pad1.30x1.75mm_HandSolder
U1: 74LS14; SOIC-14_3.9x8.7mm_P1.27mm
U2: 74LS06; SOIC-14_3.9x8.7mm_P1.27mm
U3: XC9572VQ44; TQFP-44_10x10mm_P0.8mm
U4: AZ1117CH2-33; SOT-223-3_TabPin2

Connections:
+3V3: C5.1, C6.1, C7.1, C8.1, J3.4, U3.15 (VCC), U3.26 (VCCIO), U3.35 (VCC), U4.3 (VO)
+5V: C1.1, C2.1, C9.1, J4.1, J4.2, R1.1, R2.1, R3.1, R4.1, R5.1, R6.1, R7.1, R8.1, R9.1, R10.1, R12.1, R13.1, R14.1, R15.1, R16.1, R17.1, U1.14 (VCC), U2.14 (VCC), U4.1 (VI)
/128/64: J4.7, R15.2, U3.41 (M6)
/ATN_DRV: J4.22, R14.2, U3.27 (M15)
/ATN_IN: U1.12, U3.16 (M17)
/ATN_OUT: U2.9, U3.3 (M17)
/ATN_SENS: J4.21, U3.23 (M14)
/CNT: J4.9, R7.2, U3.39 (M1)
/FCLK_IN: U1.6, U3.13 (M14)
/FCLK_OUT: U2.1, U3.6 (M5)
/FOUT/~FIN: J4.4, R11.1, U3.18 (M16)
/P1: J4.5, U3.1 (I/O/GCK3)
/P28: J4.19, U3.28 (M17)
/P29: J4.20, R8.2, U3.29 (M2)
/P30: J4.17, U3.30 (M5)
/P31: J4.18, R9.2, U3.31 (M6)
/P32: J4.15, U3.32 (M8)
/P33: J4.16, R16.2, U3.33 (I/O/GSR)
/P34: J4.13, U3.34 (I/O/GTS2)
/P36: J4.14, R17.2, U3.36 (I/O/GTS1)
/P37: J4.11, U3.37 (M15)
/P38: J4.12, U3.38 (M17)
/P43: J4.8, U3.43 (I/O/GCK1)
/P44: J4.6, U3.44 (I/O/GCK2)
/RSTDRV: U2.5, U3.42 (M8)
/RST_IN: U1.2, U3.2 (M15)
/RST_OUT: R10.2, U2.3, U3.5 (M2)
/SCLK_DRV: J4.26, R12.2, U3.20 (M5)
/SCLK_IN: U1.10, U3.14 (M15)
/SCLK_OUT: U2.11, U3.7 (M8)
/SCLK_SENS: J4.25, U3.19 (M2)
/SDATA_DRV: J4.24, R13.2, U3.22 (M11)
/SDATA_IN: U1.8, U3.12 (M11)
/SDATA_OUT: U2.13, U3.8 (M9)
/SDATA_SENS: J4.23, U3.21 (M8)
/SP: J4.10, R6.2, U3.40 (M5)
/TCK: J3.1, U3.11 (TCK)
/TDI: J3.9, U3.9 (TDI)
/TDO: J3.3, U3.24 (TDO)
/TMS: J3.5, U3.10 (TMS)
/~ATN: J1.3, J2.3, R1.2, U1.13, U2.8
/~DATA: J1.5, J2.5, R3.2, U1.9, U2.12
/~FCLK/SRQ: J1.1, J2.1, R5.2, U1.5, U2.2
/~RST#: J4.3, U2.6
/~RST: J1.6, J2.6, R4.2, U1.1, U2.4
/~SCLK: J1.4, J2.4, R2.2, U1.11, U2.10
GND: C1.2, C2.2, C5.2, C6.2, C7.2, C8.2, C9.2, J1.2, J2.2, J3.2, J3.10, J4.27, J4.28, R11.2, U1.3, U1.7 (GND), U2.7 (GND), U3.4 (GND), U3.17 (GND), U3.25 (GND), U4.2 (GND)



Board: 2 copper layers, 48.0 x 43.0 mm, 32 parts (23 on the bottom side), 47 nets.

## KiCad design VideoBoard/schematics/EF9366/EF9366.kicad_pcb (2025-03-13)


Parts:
C1, C2: 100n; C_1206_3216Metric_Pad1.33x1.80mm_HandSolder
H1: Logo kicad; KiCad-Logo2_6mm_SilkScreen
H2: Logo Open Source Hardware; OSHW-Logo2_7.3x6mm_SilkScreen
J1: Inputs; PinHeader_2x17_P2.54mm_Vertical
J2: Conn_02x01; PinHeader_1x02_P2.54mm_Horizontal
J3: Outputs; PinHeader_2x17_P2.54mm_Vertical
JP1: Format; PinHeader_1x03_P2.54mm_Vertical
JP2: WriteOnly; PinHeader_1x03_P2.54mm_Vertical
R1: 1k; R_1206_3216Metric_Pad1.30x1.75mm_HandSolder
U4: EF9366; DIP-40_W15.24mm_Socket

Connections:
+5V: C1.1, C2.1, J1.33, J1.34, JP1.3 (B), JP2.3 (B), R1.1, U4.40 (VCC)
/A: J1.30
/A0#: J1.24, U4.9 (A0)
/A1#: J1.21, U4.10 (A1)
/B: J1.31
/CH0: J1.27
/CRSR: J3.30
/D0: J1.4, U4.33 (D0)
/D1: J1.3, U4.32 (D1)
/D2: J1.6, U4.31 (D2)
/D3: J1.5, U4.30 (D3)
/D4: J1.8, U4.29 (D4)
/D5: J1.7, U4.28 (D5)
/D6: J1.10, U4.27 (D6)
/D7: J1.9, U4.26 (D7)
/DE: J3.28
/HS: J3.29
/In0: J3.25
/In1: J3.26
/In2: J3.27
/Out0: J1.12, U4.11 (A2)
/Out1: J1.11, U4.12 (A3)
/Out2: J1.14
/Out3: J1.13
/Out4: J1.16
/Out5: J1.15
/Out6: J1.18
/Out7: J1.17
/PHI2: J1.28
/R/~W: J1.22, U4.18 (R~W)
/VA0: J3.23, U4.37 (DAD0)
/VA1: J3.24, U4.39 (DAD1)
/VA2: J3.21, U4.38 (DAD2)
/VA3: J3.22, U4.4 (DAD3)
/VA4: J3.19, U4.3 (DAD4)
/VA5: J3.20, U4.2 (DAD5)
/VA6: J3.17, U4.5 (DAD6)
/VA7: J3.18, U4.6 (MSL0)
/VA8: J3.15, U4.36 (MSL1)
/VA9: J3.16, U4.7 (MSL2)
/VA10: J3.13, U4.35 (MSL3)
/VA11: J3.14, U4.22 (~ALL)
/VA12: J3.11, U4.34 (SYNC)
/VA13: J3.12, U4.25 (BLK)
/VA14: J3.9, U4.16 (VB)
/VA15: J3.10, U4.15 (Din)
/VA16: J3.7, U4.14 (~DW)
/VA17: J3.8, U4.24 (~WHITE)
/VA18: J3.5, U4.19 (MFREE/X9)
/VCLK: J1.20, U4.1 (CLK)
/VS: J3.31
/Y: J1.29
/~CS: J1.19, U4.17 (~E)
/~INT: J1.32, J2.1, R1.2, U4.13 (~IRQ)
/~RD: J1.23
/~RP: J3.32
/~RST: J1.25
/~WR: J1.26
GND: C1.2, C2.2, J1.1, J1.2, J2.2, J3.33, J3.34, JP1.1 (A), JP2.1 (A), U4.20 (GND)
unnamed: JP1.2 (C), U4.8 (FMAT)
unnamed: JP2.2 (C), U4.23 (WO)

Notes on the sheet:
Graphics



Board: 2 copper layers, 99.0 x 45.5 mm, 11 parts (5 on the bottom side), 39 nets.

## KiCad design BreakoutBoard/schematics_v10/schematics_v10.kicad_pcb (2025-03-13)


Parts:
C1, C2, C3, C6, C7, C8, C9, C14, C15, C16: 100n; C_1206_3216Metric
J8: E; PinHeader_1x01_P2.00mm_Vertical
J9: R/~{W}; PinHeader_1x01_P2.00mm_Vertical
J10: Conn_02x25_Odd_Even; PinHeader_2x25_P2.54mm_Vertical
J11: JTAG; PinHeader_2x05_P2.54mm_Horizontal
J12, J16: Conn_01x09; PinHeader_1x09_P2.54mm_Vertical
J13, J15: Conn_01x08; PinHeader_1x08_P2.54mm_Vertical
J14: Conn_02x25_Odd_Even; PinHeader_2x25_P2.54mm_Horizontal
JP1: IN/OUT; PinHeader_1x02_P2.54mm_Vertical
JP2: EN; PinHeader_1x02_P2.54mm_Vertical
JP3: Vcc; SolderJumper-3_P1.3mm_Open_RoundedPad1.0x1.5mm_NumberLabels
JP8: R/W; SolderJumper-2_P1.3mm_Bridged_RoundedPad1.0x1.5mm
JP9: PH2; SolderJumper-2_P1.3mm_Bridged_RoundedPad1.0x1.5mm
R1, R2: 10k; R_1206_3216Metric_Pad1.30x1.75mm_HandSolder
U2, U4: SN74LVC245; SO-20_12.8x7.5mm_P1.27mm; not fitted
U3, U6, U7: SN74LVCC4245ANSR; SO-24_5.3x15mm_P1.27mm
U8: XC9572VQ44; TQFP-44_10x10mm_P0.8mm

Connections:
+3V3: C3.1, C14.1, C15.1, C16.1, J11.4, JP3.1 (A), U8.15 (VCC), U8.26 (VCCIO), U8.35 (VCC); also elsewhere on the board
+5V: C1.1, C6.1, C7.1, J10.2, J14.2, JP3.3 (B), U3.1 (VCCA), U6.1 (VCCA), U7.1 (VCCA); also elsewhere on the board
+5VA: C2.1; also elsewhere on the board
/A0: U2.18 (B0), U6.21 (B0); also elsewhere on the board
/A1: U2.17 (B1), U6.20 (B1); also elsewhere on the board
/A2: U2.16 (B2), U6.19 (B2); also elsewhere on the board
/A3: U2.15 (B3), U6.18 (B3); also elsewhere on the board
/A4: U2.14 (B4), U6.17 (B4); also elsewhere on the board
/A5: U2.13 (B5), U6.16 (B5); also elsewhere on the board
/A6: U2.12 (B6), U6.15 (B6); also elsewhere on the board
/A7: U2.11 (B7), U6.14 (B7); also elsewhere on the board
/A8: U3.21 (B0), U4.18 (B0); also elsewhere on the board
/A9: U3.20 (B1), U4.17 (B1); also elsewhere on the board
/A10: U3.19 (B2), U4.16 (B2); also elsewhere on the board
/A11: U3.18 (B3), U4.15 (B3); also elsewhere on the board
/A12: U3.17 (B4), U4.14 (B4); also elsewhere on the board
/A13: U3.16 (B5), U4.13 (B5); also elsewhere on the board
/A14: U3.15 (B6), U4.12 (B6); also elsewhere on the board
/A15: U3.14 (B7), U4.11 (B7); also elsewhere on the board
/D0: J10.27, J14.27; also elsewhere on the board
/D1: J10.26, J14.26; also elsewhere on the board
/D2: J10.25, J14.25; also elsewhere on the board
/D3: J10.24, J14.24; also elsewhere on the board
/D4: J10.23, J14.23; also elsewhere on the board
/D5: J10.22, J14.22; also elsewhere on the board
/D6: J10.21, J14.21; also elsewhere on the board
/D7: J10.20, J14.20; also elsewhere on the board
/E: J8.1, JP9.2 (B)
/EA0: J10.18, J14.18, U2.2 (A0), U6.3 (A0)
/EA1: J10.17, J14.17, U2.3 (A1), U6.4 (A1)
/EA2: J10.16, J14.16, U2.4 (A2), U6.5 (A2)
/EA3: J10.15, J14.15, U2.5 (A3), U6.6 (A3)
/EA4: J10.14, J14.14, U2.6 (A4), U6.7 (A4)
/EA5: J10.13, J14.13, U2.7 (A5), U6.8 (A5)
/EA6: J10.12, J14.12, U2.8 (A6), U6.9 (A6)
/EA7: J10.11, J14.11, U2.9 (A7), U6.10 (A7)
/EA8: J10.10, J14.10, U3.3 (A0), U4.2 (A0)
/EA9: J10.9, J14.9, U3.4 (A1), U4.3 (A1)
/EA10: J10.8, J14.8, U3.5 (A2), U4.4 (A2)
/EA11: J10.7, J14.7, U3.6 (A3), U4.5 (A3)
/EA12: J10.6, J14.6, U3.7 (A4), U4.6 (A4)
/EA13: J10.5, J14.5, U3.8 (A5), U4.7 (A5)
/EA14: J10.4, J14.4, U3.9 (A6), U4.8 (A6)
/EA15: J10.3, J14.3, U3.10 (A7), U4.9 (A7)
/IN/~OUT: JP1.2 (B), R2.2, U2.1 (A->B), U3.2 (A->B), U4.1 (A->B), U6.2 (A->B), U7.2 (A->B)
/PA0: J10.42, J14.42
/PA1: J10.41, J14.41
/PA2: J10.40, J14.40
/PA3: J10.39, J14.39
/PA4: J10.38, J14.38
/PA5: J10.37, J14.37
/PA6: J10.36, J14.36
/PA7: J10.35, J14.35
/PB0: J10.34, J14.34
/PB1: J10.33, J14.33
/PB2: J10.32, J14.32
/PB3: J10.31, J14.31
/PB4: J10.30, J14.30
/PB5: J10.29, J14.29
/PB6: J10.28, J14.28
/PHI2_e: JP9.1 (A); also elsewhere on the board
/Pin45: J10.45, J14.45
/Pin46: J10.46, J14.46
/Pin47: J10.47, J14.47
/Pin48: J10.48, J14.48
/Pin49: J10.49, J14.49
/Pin50: J10.50, J14.50
/RW: J9.1, JP8.2 (B)
/R/~W_e: JP8.1 (A); also elsewhere on the board
/TCK: J11.1, U8.11 (TCK)
/TDI: J11.9, U8.9 (TDI)
/TDO: J11.3, U8.24 (TDO)
/TMS: J11.5, U8.10 (TMS)
/ZZ1: J16.3, U8.1 (I/O/GCK3)
/ZZ2: J16.4, U8.2 (M15)
/ZZ3: J16.5, U8.3 (M17)
/ZZ5: J16.6, U8.5 (M2)
/ZZ6: J16.7, U8.6 (M5)
/ZZ7: J16.8, U8.7 (M8)
/ZZ8: J16.9, U8.8 (M9)
/ZZ12: J13.1, U8.12 (M11)
/ZZ13: J13.2, U8.13 (M14)
/ZZ14: J13.3, U8.14 (M15)
/ZZ16: J13.4, U8.16 (M17)
/ZZ18: J13.5, U8.18 (M16)
/ZZ19: J13.6, U8.19 (M2)
/ZZ20: J13.7, U8.20 (M5)
/ZZ21: J13.8, U8.21 (M8)
/ZZ22: J12.9, U8.22 (M11)
/ZZ23: J12.8, U8.23 (M14)
/ZZ27: J12.7, U8.27 (M15)
/ZZ28: J12.6, U8.28 (M17)
/ZZ29: J12.5, U8.29 (M2)
/ZZ30: J12.4, U8.30 (M5)
/ZZ31: J12.3, U8.31 (M6)
/ZZ32: J12.2, U8.32 (M8)
/ZZ33: J12.1, U8.33 (I/O/GSR)
/ZZ34: J15.1, U8.34 (I/O/GTS2)
/ZZ36: J15.2, U8.36 (I/O/GTS1)
/ZZ37: J15.3, U8.37 (M15)
/ZZ38: J15.4, U8.38 (M17)
/ZZ39: J15.5, U8.39 (M1)
/ZZ40: J15.6, U8.40 (M5)
/ZZ41: J15.7, U8.41 (M6)
/ZZ42: J15.8, U8.42 (M8)
/ZZ43: J16.1, U8.43 (I/O/GCK1)
/ZZ44: J16.2, U8.44 (I/O/GCK2)
/~ADDR_EN: JP2.2 (B), R1.2, U2.19 (CE), U3.22 (CE), U4.19 (CE), U6.22 (CE), U7.22 (CE)
/~IRQ2: J10.43, J14.43
/~IRQ: J10.44, J14.44
/~RST: J10.19, J14.19; also elsewhere on the board
GND: C1.2, C2.2, C3.2, C6.2, C7.2, C8.2, C9.2, C14.2, C15.2, C16.2, J10.1, J11.2, J11.10, J14.1, JP1.1 (A), JP2.1 (A), U2.10 (GND), U3.11 (GND), U3.12 (GND), U3.13 (GND), U4.10 (GND), U6.11 (GND), U6.12 (GND), U6.13 (GND), U7.11 (GND), U7.12 (GND), U7.13 (GND), U8.4 (GND), U8.17 (GND), U8.25 (GND); also elsewhere on the board
VBuffer: C8.1, C9.1, JP3.2 (C), R1.1, R2.1, U2.20 (VCC), U3.23 (VCCB), U3.24 (VCCB), U4.20 (VCC), U6.23 (VCCB), U6.24 (VCCB), U7.23 (VCCB), U7.24 (VCCB); also elsewhere on the board

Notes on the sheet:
Wider Footprint.
For Address Buffers use SN74LVC245ANSR for 3.3V BUS and SN74ABT245BNSR for 5V BUS.
One can place a SN74LVC245ANSR for 3.3V BUS and CPU or a SN74ABT245BNSR for 5V BUS and CPU on the Pads from U5 or leave the SN74LVCC3245ANSR for 3.3V BUS and 5V CPU.
The difference between the SN74LVCC4245ANSR and the SN74LVCC3245BNSR is the switched 5V and 3V3 Rails.

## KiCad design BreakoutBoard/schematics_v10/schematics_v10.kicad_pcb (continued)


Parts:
C4, C5: 100n; C_1206_3216Metric
H1, H2, H3, H4: M3; MountingHole_3.2mm_M3
H5: Logo kicad; KiCad-Logo2_6mm_SilkScreen
H6: Logo Open Source Hardware; OSHW-Logo2_7.3x6mm_SilkScreen
J1, J2: BUS; PinSocket_2x20_P2.54mm_Vertical
J3, J4: Spare; PinSocket_2x20_P2.54mm_Vertical
J6: ~{DOE}; PinHeader_1x01_P2.00mm_Vertical
J7: R/~{W}_e; PinHeader_1x01_P2.00mm_Vertical
U1: SN74LVCC3245ANSR; SO-24_5.3x15mm_P1.27mm
U5: SN74LVC245; SO-20_12.8x7.5mm_P1.27mm; not fitted

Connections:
+3V3: C4.1, J2.3, J2.4, J4.3, J4.4; also elsewhere on the board
+5V: C5.1, J1.1, J1.2, J3.1, J3.2, U1.23 (VCCB), U1.24 (VCCB), U5.20 (VCC); also elsewhere on the board
+5VA: J2.39, J2.40, J4.39, J4.40; also elsewhere on the board
/A0: J1.19, J3.19; also elsewhere on the board
/A1: J1.20, J3.20; also elsewhere on the board
/A2: J1.21, J3.21; also elsewhere on the board
/A3: J1.22, J3.22; also elsewhere on the board
/A4: J1.23, J3.23; also elsewhere on the board
/A5: J1.24, J3.24; also elsewhere on the board
/A6: J1.25, J3.25; also elsewhere on the board
/A7: J1.26, J3.26; also elsewhere on the board
/A8: J1.27, J3.27; also elsewhere on the board
/A9: J1.28, J3.28; also elsewhere on the board
/A10: J1.29, J3.29; also elsewhere on the board
/A11: J1.30, J3.30; also elsewhere on the board
/A12: J1.31, J3.31; also elsewhere on the board
/A13: J1.32, J3.32; also elsewhere on the board
/A14: J1.33, J3.33; also elsewhere on the board
/A15: J1.34, J3.34; also elsewhere on the board
/A16: J1.35, J3.35
/A17: J1.36, J3.36
/A18: J1.37, J3.37
/A19: J1.38, J3.38
/Bus/DB0: J1.10, J3.10, U1.10 (A7), U5.9 (A7)
/Bus/DB1: J1.11, J3.11, U1.9 (A6), U5.8 (A6)
/Bus/DB2: J1.12, J3.12, U1.8 (A5), U5.7 (A5)
/Bus/DB3: J1.13, J3.13, U1.7 (A4), U5.6 (A4)
/Bus/DB4: J1.14, J3.14, U1.6 (A3), U5.5 (A3)
/Bus/DB5: J1.15, J3.15, U1.5 (A2), U5.4 (A2)
/Bus/DB6: J1.16, J3.16, U1.4 (A1), U5.3 (A1)
/Bus/DB7: J1.17, J3.17, U1.3 (A0), U5.2 (A0)
/Bus/~CE_EXT0: J2.6, J4.6
/Bus/~CE_EXT1: J2.5, J4.5
/Bus/~CE_EXT2: J2.8, J4.8
/Bus/~CE_EXT3: J2.7, J4.7
/Bus/~CE_EXT4: J2.10, J4.10
/Bus/~CE_EXT5: J2.9, J4.9
/Bus/~CE_EXT6: J2.12, J4.12
/Bus/~CE_EXT7: J2.11, J4.11
/Bus/~CE_EXT8: J2.14, J4.14
/Bus/~CE_EXT9: J2.13, J4.13
/Bus/~CE_EXT10: J2.16, J4.16
/Bus/~CE_EXT11: J2.15, J4.15
/Bus/~CE_EXT12: J2.18, J4.18
/Bus/~CE_EXT13: J2.17, J4.17
/CLK1: J2.25, J4.25
/CLKF: J2.27, J4.27
/CLKS: J2.28, J4.28
/D0: U1.14 (B7), U5.11 (B7); also elsewhere on the board
/D1: U1.15 (B6), U5.12 (B6); also elsewhere on the board
/D2: U1.16 (B5), U5.13 (B5); also elsewhere on the board
/D3: U1.17 (B4), U5.14 (B4); also elsewhere on the board
/D4: U1.18 (B3), U5.15 (B3); also elsewhere on the board
/D5: U1.19 (B2), U5.16 (B2); also elsewhere on the board
/D6: U1.20 (B1), U5.17 (B1); also elsewhere on the board
/D7: U1.21 (B0), U5.18 (B0); also elsewhere on the board
/PH0: J2.30, J4.30
/PHI1_e: J1.3, J3.3
/PHI2_e: J1.4, J3.4; also elsewhere on the board
/RES0: J2.23, J4.23
/RES1: J2.24, J4.24
/RES2: J2.21, J4.21
/RES3: J2.22, J4.22
/RES4: J2.19, J4.19
/RES5: J2.20, J4.20
/RX0: J2.36, J4.36
/RX1: J2.34, J4.34
/RXSTM: J2.38, J4.38
/R/~W_e: J1.6, J3.6, J7.1, U1.2 (A->B), U5.1 (A->B); also elsewhere on the board
/SCL: J2.32, J4.32
/SDA: J2.31, J4.31
/TX0: J2.35, J4.35
/TX1: J2.33, J4.33
/TXSTM: J2.37, J4.37
/~BUSFREE: J2.26, J4.26
/~DOE: J6.1, U1.22 (CE), U5.19 (CE)
/~IORD: J1.5, J3.5
/~IOWR: J1.9, J3.9
/~MRD: J1.7, J3.7
/~MWR: J1.8, J3.8
/~PH0: J2.29, J4.29
/~RST: J1.18, J3.18; also elsewhere on the board
GND: C4.2, C5.2, J1.39, J1.40, J2.1, J2.2, J3.39, J3.40, J4.1, J4.2, U1.11 (GND), U1.12 (GND), U1.13 (GND), U5.10 (GND); also elsewhere on the board
VBuffer: U1.1 (VCCA); also elsewhere on the board

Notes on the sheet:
Graphics
5VA is always on, 5V is switched.
Mounting Holes M3
The difference between the SN74LVCC4245ANSR and the SN74LVCC3245BNSR is the switched 5V and 3V3 Rails.



Board: 2 copper layers, 100.0 x 100.0 mm, 48 parts (13 on the bottom side), 165 nets.

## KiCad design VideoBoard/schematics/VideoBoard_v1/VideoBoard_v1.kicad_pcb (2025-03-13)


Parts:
C1, C2, C3, C4, C5, C6, C7, C8, C9, C10, C11, C12, C13, C14, C15, C16, C17, C18, C19, C20, C21, C22, C23: 100n; C_0603_1608Metric_Pad1.08x0.95mm_HandSolder
C24, C25: 22u/16; CP_EIA-7343-31_Kemet-D
J6, J8: JTAG; PinHeader_2x05_P2.54mm_Horizontal
J7: Inputs; PinSocket_2x17_P2.54mm_Vertical
J9: Outputs; PinSocket_2x17_P2.54mm_Vertical
J10: EGA Video; PinHeader_2x05_P2.54mm_Horizontal
J11, J12, J13, J15, J16, J17, J18, J19, J22, J23, J24, J25, J27, J28: .; PinHeader_1x01_P1.27mm_Vertical
J14: RGB2HDMI; PinHeader_2x03_P2.54mm_Horizontal
JP1: 5Vext; PinHeader_1x02_P2.54mm_Vertical
L1: L_Small; L_1210_3225Metric_Pad1.42x2.65mm_HandSolder
Q1, Q2, Q3, Q4: BC849; SOT-23_Handsoldering
R1: 3k3; R_1206_3216Metric_Pad1.30x1.75mm_HandSolder
R2: 8k2; R_1206_3216Metric_Pad1.30x1.75mm_HandSolder
R3, R8, R9: 1k; R_1206_3216Metric_Pad1.30x1.75mm_HandSolder
R4: 270E; R_1206_3216Metric_Pad1.30x1.75mm_HandSolder
R5: 470E; R_1206_3216Metric_Pad1.30x1.75mm_HandSolder
R6: 82E; R_1206_3216Metric_Pad1.30x1.75mm_HandSolder
R7, R10: 100E; R_1206_3216Metric_Pad1.30x1.75mm_HandSolder
U1: SN74LVCC4245ANSR; SO-24_5.3x15mm_P1.27mm
U2, U8, U9, U10, U11: 74LS541; TSSOP-20_4.4x6.5mm_P0.65mm
U3, U4, U7: IS63WV1288DBLL-10xLI; TSOP-II-32_21.0x10.2mm_P1.27mm
U5: XC9572XL-TQ100; TQFP-100_14x14mm_P0.5mm
U6: EPM570T144; LQFP-144_20x20mm_P0.5mm
U12: SN74LVC125AD; SOIC-14_3.9x8.7mm_P1.27mm

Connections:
+3V3: C1.1, C2.1, C3.1, C6.1, C7.1, C8.1, C9.1, C11.1, C12.1, C13.1, C14.1, C15.1, C16.1, C17.1, C18.1, C19.1, C20.1, C21.1, C22.1, C23.1, U1.23 (VCCB), U1.24 (VCCB), U2.20 (VCC), U3.8 (VDD), U3.24 (VDD), U4.8 (VDD), U4.24 (VDD), U5.5 (VCC), U5.26 (VCCIO), U5.38 (VCCIO), U5.51 (VCCIO), U5.57 (VCC), U5.88 (VCCIO), U5.98 (VCC), U6.9 (VCCIO1), U6.19 (VCCINT), U6.25 (VCCIO1), U6.46 (VCCIO1), U6.56 (VCCINT), U6.64 (VCCIO1), U6.82 (VCCIO2), U6.90 (VCCINT), U6.100 (VCCIO2), U6.116 (VCCIO2), U6.126 (VCCINT), U6.136 (VCCIO2), U7.8 (VDD), U7.24 (VDD), U11.20 (VCC), U12.14 (VCC); also elsewhere on the board
+5V: C4.1, C5.1, C10.1, J9.33, J9.34, J14.6, JP1.2 (B), L1.1, U1.1 (VCCA), U8.20 (VCC), U9.20 (VCC), U10.20 (VCC); also elsewhere on the board
/8: U6.144 (IO2_144), U9.2 (A0)
/11: U6.1 (IO1_1), U9.3 (A1)
/12: U6.2 (IO1_2), U9.4 (A2)
/13: U6.3 (IO1_3), U9.5 (A3)
/14: U6.4 (IO1_4), U9.6 (A4)
/15: U6.5 (IO1_5), U9.7 (A5)
/16: U6.6 (IO1_6), U9.8 (A6)
/20: U6.7 (IO1_7), U9.9 (A7)
/73: J15.1, U6.73 (IO2_73)
/77: U2.11 (Y7), U6.77 (IO2_77)
/78: U2.12 (Y6), U6.78 (IO2_78)
/79: U2.13 (Y5), U6.79 (IO2_79)
/80: U2.14 (Y4), U6.80 (IO2_80)
/81: U2.15 (Y3), U6.81 (IO2_81)
/84: U2.16 (Y2), U6.84 (IO2_84)
/85: U2.17 (Y1), U6.85 (IO2_85)
/86: U2.18 (Y0), U6.86 (IO2_86)
/125: U6.125 (IO2_125), U11.18 (Y0)
/127: U6.127 (IO2_127), U11.17 (Y1)
/129: U6.129 (IO2_129), U11.11 (Y7)
/130: U6.130 (IO2_130), U11.12 (Y6)
/131: U6.131 (IO2_131), U11.13 (Y5)
/132: U6.132 (IO2_132), U11.14 (Y4)
/133: U6.133 (IO2_133), U11.15 (Y3)
/134: U6.134 (IO2_134), U11.16 (Y2)
/137: J16.1, U6.137 (IO2_137)
/138: J17.1, U6.138 (IO2_138)
/139: J18.1, U6.139 (IO2_139)
/140: J19.1, U6.140 (IO2_140)
/A: J9.30, R8.1
/A0: U5.96, U10.5 (A3); also elsewhere on the board
/A0#: J9.24, U10.15 (Y3)
/A1: U5.95, U10.6 (A4); also elsewhere on the board
/A1#: J9.21, U10.14 (Y4)
/A2: U5.94; also elsewhere on the board
/A3: U5.93; also elsewhere on the board
/A4: U5.92; also elsewhere on the board
/A5: U5.91; also elsewhere on the board
/A6: U5.90; also elsewhere on the board
/A7: U5.89; also elsewhere on the board
/A8: U5.87; also elsewhere on the board
/A9: U5.86; also elsewhere on the board
/A10: U5.85; also elsewhere on the board
/A11: U5.82; also elsewhere on the board
/A12: U5.81; also elsewhere on the board
/A13: U5.79; also elsewhere on the board
/A14: U5.78; also elsewhere on the board
/A15: U5.77; also elsewhere on the board
/A_out: J14.5, Q3.2 (E), R7.1
/B: J9.31, R9.1
/B0: J10.5, U8.14 (Y4)
/B0o: U6.29 (IO1_29), U8.6 (A4)
/B1: J10.7, U8.16 (Y2)
/B1o: U6.27 (IO1_27), U8.4 (A2)
/B_out: J14.3, Q4.2 (E), R10.1
/Bus/D0: J9.4, U1.3 (A0)
/Bus/D1: J9.3, U1.4 (A1)
/Bus/D2: J9.6, U1.5 (A2)
/Bus/D3: J9.5, U1.6 (A3)
/Bus/D4: J9.8, U1.7 (A4)
/Bus/D5: J9.7, U1.8 (A5)
/Bus/D6: J9.10, U1.9 (A6)
/Bus/D7: J9.9, U1.10 (A7)
/CC0: U5.99 (I/O/GSR), U6.109 (IO2_109)
/CC1: U5.1 (I/O/GTS3), U6.108 (IO2_108)
/CC2: U5.3 (I/O/GTS1), U6.107 (IO2_107)
/CC3: U5.4 (I/O/GTS2), U6.106 (IO2_106)
/CC4: U5.6, U6.105 (IO2_105)
/CC5: U5.8, U6.104 (IO2_104)
/CC6: U5.9, U6.103 (IO2_103)
/CC7: U5.10, U6.102 (IO2_102)
/CC8: U5.11, U6.101 (IO2_101)
/CC9: U5.12, U6.98 (IO2_98)
/CC10: U5.13, U6.97 (IO2_97)
/CC11: U5.14, U6.96 (IO2_96)
/CC12: U5.15, U6.95 (IO2_95)
/CC13: U5.16, U6.94 (IO2_94)
/CC14: U5.17, U6.93 (IO2_93)
/CC15: U5.18, U6.91 (IO2_91/GCLK3)
/CC16: U5.20, U6.89 (IO2_89/GCLK2)
/CC17: U5.22 (I/O/GCK1), U6.88 (IO2_88)
/CC18: U5.23 (I/O/GCK2), U6.87 (IO2_87)
/CD0: U1.21 (B0), U6.22 (IO1_22)
/CD1: U1.20 (B1), U6.21 (IO1_21)
/CD2: U1.19 (B2), U6.20 (IO1_20/GCLK1)
/CD3: U1.18 (B3), U6.16 (IO1_16)
/CD4: U1.17 (B4), U6.15 (IO1_15)
/CD5: U1.16 (B5), U6.14 (IO1_14)
/CD6: U1.15 (B6), U6.13 (IO1_13)
/CD7: U1.14 (B7), U6.12 (IO1_12)
/CGAB: J7.1, U11.5 (A3)
/CGAG: J7.4, U11.8 (A6)
/CGAI: J7.3, U11.7 (A5)
/CGAR: J7.2, U11.6 (A4)
/CH0: J9.27
/CLKF: U6.18 (IO1_18/GCLK0); also elsewhere on the board
/CRSR: J7.30, U2.7 (A5)
/CR/~W: U1.2 (A->B), U6.8 (IO1_8)
/DB0: U6.120 (IO2_120); also elsewhere on the board
/DB1: U6.119 (IO2_119); also elsewhere on the board
/DB2: U6.118 (IO2_118); also elsewhere on the board
/DB3: U6.117 (IO2_117); also elsewhere on the board
/DB4: U6.114 (IO2_114); also elsewhere on the board
/DB5: U6.113 (IO2_113); also elsewhere on the board
/DB6: U6.112 (IO2_112); also elsewhere on the board
/DB7: U6.111 (IO2_111); also elsewhere on the board
/DE: J7.28, U2.5 (A3)
/G0: J10.4, U8.13 (Y5)
/G0o: U6.30 (IO1_30), U8.7 (A5)
/G1: J10.6, U8.15 (Y3)
/G1o: U6.28 (IO1_28), U8.5 (A3)
/GA0: U3.1 (A0), U4.1 (A0), U5.52, U7.1 (A0)
/GA1: U3.2 (A1), U4.2 (A1), U5.49, U7.2 (A1)
/GA2: U3.3 (A2), U4.3 (A2), U5.41, U7.3 (A2)
/GA3: U3.4 (A3), U4.4 (A3), U5.39, U7.4 (A3)
/GA4: U3.13 (A4), U4.13 (A4), U5.35, U7.13 (A4)
/GA5: U3.14 (A5), U4.14 (A5), U5.32, U7.14 (A5)
/GA6: U3.15 (A6), U4.15 (A6), U5.29, U7.15 (A6)
/GA7: U3.16 (A7), U4.16 (A7), U5.27 (I/O/GCK3), U7.16 (A7)
/GA8: U3.17 (A8), U4.17 (A8), U5.25, U7.17 (A8)
/GA9: U3.18 (A9), U4.18 (A9), U5.28, U7.18 (A9)
/GA10: U3.19 (A10), U4.19 (A10), U5.30, U7.19 (A10)
/GA11: U3.20 (A11), U4.20 (A11), U5.33, U7.20 (A11)
/GA12: U3.21 (A12), U4.21 (A12), U5.36, U7.21 (A12)
/GA13: U3.29 (A13), U4.29 (A13), U5.37, U7.29 (A13)
/GA14: U3.30 (A14), U4.30 (A14), U5.40, U7.30 (A14)
/GA15: U3.31 (A15), U4.31 (A15), U5.42, U7.31 (A15)
/GA16: U3.32 (A16), U4.32 (A16), U5.50, U7.32 (A16)
/GD0: U3.6 (I/O0), U6.67 (IO1_67)
/GD1: U3.7 (I/O1), U6.66 (IO1_66)
/GD2: U3.10 (I/O2), U6.63 (IO1_63)
/GD3: U3.11 (I/O3), U6.62 (IO1_62)
/GD4: U3.22 (I/O4), U6.70 (IO1_70)
/GD5: U3.23 (I/O5), U6.71 (IO1_71)
/GD6: U3.26 (I/O6), U6.69 (IO1_69)
/GD7: U3.27 (I/O7), U6.68 (IO1_68)
/GD8: U4.6 (I/O0), U6.53 (IO1_53)
/GD9: U4.7 (I/O1), U6.52 (IO1_52)
/GD10: U4.10 (I/O2), U6.51 (IO1_51)
/GD11: U4.11 (I/O3), U6.50 (IO1_50)
/GD12: U4.22 (I/O4), U6.58 (IO1_58)
/GD13: U4.23 (I/O5), U6.59 (IO1_59)
/GD14: U4.26 (I/O6), U6.57 (IO1_57)
/GD15: U4.27 (I/O7), U6.55 (IO1_55)
/GD16: U6.41 (IO1_41), U7.6 (I/O0)
/GD17: U6.40 (IO1_40), U7.7 (I/O1)
/GD18: U6.39 (IO1_39), U7.10 (I/O2)
/GD19: U6.38 (IO1_38), U7.11 (I/O3)
/GD20: U6.44 (IO1_44), U7.22 (I/O4)
/GD21: U6.45 (IO1_45), U7.23 (I/O5)
/GD22: U6.43 (IO1_43), U7.26 (I/O6)
/GD23: U6.42 (IO1_42), U7.27 (I/O7)
/HS: J7.29, U2.6 (A4)
/HSout: U6.24 (IO1_24), U8.3 (A1)
/HSync: J10.8, J14.2, U8.17 (Y1)
/In0: J7.25, U2.2 (A0)
/In1: J7.26, U2.3 (A1)
/In2: J7.27, U2.4 (A2)
/Out0: J9.12, U9.11 (Y7)
/Out1: J9.11, U9.12 (Y6)
/Out2: J9.14, U9.13 (Y5)
/Out3: J9.13, U9.14 (Y4)
/Out4: J9.16, U9.15 (Y3)
/Out5: J9.15, U9.16 (Y2)
/Out6: J9.18, U9.17 (Y1)
/Out7: J9.17, U9.18 (Y0)
/PH0: U12.3; also elsewhere on the board
/PH0#: U6.142 (IO2_142), U12.2
/PHI2: J9.28, U10.18 (Y0)
/PHI2_e: U6.124 (IO2_124), U10.2 (A0); also elsewhere on the board
/R0: J10.3, U8.12 (Y6)
/R0o: U6.31 (IO1_31), U8.8 (A6)
/R1: J10.2, U8.11 (Y7)
/R1o: U6.32 (IO1_32), U8.9 (A7)
/Res0: J7.6, U11.9 (A7)
/R/~W: J9.22, U10.13 (Y5)
/R/~W_e: U6.123 (IO2_123), U10.7 (A5); also elsewhere on the board
/VA0: J7.23, U5.53
/VA1: J7.24, U5.54
/VA2: J7.21, U5.55
/VA3: J7.22, U5.56
/VA4: J7.19, U5.58
/VA5: J7.20, U5.59
/VA6: J7.17, U5.60
/VA7: J7.18, U5.61
/VA8: J7.15, U5.63
/VA9: J7.16, U5.64
/VA10: J7.13, U5.65
/VA11: J7.14, U5.66
/VA12: J7.11, U5.67
/VA13: J7.12, U5.68
/VA14: J7.9, U5.70
/VA15: J7.10, U5.71
/VA16: J7.7, U5.72
/VA17: J7.8, U5.74
/VA18: J7.5, U5.76
/VCLK: J9.20, U10.11 (Y7)
/VCLK#: U6.143 (IO2_143), U10.9 (A7)
/VS: J7.31, U2.8 (A6)
/VSout: U6.23 (IO1_23), U8.2 (A0)
/VSync: J10.9, U8.18 (Y0)
/Y: C25.2, J9.29
/Y_out: J14.4, R6.2
/~BUSCLR: U6.74 (IO2_74); also elsewhere on the board
/~CE0: U6.75 (IO2_75), U10.8 (A6); also elsewhere on the board
/~CE1: U6.76 (IO2_76); also elsewhere on the board
/~CS: J9.19, U10.12 (Y6)
/~DOE: U1.22 (CE), U6.11 (IO1_11)
/~INT: J9.32
/~IORD: U10.4 (A2); also elsewhere on the board
/~IOWR: U10.3 (A1); also elsewhere on the board
/~MRD: U6.122 (IO2_122); also elsewhere on the board
/~MWR: U6.121 (IO2_121); also elsewhere on the board
/~OEH: U6.48 (IO1_48), U7.28 (~OE)
/~OEL: U3.28 (~OE), U6.72 (IO1_72)
/~OEM: U4.28 (~OE), U6.60 (IO1_60/DEV_OE)
/~PH0: U12.6; also elsewhere on the board
/~PH0#: U6.141 (IO2_141), U12.5
/~RD: J9.23, U10.16 (Y2)
/~RP: J7.32, U2.9 (A7)
/~RST: J9.25, U5.97, U6.110 (IO2_110); also elsewhere on the board
/~WEH: U6.37 (IO1_37), U7.12 (~WE)
/~WEL: U3.12 (~WE), U6.61 (IO1_61/DEV_CLRn)
/~WEM: U4.12 (~WE), U6.49 (IO1_49)
/~WR: J9.26, U10.17 (Y1)
GND: C1.2, C2.2, C3.2, C4.2, C5.2, C6.2, C7.2, C8.2, C9.2, C10.2, C11.2, C12.2, C13.2, C14.2, C15.2, C16.2, C17.2, C18.2, C19.2, C20.2, C21.2, C22.2, C23.2, C24.2, J6.2, J6.10, J7.33, J7.34, J8.2, J8.10, J9.1, J9.2, J10.1, J14.1, R1.2, R4.2, R5.2, R7.2, R10.2, U1.11 (GND), U1.12 (GND), U1.13 (GND), U2.1 (G1), U2.10 (GND), U2.19 (G2), U3.5 (~CE), U3.9 (GND), U3.25 (GND), U4.5 (~CE), U4.9 (GND), U4.25 (GND), U5.21 (GND), U5.31 (GND), U5.44 (GND), U5.62 (GND), U5.69 (GND), U5.75 (GND), U5.84 (GND), U5.100 (GND), U6.10 (GNDIO), U6.17 (GNDINT), U6.26 (GNDIO), U6.47 (GNDIO), U6.54 (GNDINT), U6.65 (GNDIO), U6.83 (GNDIO), U6.92 (GNDINT), U6.99 (GNDIO), U6.115 (GNDIO), U6.128 (GNDINT), U6.135 (GNDIO), U7.5 (~CE), U7.9 (GND), U7.25 (GND), U8.1 (G1), U8.10 (GND), U8.19 (G2), U9.1 (G1), U9.10 (GND), U9.19 (G2), U10.1 (G1), U10.10 (GND), U10.19 (G2), U11.1 (G1), U11.10 (GND), U11.19 (G2), U12.1, U12.4, U12.7 (GND); also elsewhere on the board
unnamed: J6.1, U6.35 (TCK)
unnamed: J6.3, U6.36 (TDO)
unnamed: J6.5, U6.33 (TMS)
unnamed: J6.9, U6.34 (TDI)
unnamed: J8.1, U5.48 (TCK)
unnamed: J8.3, U5.83 (TDO)
unnamed: J8.5, U5.47 (TMS)
unnamed: J8.9, U5.45 (TDI)
unnamed: J10.10, JP1.1 (A)
unnamed: J11.1, U11.2 (A0)
unnamed: J12.1, U11.3 (A1)
unnamed: J13.1, U11.4 (A2)
unnamed: J22.1, U12.9
unnamed: J23.1, U12.10
unnamed: J24.1, U12.8
unnamed: J25.1, U12.12
unnamed: J27.1, U12.13
unnamed: J28.1, U12.11
unnamed: C25.1, Q1.1 (B), R1.1, R2.2
unnamed: Q1.3 (C), Q2.1 (B), R3.2
unnamed: Q1.2 (E), R4.1
unnamed: C24.1, L1.2, Q2.3 (C), Q3.3 (C), Q4.3 (C), R2.1, R3.1
unnamed: Q2.2 (E), R5.1, R6.1
unnamed: Q3.1 (B), R8.2
unnamed: Q4.1 (B), R9.2

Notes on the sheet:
CGAR, CGAG, CGAB and CGAI are digital (CGA) RGB Inputs.
The difference between the SN74LVCC4245ANSR and the SN74LVCC3245BNSR is the switched 5V and 3V3 Rails.
CH0, A, B and Y are analog Signals!
Font ROM inside


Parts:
H1, H2, H3, H4: M3; MountingHole_3.2mm_M3
H5: Logo kicad; KiCad-Logo2_6mm_SilkScreen
H6: Logo Open Source Hardware; OSHW-Logo2_7.3x6mm_SilkScreen
J1, J2: BUS; PinSocket_2x20_P2.54mm_Vertical
J3, J4: Spare; PinSocket_2x20_P2.54mm_Vertical
J5: Conn_01x14; PinSocket_1x14_P2.54mm_Vertical
J26: Conn_01x02; PinSocket_1x02_P2.54mm_Vertical
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

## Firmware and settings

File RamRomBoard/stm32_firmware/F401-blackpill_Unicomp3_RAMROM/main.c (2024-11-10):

/*
    ChibiOS - Copyright (C) 2006..2018 Giovanni Di Sirio

    Licensed under the Apache License, Version 2.0 (the "License");
    you may not use this file except in compliance with the License.
    You may obtain a copy of the License at

        http://www.apache.org/licenses/LICENSE-2.0

    Unless required by applicable law or agreed to in writing, software
    distributed under the License is distributed on an "AS IS" BASIS,
    WITHOUT WARRANTIES OR CONDITIONS OF ANY KIND, either express or implied.
    See the License for the specific language governing permissions and
    limitations under the License.
*/
#include "main.h"
#include "ch.h"
#include "hal.h"
#include <string.h>
#include <stdlib.h>
#include "portab.h"
#include "shell.h"
#include "chprintf.h"
#include "sdcard.h"
#include "SPI.h"
#include "i2c.h"
#include "usbcfg.h"
#include "upload.h"
#include "comm.h"
#include "mypwm.h"
#include "ff.h"
#include "fs_helper.h"

//#define usb_lld_connect_bus(usbp)
//#define usb_lld_disconnect_bus(usbp)

extern THD_WORKING_AREA(waCharacterInputThread, 128);
extern THD_FUNCTION(CharacterInputThread, arg);
extern event_source_t inserted_event, removed_event;
extern bool fs_ready;
extern bool autorun;

/* Function prototypes needed as the two callbacks call each other.
   there is no way to order the callback without triggering an error. */
static void button_cb(void *arg);
static void vt_cb(virtual_timer_t *vtp, void *p);
static uint8_t is_pressed = 0, btn_cnt = 0;
/*===========================================================================*/
/* VT related code.                                                          */
/*===========================================================================*/
/* Virtual timer. */
static virtual_timer_t vt, vt2;
/* Callback of the virtual timer. */
static void vt_cb(virtual_timer_t *vtp, void *p) {
  (void)vtp;
  (void)p;
  chSysLockFromISR();
  /* Enabling the event and associating the callback. */
  if (is_pressed)
    palEnableLineEventI(EXTRST, PAL_EVENT_MODE_RISING_EDGE);
  else
    palEnableLineEventI(EXTRST, PAL_EVENT_MODE_FALLING_EDGE);
  palSetLineCallbackI(EXTRST, button_cb, NULL);
  chSysUnlockFromISR();
}

static void vt2_cb(virtual_timer_t *vtp, void *p) {
  (void)vtp;
  (void)p;
  chSysLockFromISR();
  if (btn_cnt < 2){
    TRESET_INACTIVE;
  }
  btn_cnt = 0;
  chSysUnlockFromISR();
}
/*===========================================================================*/
/* Button related code.                                                      */
/*===========================================================================*/
/* Callback associated to the raising edge of the button line. */
static void button_cb(void *arg) {
  (void)arg;
  //palToggleLine(LED);
  if (is_pressed){
    is_pressed = 0;
    btn_cnt++;
  }
  else{
    is_pressed = 1;
    TRESET_ACTIVE;
  }
  chSysLockFromISR();
  /* Disabling the event on the line and setting a timer to
     re-enable it. */
  palDisableLineEventI(EXTRST);
  /* Arming the VT timer to re-enable the event in 50ms. */
  chVTResetI(&vt);
  chVTDoSetI(&vt, TIME_MS2I(50), vt_cb, NULL);
  chVTResetI(&vt2);
  chVTDoSetI(&vt2, TIME_MS2I(300), vt2_cb, NULL);
  chSysUnlockFromISR();
}
/*===========================================================================*/
/* Command line related.                                                     */
/*===========================================================================*/
BaseSequentialStream *const shell = (BaseSequentialStream *)&SHELLPORT;
BaseSequentialStream *const ost = (BaseSequentialStream *)&OSTRICHPORT;
BaseSequentialStream *const dbg = (BaseSequentialStream *)&DEBUGPORT;

//#define SHELL_WA_SIZE   THD_WORKING_AREA_SIZE(2048)
static THD_WORKING_AREA(waShellThread, 2048);
static thread_t *shelltp = NULL;

char history_buffer[8*64];
char *completion_buffer[SHELL_MAX_COMPLETIONS];

static const ShellCommand commands[] = {
  {"xhelp",cmd_xhelp},
  {"rb", cmd_rb},
  {"wb", cmd_wb},
  {"fill", cmd_fill},
  {"br", cmd_br},
  {"freq", cmd_change_freq},
  {"dc", cmd_change_pw4},
  {"spi",cmd_spi},
  {"wc", cmd_wc},
  {"test",cmd_test},
  {"tree", cmd_tree},         // shows all files with directories
  {"create", cmd_create},     // creates binary file with n bytes
  {"cat", cmd_cat},           // dumps textfile
  {"cd", cmd_cd},             // changes directory
  {"mkdir", cmd_mkdir},       // creates directory
  {"rmdir", cmd_rmdir},       // removes directory
  {"mount", cmd_mount},       // mounts sd-card
  {"umount", cmd_umount},     // unmounts sd-card
  {"getlabel", cmd_getlabel}, // shows label of sd-card
  {"setlabel", cmd_setlabel}, // sets label of sd-card
  {"ls", cmd_dir},            // list directory
  {"pwd", cmd_pwd},           // prints current directory
  {"rm", cmd_rm},             // removes file
  {"mv", cmd_mv},             // moves or renames file
  {"free", cmd_free},         // shows bytes free on card
  {"exec", cmd_exec},         // executes a script
  {"kar", cmd_kar},           // runs autorun.sh once again  
  {NULL, NULL}
};
const ShellConfig shell_cfg1 = {
  (BaseSequentialStream *)&SHELLPORT,
  commands,
  history_buffer,
  sizeof(history_buffer),
  completion_buffer
};

/*
 * Shell exit event.
 */
static void ShellHandler(eventid_t id) {

  (void)id;
  if (chThdTerminatedX(shelltp)) {
    chThdRelease(shelltp);
    shelltp = NULL;
  }
}

//static const ShellCommand commands[] = {
//  {"test", cmd_test},
//  {NULL, NULL}
//};
//
//static const ShellConfig shell_cfg1 = {
//  (BaseSequentialStream *)&SHELLPORT,
//  commands
//};

/*
 * Green LED blinker thread, times are in milliseconds.
 */
//static THD_WORKING_AREA(waThread1, 128);
//static THD_FUNCTION(Thread1, arg) {
//
//  (void)arg;
//  chRegSetThreadName("blinker");
//  while (true) {
//    //palClearPad(GPIOA, 6);
//    chThdSleepMilliseconds(500);
//    //palSetPad(GPIOA, 6);
//    chThdSleepMilliseconds(500);
//  }
//}

/*
 * Application entry point.
 */
int main(void) {
  //thread_t *shelltp = NULL;
  //event_listener_t shell_el;
  static const evhandler_t evhndl[] = {
    InsertHandler,
    RemoveHandler,
    ShellHandler
    //     AutorunHandler
  };
  event_listener_t el0, el1, el2;
  /*
   * System initializations.
   * - HAL initialization, this also initializes the configured device drivers
   *   and performs the board-specific initializations.
   * - Kernel initialization, the main() function becomes a thread and the
   *   RTOS is active.
   */
  halInit();
  chSysInit();

  //PA2(TX) and PA3(RX) are routed to USART2
  SerialConfig serial_config6 = {
      //115200,
      115200,
      0,
      0,
      0
  };

  sdStart(&SHELLPORT, &serial_config6);
  palSetPadMode(GPIOA, 2, PAL_MODE_ALTERNATE(7));
  palSetPadMode(GPIOA, 3, PAL_MODE_ALTERNATE(7));

  chprintf(dbg, "\r\nUnicomp RAMROM: %i.%i \r\nSystem started. (Shell)\r\n", VMAJOR, VMINOR);
  //chprintf(ost, "\r\nNVRAM Programmer: %i.%i \r\nSystem started. (Ostrich)\r\nTest with 'VV' - should return 'N'", VMAJOR, VMINOR);

//  #ifdef OSTRICHUSB
  sduObjectInit(&OSTRICHPORT);
  sduStart(&OSTRICHPORT, &serusbcfg1);
//  palSetPadMode(GPIOA, 11, PAL_MODE_ALTERNATE(10));
//  palSetPadMode(GPIOA, 12, PAL_MODE_ALTERNATE(10));

  usbDisconnectBus(serusbcfg1.usbp);
  chThdSleepMilliseconds(1500);
  usbStart(serusbcfg1.usbp, &usbcfg);
  usbConnectBus(serusbcfg1.usbp);

  /* Initializing the virtual timer. */
  chVTObjectInit(&vt);
  chVTObjectInit(&vt2);
  /* Setting the button line as digital input without pull resistors. */
  palSetLineMode(EXTRST, PAL_MODE_INPUT);
  /* Enabling the event and associating the callback. */
  palEnableLineEvent(EXTRST, PAL_EVENT_MODE_FALLING_EDGE);
  palSetLineCallback(EXTRST, button_cb, NULL);
  sdcard_init();
  mypwmInit();
  SPI_init();
  i2c_init();
  start_upload_thread();
  /*
   * Shell manager initialization.
   * Event zero is shell exit.
   */
  shellInit();
  chThdCreateStatic(waShellThread, sizeof(waShellThread), NORMALPRIO+1, shellThread, (void *)&shell_cfg1);

  /* Normal main() thread activity, handling SD card events and shell
   * start
   * exit.
   */
  chEvtRegister(&inserted_event, &el0, 0);
  chEvtRegister(&removed_event, &el1, 1);
  chEvtRegister(&shell_terminated, &el2, 2);
  //   chEvtRegister(&autorun_terminated, &el3, 3);

  while (true) {
    chEvtDispatch(evhndl, chEvtWaitOneTimeout(ALL_EVENTS, TIME_MS2I(500)));
  }
}


//  chEvtRegister(&shell_terminated, &shell_el, 0);
  /*
   * Normal main() thread activity, in this demo it does nothing except
   * sleeping in a loop and check the button state.
   */
//  while (true) {
//#if USB_SHELL == 1
//    if (SHELLPORT.config->usbp->state == USB_ACTIVE) {
//      /* Starting shells.*/
//      if (shelltp == NULL) {
//        shelltp = chThdCreateFromHeap(NULL, SHELL_WA_SIZE,
//                                       "shell1", NORMALPRIO + 1,
//                                       shellThread, (void *)&shell_cfg1);
//      }
//#else
//    if (!shelltp)
//      shelltp = chThdCreateFromHeap(NULL, SHELL_WA_SIZE,
//                                    "shell", NORMALPRIO + 1,
//                                    shellThread, (void *)&shell_cfg1);
//    else if (chThdTerminatedX(shelltp)) {
//      chThdRelease(shelltp);    /* Recovers memory of the previous shell.   */
//      shelltp = NULL;           /* Triggers spawning of a new shell.        */
//    }
//#endif
//    /* Waiting for an exit event then freeing terminated shells.*/
//    chEvtWaitAny(EVENT_MASK(0));
//    if (chThdTerminatedX(shelltp)) {
//      chThdRelease(shelltp);
//      shelltp = NULL;
//    }
//  }
//  chThdSleepMilliseconds(1000);
////  palTogglePad(GPIOA, 5);
//}

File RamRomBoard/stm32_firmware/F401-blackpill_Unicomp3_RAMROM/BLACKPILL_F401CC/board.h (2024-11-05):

/*
    ChibiOS - Copyright (C) 2006..2020 Giovanni Di Sirio

    Licensed under the Apache License, Version 2.0 (the "License");
    you may not use this file except in compliance with the License.
    You may obtain a copy of the License at

        http://www.apache.org/licenses/LICENSE-2.0

    Unless required by applicable law or agreed to in writing, software
    distributed under the License is distributed on an "AS IS" BASIS,
    WITHOUT WARRANTIES OR CONDITIONS OF ANY KIND, either express or implied.
    See the License for the specific language governing permissions and
    limitations under the License.
*/

/*
 * This file has been automatically generated using ChibiStudio board
 * generator plugin. Do not edit manually.
 */

#ifndef BOARD_H
#define BOARD_H

/*===========================================================================*/
/* Driver constants.                                                         */
/*===========================================================================*/

/*
 * Setup for STM32 Blackpill-F401CE board.
 */

/*
 * Board identifier.
 */
#define BOARD_BLCKPILL_F401CC
#define BOARD_NAME                  "STM32 Blackpill-F401CC"

/*
 * Board oscillators-related settings.
 * NOTE: LSE not fitted.
 */
#if !defined(STM32_LSECLK)
#define STM32_LSECLK                0U
#endif

#if !defined(STM32_HSECLK)
#define STM32_HSECLK                25000000U
#endif

/*
 * Board voltages.
 * Required for performance limits calculation.
 */
#define STM32_VDD                   300U

/*
 * MCU type as defined in the ST header.
 */
#define STM32F401xC

/*
 * IO pins assignments.
 */
#define GPIOA_ARD_A0                0U
#define GPIOA_ADC1_IN0              0U
#define GPIOA_ARD_A1                1U
#define GPIOA_ADC1_IN1              1U
#define GPIOA_ARD_D1                2U
#define GPIOA_USART2_TX             2U
#define GPIOA_ARD_D0                3U
#define GPIOA_USART2_RX             3U
#define GPIOA_ARD_A2                4U
#define GPIOA_ADC1_IN4              4U
#define GPIOA_LED_GREEN             5U
#define GPIOA_ARD_D13               5U
#define GPIOA_ARD_D12               6U
#define GPIOA_ARD_D11               7U
#define GPIOA_ARD_D7                8U
#define GPIOA_ARD_D8                9U
#define GPIOA_ARD_D2                10U
#define GPIOA_OTG_FS_DM             11U
#define GPIOA_OTG_FS_DP             12U
#define GPIOA_SWDIO                 13U
#define GPIOA_SWCLK                 14U
#define GPIOA_PIN15                 15U

#define GPIOB_ARD_A3                0U
#define GPIOB_ADC1_IN8              0U
#define GPIOB_PIN1                  1U
#define GPIOB_PIN2                  2U
#define GPIOB_SWO                   3U
#define GPIOB_ARD_D3                3U
#define GPIOB_ARD_D5                4U
#define GPIOB_ARD_D4                5U
#define GPIOB_ARD_D10               6U
#define GPIOB_PIN7                  7U
#define GPIOB_ARD_D15               8U
#define GPIOB_ARD_D14               9U
#define GPIOB_ARD_D6                10U
#define GPIOB_PIN11                 11U
#define GPIOB_PIN12                 12U
#define GPIOB_PIN13                 13U
#define GPIOB_PIN14                 14U
#define GPIOB_PIN15                 15U

#define GPIOC_ARD_A5                0U
#define GPIOC_ADC1_IN10             0U
#define GPIOC_ARD_A4                1U
#define GPIOC_ADC1_IN11             1U
#define GPIOC_PIN2                  2U
#define GPIOC_PIN3                  3U
#define GPIOC_PIN4                  4U
#define GPIOC_PIN5                  5U
#define GPIOC_PIN6                  6U
#define GPIOC_ARD_D9                7U
#define GPIOC_PIN8                  8U
#define GPIOC_PIN9                  9U
#define GPIOC_PIN10                 10U
#define GPIOC_PIN11                 11U
#define GPIOC_PIN12                 12U
#define GPIOC_LED                   13U
#define GPIOC_OSC32_IN              14U
#define GPIOC_OSC32_OUT             15U

#define GPIOD_PIN0                  0U
#define GPIOD_PIN1                  1U
#define GPIOD_PIN2                  2U
#define GPIOD_PIN3                  3U
#define GPIOD_PIN4                  4U
#define GPIOD_PIN5                  5U
#define GPIOD_PIN6                  6U
#define GPIOD_PIN7                  7U
#define GPIOD_PIN8                  8U
#define GPIOD_PIN9                  9U
#define GPIOD_PIN10                 10U
#define GPIOD_PIN11                 11U
#define GPIOD_PIN12                 12U
#define GPIOD_PIN13                 13U
#define GPIOD_PIN14                 14U
#define GPIOD_PIN15                 15U
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

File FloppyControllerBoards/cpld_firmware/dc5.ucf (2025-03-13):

NET "nNMI"     LOC = "p1"  ;
NET "nINT"     LOC = "p2"  ;
NET "nDSKRDY"  LOC = "p3"  ;
NET "nDSEN"    LOC = "p5"  ;
NET "DSA"      LOC = "p6"  ;
NET "DSB"      LOC = "p7"  ;
NET "nSIDE1"   LOC = "p8"  ;
NET "MOTCP"    LOC = "p12"  ;
NET "nDSKCHG"  LOC = "p13"  ;
NET "nINTRQ"   LOC = "p14"  ;
NET "DRQ"      LOC = "p16"  ;
NET "nDDEN"    LOC = "p18"  ;
NET "nWG"      LOC = "p19"  ;
NET "MOTFDC"   LOC = "p20"  ;
NET "CLK1"     LOC = "p21"  ;
NET "HLT"      LOC = "p22"  ;
NET "FDCCLK"   LOC = "p23"  ;
NET "nCE0"     LOC = "p27"  ;
NET "RW"       LOC = "p28"  ;
NET "D[7]"     LOC = "p29"  ;
NET "D[6]"     LOC = "p30"  ;
NET "D[5]"     LOC = "p31"  ;
NET "D[4]"     LOC = "p32"  ;
NET "D[3]"     LOC = "p33"  ;
NET "D[2]"     LOC = "p34"  ;
NET "D[1]"     LOC = "p36"  ;
NET "D[0]"     LOC = "p37"  ;
NET "E"        LOC = "p38"  ;
NET "A3"       LOC = "p39"  ;
NET "nRST"     LOC = "p40"  ;
NET "HLD"      LOC = "p41"  ;
NET "nDOE"     LOC = "p42"  ;
NET "CLK8M"    LOC = "p43"  ;
NET "SSO"      LOC = "p44"  ;

# ; NET "GND" LOC = "p4"  ;
# ; NET "TDI" LOC = "p9"  ;
# ; NET "TMS" LOC = "p10" ;
# ; NET "TCK" LOC = "p11" ;
# ; NET "VCC" LOC = "p15" ;
# ; NET "GND" LOC = "p17" ;
# ; NET "TDO" LOC = "p24" ;
# ; NET "GND" LOC = "p25" ;
# ; NET "VCC" LOC = "p26" ;
# ; NET "VCC" LOC = "p35" ;

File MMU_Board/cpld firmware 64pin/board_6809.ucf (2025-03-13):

NET "PH0"      LOC = "p1"  ;
NET "nPH0"     LOC = "p2"  ;
NET "CLKF"     LOC = "p3"  ;
NET "nDOE"     LOC = "p31"  ;
NET "nAOE"     LOC = "p32"  ;
NET "nMWR"     LOC = "p33"  ;
NET "nMRD"     LOC = "p34"  ;
NET "RnW"      LOC = "p36"  ;
NET "E_C"      LOC = "p37"  ;
NET "Q_C"      LOC = "p38"  ;
NET "CLKCPU"   LOC = "p39"  ;
NET "nBUSFREE" LOC = "p43"  ;
NET "BA"       LOC = "p44"  ;
NET "nRST"     LOC = "p42"  ;

NET "A[0]"   LOC = "p30"  ;
NET "A[1]"   LOC = "p29"  ;
NET "A[2]"  LOC = "p28"  ;
NET "A[3]"  LOC = "p27"  ;
NET "A[4]"  LOC = "p23"  ;
NET "A[5]"  LOC = "p22"  ;
NET "A[6]"  LOC = "p21"  ;
NET "A[7]"  LOC = "p20"  ;
NET "A[8]"   LOC = "p19"  ;
NET "A[9]"   LOC = "p18"  ;
NET "A[10]"  LOC = "p16"  ;
NET "A[11]"  LOC = "p14"  ;
NET "A[12]"  LOC = "p13"  ;
NET "A[13]"  LOC = "p12"  ;
NET "A[14]"  LOC = "p8"  ;
NET "A[15]"  LOC = "p7"  ;

NET "RES0"  LOC = "p40"  ;
NET "RES1"  LOC = "p41"  ;

# ; NET "GND" LOC = "p4"  ;
# ; NET "TDI" LOC = "p9"  ;
# ; NET "TMS" LOC = "p10" ;
# ; NET "TCK" LOC = "p11" ;
# ; NET "VCC" LOC = "p15" ;
# ; NET "GND" LOC = "p17" ;
# ; NET "TDO" LOC = "p24" ;
# ; NET "GND" LOC = "p25" ;
# ; NET "VCC" LOC = "p26" ;
# ; NET "VCC" LOC = "p35" ;

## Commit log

2024-05-27 Readme update
    [RamRomBoard.kicad_pcb, RamRomBoard.kicad_sch]
2024-05-29 cpld examples update
    [RamRomBoard.kicad_pcb, RamRomBoard.kicad_sch]
2024-06-10 New XC9572 Example
    [RamRomBoard.kicad_pcb, RamRomBoard.kicad_sch, bus.kicad_sch]
2024-09-26 Schematics of RAMROM Board updated
    [RamRomBoard-B_Cu.gbr, RamRomBoard-B_Mask.gbr, RamRomBoard-B_Paste.gbr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]
2024-09-30 Diodes on Databus added, DS1314 different footprint
    [RamRomBoard-B_Cu.gbr, RamRomBoard-B_Mask.gbr, RamRomBoard-B_Paste.gbr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]
2024-10-12 many new boards
    [6303X_FP64-B_Cu.gbr, 6303X_FP64-B_Mask.gbr, 6303X_FP64-B_Paste.gbr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]
2024-10-24 first boards manufactured
    [6502_6800_CPU.kicad_pcb, 6502_6800_CPU.kicad_sch, 6809_CPU.kicad_pcb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]
2024-11-05 first boards done, start of coding
    [RamRomBoard-B_Cu.gbr, RamRomBoard-B_Mask.gbr, RamRomBoard-B_Paste.gbr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]
2024-11-06 new vhdl code
    [6502_6800_CPU-B_Cu.gbr, 6502_6800_CPU-B_Mask.gbr, 6502_6800_CPU-B_Paste.gbr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]
2024-11-07 computer configs added, python script in progress
    [6801reader.cfg, Pinnumbers Bus v3.ods, apple1.cfg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]
2024-11-09 doku. improved, python script in progress
    [example.cfg, kim1.cfg]
2024-11-10 working ram upload
    [UploadProtocolDescription.ods, kim1.cfg]
2025-03-13 graphic updates
    [6502_6800_CPU.kicad_sch, 6801reader.cfg, 6809_CPU.kicad_sch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]
